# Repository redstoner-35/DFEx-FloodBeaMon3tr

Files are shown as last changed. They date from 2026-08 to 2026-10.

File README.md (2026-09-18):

powered by 35's Embedded Systems Inc. An Open-Source High Power Flood FlashLight Solution                                                                                                                        

### 概述

欢迎来到由Redstoner_35所开发的新一代高功率全恒流泛光手电**DFEX GT-X2,aka. DFEx-FloodBeaMon3tr**的完整设计开源仓库。DFEX GT-X2是基于全新的XTR HyperBoost HV GaN超高能效氮化镓升压恒流驱动所实现的大型手电参考设计。该手电作为低压增强型氮化镓功率器件在手电行业的首次应用，提供了以往硅基MOSFET方案无法企及的性能和功率密度。该手电方案具备行业首个基于氮化镓功率管的全恒流双相交错升压驱动，配合定制的超高光效灯珠，在21.5cm总长 10cm头径的娇小体型内提供高达 **162050LM光通 580K坎德拉光强** 的峰值出光性能，并且只需四节21700电池即可驱动。手电同时标配超低内阻的免工具可换电池电池架，内置140W双向充电方案。用户可以随心所欲地更换电池从而在户外实现极强的续航。并且该电池架具备行业主流的手电电池组方案所缺失的高级BMS功能和大电流主动均衡，使得电池子系统即使在用户可换电池和极高充放电倍率的条件下仍然能保障安全和稳定运行，电池子系统会通过其内置的BMS前端自动完成电池一致性管理，并允许用户随时查询电池的运行状况。这意味着用户可以装入电池后将手电当成电池棒手电全程不拆电池使用，并通过内置的140W快充模块在45分钟内完成快速充电（四节鹏辉能源60Q 84Wh的0-100%充电时间41分钟）。标配的高速风扇手柄DLC可以实现高达45000LM的持续常亮性能，提供无与伦比的常亮输出。

### 手电物理参数

+ 手电尺寸：21.5cm总长，10cm头径（未包括风扇手柄）
+ 手电重量：2070克（未包含风扇把手DLC） / 2355克（包含风扇把手DLC）
+ 电池组件：标配内置BMS和高性能主动均衡的电池架。用户可换电芯无需任何工具。
+ 电池架对电芯的需求：四节一致性良好的21700尺寸圆柱三元锂全极耳动力电芯。需具备至少100A的带温控截止放电能力（对于电芯的选择，请参考下方内容）。
+ 充放电方式：内置140W PD3.1/PD3.0多协议双向充放电子系统。该子系统支持标准和非标准PD3.0 Fix和PPS，以及PD3.1 EPR和AVS。用户也可拆下电池充电。

#### 出光性能（使用8032P Gen2）

+ Power模式极亮：25℃冷态OTF *162050LM光通 580K坎德拉光强* 持续1分钟,ANSI标准值 144965LM
+ ECO模式极亮：25℃冷态OTF *103100LM光通 410K坎德拉光强* 持续2分钟,ANSI标准值 98500LM

#### 出光性能（使用8032P Gen1）

+ Power模式极亮：25℃冷态OTF *153600LM光通 520K坎德拉光强* 持续1分钟,ANSI标准值 135360LM
+ ECO模式极亮：25℃冷态OTF *98500LM光通 390K坎德拉光强* 持续2分钟,ANSI标准值 95800LM

### 成品效果多视图

手电左侧视图
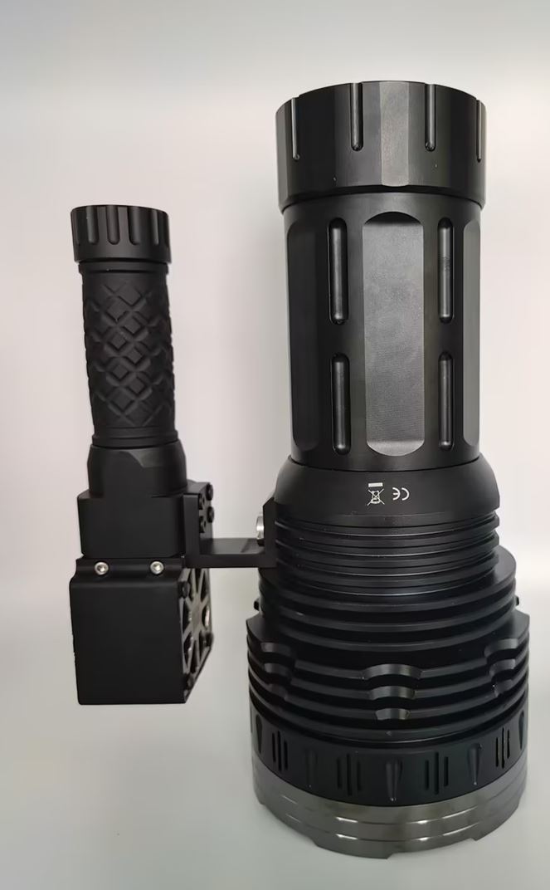
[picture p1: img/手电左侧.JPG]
成品侧面


手电按钮处正面视图
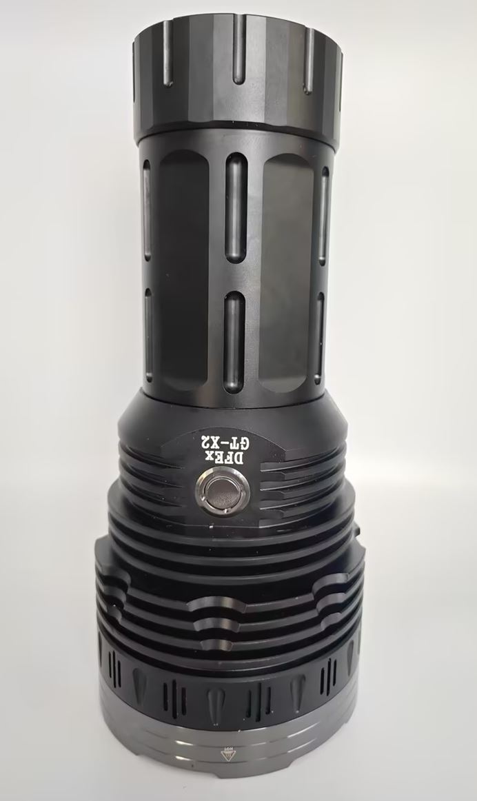
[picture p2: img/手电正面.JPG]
成品正面


手电头部正视图
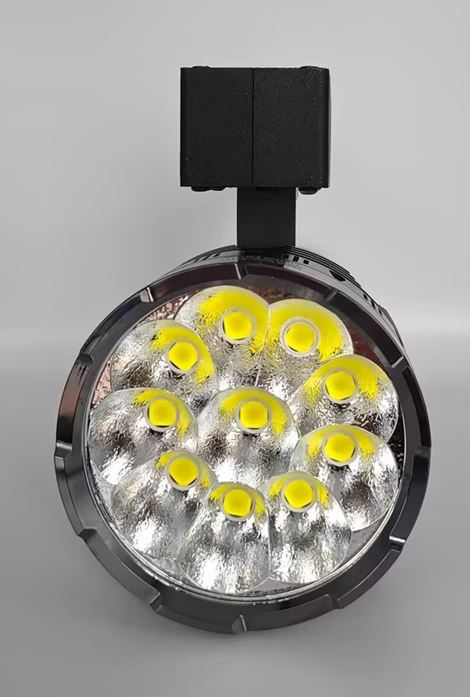
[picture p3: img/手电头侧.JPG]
手电灯珠侧正面


手电尾部视图
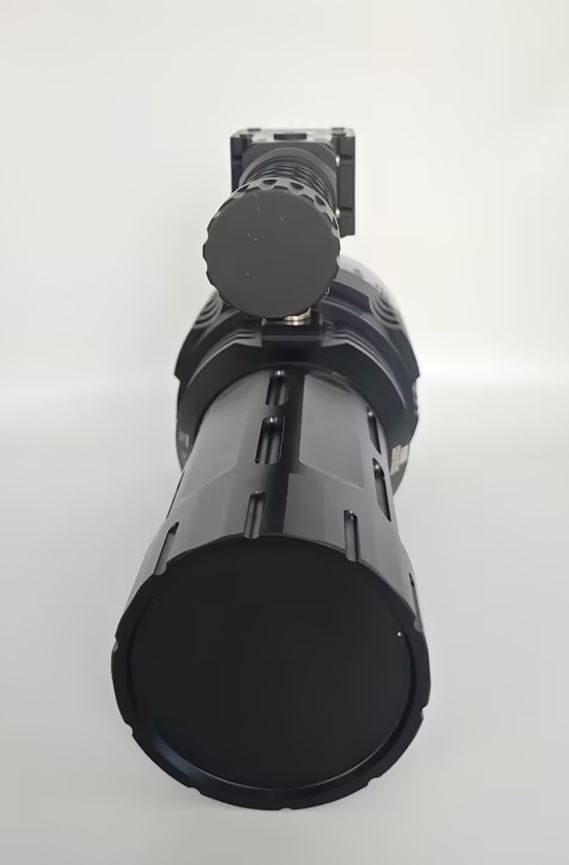
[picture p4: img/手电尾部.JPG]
手电尾部


### 复刻成本

该手电方案的从0开始复刻的成本极高。因此作者本人开源该项目的初衷是提供一个具有用户可换电池+大功率快充+全恒流超高能效驱动的手电设计参考作为抛砖引玉，期望行业上可以基于该设计作为范本诞生更多具有设计感和独创性的大型手电设计。如果您一定需要尝试复刻，那1PCS大致的复刻成本如下：

+ 机械部件部分：大约3000至4000元
+ 光学系统部分（包括反射器、玻璃等）：约500-1000元
+ 电子电路部分（包含驱动和电池架所有PCB和元器件）：约6000元
+ LED部分（包含定制灯珠打样和配套铜基板等）：5000元

### UI逻辑

为了降低UI学习成本，该手电总体的UI操作逻辑和上一代产品（也就是DFEx-GT96）基本保持一致。您可查看项目文件夹中的[UI逻辑手册](./GT-X2_UI%E9%80%BB%E8%BE%91.pdf)以查看主驱动的UI逻辑。并且该系统的电池组件加入了电池BMS功能，为了保证用户体验，强烈建议您阅读项目文件夹中的[BMS操作手册](./GT-X2_BMS%E9%80%BB%E8%BE%91.pdf)。

### 续航参数

在该手电方案发布前，作者已完成两台样机的试制并完成完整的续航测试，几乎覆盖所有挡位。对于该手电的完整续航数据和充电性能数据，您可查看项目中的[续航总表数据](GT-X2%E7%BB%AD%E8%88%AA%E6%B5%8B%E8%AF%95%E6%80%BB%E8%A1%A8.xlsx)。由于数据量巨大，因此readme中不再赘述。

### 复刻时电池的选择

这个手电的电池在工作过程中需要承受巨大的电流。在Power模式极亮的时候，电池最高电流可达105-110A。虽然固件具备有自适应输入MPPT算法，但是使用容量型或者半动力型电芯仍然可能会导致电芯出现不可逆的性能下降甚至损坏！因此为了保证您的安全，我仅推荐使用如下的电芯：

+ 鹏辉能源60Q：6000mAh超高倍率全极耳，也是作者在完成续航测试全过程时所使用的电池。
+ 新能安JP50P2：5000mAh版本的JP40，具有极强的放电能力，在牺牲了续航的前提下换来了更高的寿命。
+ 天鹏50XG：5000mAh超高倍率动力电池的标杆。
+ 天鹏40XG：支持90A持续放电，虽然续航惨不忍睹但是胜在便宜量大管饱。续航不够就多带电池。

### 风扇手柄DLC的说明

#### 风扇手柄操作逻辑

该风扇手柄DLC自身具备独立的操作按钮和系统,允许用户根据需要调整输出功率。风扇手柄本身包含自己的驱动和电池，不占用手电本身电池的电力和驱动面积。对于完整的操作逻辑，您可查看风扇手柄固件文件夹内的[风扇手柄操作说明](/%E5%9B%BA%E4%BB%B6/%E9%A3%8E%E6%89%87%E6%89%8B%E6%9F%84%E5%9B%BA%E4%BB%B6/Fan_Readme.md)。同时，为了实现极致的高常亮，作者在2026年9月3日的版本更新提供了43000RPM的超暴力风扇把手。该把手采用单锂升压设计，支持51W的超级风扇。为了实现如此高的输出功率，作者提供了全新的风扇驱动，操作逻辑和旧版略有修改。您克查看新版本风扇手柄固件文件夹内的[新版本风扇手柄操作说明](/%E5%9B%BA%E4%BB%B6/%E7%A6%81%E8%B5%9B%E7%BA%A7%E9%A3%8E%E6%89%87%E6%89%8B%E6%9F%84%E5%9B%BA%E4%BB%B6%E6%BA%90%E7%A0%81/Fan_Readme.md)。

#### 风扇手柄参数简介

相比于最初的版本，目前的工程文件已经包含了基于[东东海F1A的风扇手柄套件](https://item.taobao.com/item.htm?id=962803427853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)所实现的风扇手柄DLC。该风扇手柄通过专用的铝合金固定件连接至手电本体，具有极高的强度。风扇手柄外观如下图所示：

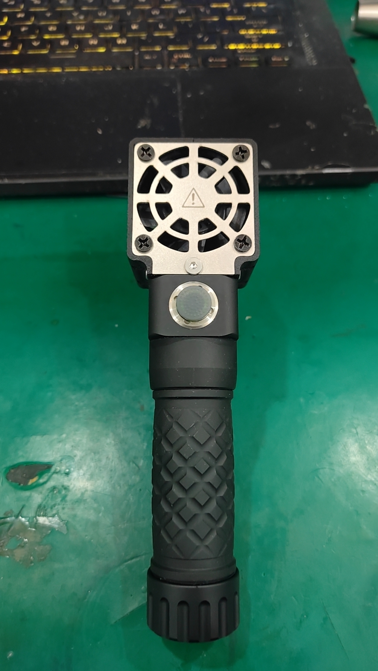
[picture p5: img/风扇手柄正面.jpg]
风扇手柄正面

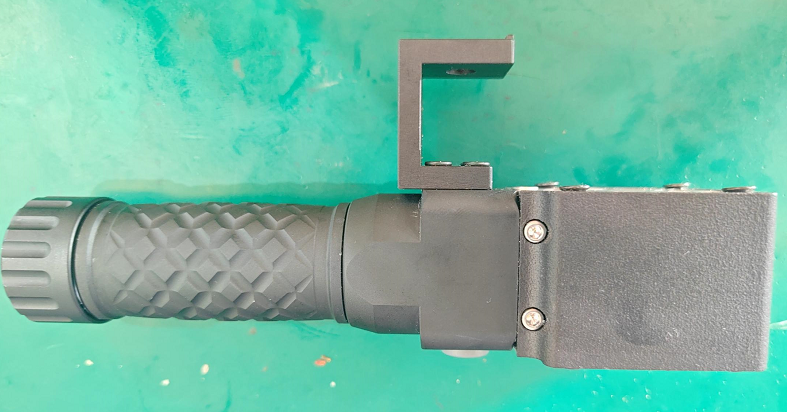
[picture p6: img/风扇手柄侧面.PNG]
风扇手柄侧面


该风扇手柄DLC基于自主开发的单锂升压12V风扇专用驱动以及单锂双向充电板，手柄样机所标配的风扇为建准的XF40281BX-Q035-S9H。转速高达34000RPM可以实现4.5万LM常亮不降档（2026年9月3日新增43000RPM的超暴力风扇手柄，吹称200克，支持5万常亮）。同时该风扇手柄的电池仓为免拆电池充电设计，旋下电池仓即可露出内置的双向USB-TypeC充电接口：

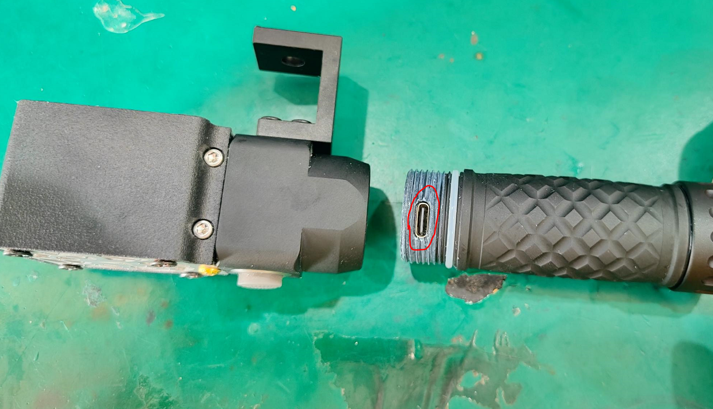
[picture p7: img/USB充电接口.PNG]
USB充电接口


该充电接口支持双向5V 2.4A充放电。最高12W的输入或输出功率。除了能给风扇手柄充电以外在应急情况下还可以反向为手机或其他设备应急充电。拆下手柄后即可看到手柄电池仓正面的充放指示灯：

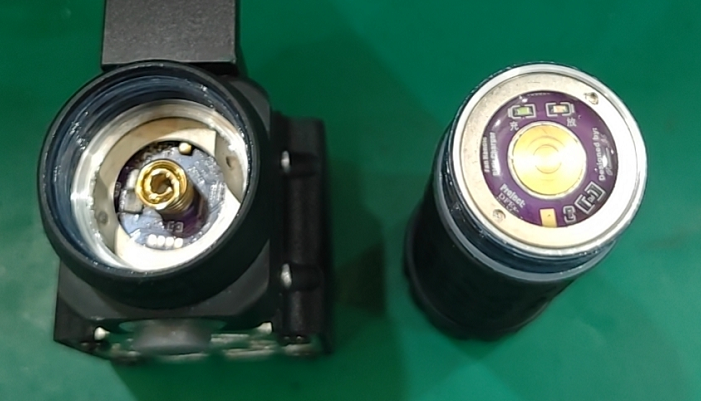
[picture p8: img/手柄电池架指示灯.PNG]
正面指示灯位置


手柄的电池仓一共包含两个指示灯，其中一个为放电和电池电量指示灯（图中紫色并且以放字标识的LED）以及一个充电状态指示灯（图中黄色以充字标识）负责指示电池的充放电状态。当电池仓首次装入电池时，电量指示灯会1Hz慢闪四秒表示电池安装后系统处于激活锁定模式。此时C口不能对外放电，需要连接充电器充电后才可放电。这两个指示灯不会同时点亮，显示的逻辑如下：

+ 充电指示灯：正在充电时0.5Hz慢闪，充满后持续点亮
+ 放电和电量指示灯：正在放电且电量正常时常亮，正在放电且电量不足后1Hz慢闪（充电或者放电结束拔下线缆后，电量指示灯仍然会保持点亮或闪烁一段时间，用户无需理会。30秒后电量指示灯会自然熄灭）

该风扇手柄采用专门的操作逻辑设计，和手电的原始UI基本一致，操作逻辑请参考如下内容：

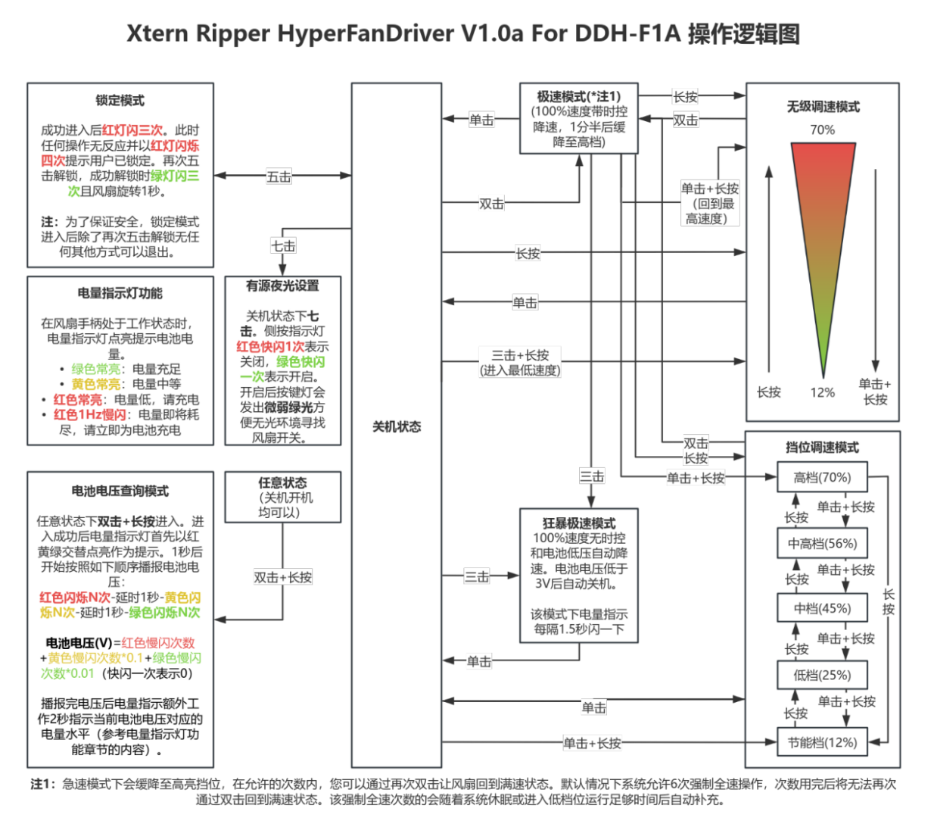
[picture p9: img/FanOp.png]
风扇手柄操作


#### 风扇手柄复刻说明

该风扇手柄复刻所需要的电路和机械部分已经在工程文件中体现，用户可以根据需要自行准备物料并复刻。对于部分未说明的物料请参考如下内容：

+ 风扇手柄半成品：该配件由东东海销售，可在[东东海淘宝店](https://item.taobao.com/item.htm?id=962803427853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)购买。
+ 风扇本体固定用粗牙螺丝：KB4*10规格，可在[固恒紧固件天猫店](https://detail.tmall.com/item.htm?id=610787499293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)购买.
+ 风扇固定装饰外壳和手柄壳料的固定螺丝：定制M3*6头径4.5非标内六角螺丝，可在[深奥普淘宝店](https://item.taobao.com/item.htm?id=770645615127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)购买
+ 4028暴力风扇：作者推荐使用建准的XF40281BX-Q035-S9H超高速暴力风扇获得足够的风量。该风扇可在[小红散热风扇](https://item.taobao.com/item.htm?id=959825954576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)淘宝店购买。

对于其余的机械部分物料，则参考如下说明：

+ 正背面风扇网罩不锈钢片：参考机械部分的[3D模型](/%E6%9C%BA%E6%A2%B0/%E9%A3%8E%E6%89%87%E6%89%8B%E6%9F%84%E5%A4%96%E6%A1%86/Step/40%E9%A3%8E%E6%89%87%E4%B8%8D%E9%94%88%E9%92%A2%E5%A4%B9%E7%89%87-%E6%94%B9%E7%89%88.STEP)找不锈钢加工厂进行处理。使用1mm 304不锈钢片激光切割后去毛刺抛光，并喷砂处理。
+ 风扇和手柄之间的固定壳：参考机械部分的[外部固定壳模型](/%E6%9C%BA%E6%A2%B0/%E9%A3%8E%E6%89%87%E6%89%8B%E6%9F%84%E5%A4%96%E6%A1%86/Step/40%E9%A3%8E%E6%89%87%E5%A4%96%E6%A1%8623%E6%97%A5.STEP)找3D打印商家进行处理。因该部件型面较为复杂因此建议选用PA6材质进行SLS激光烧结或MJF工艺等无需支撑的工艺制程进行3D打印。

电子部分的物料和具体打样文件（如PCB等）您可以参考PCB文件夹内相关的子目录并进行打样。

### 工程结构

该开源手电项目的工程分为三个文件夹，分别放置手电的电子、机械和固件部分的原始资料：

+ PCB：该文件夹放置手电所有功能模块的电路板文件
+ 固件：该文件夹放置手电种各个功能模块所使用到的固件文件
+ 机械：该文件夹放置手电外壳、电池架等东西的机械建模文件

### 复刻的详细指导

因为该项目仍处于刚刚完成的状态，相关文档的编写仍在进行中。对于需要注意的部分以及供应商链接您可以参考每个子文件夹内的注意事项文档。对于您在复刻中不明白的部分，您可使用Github issue。如果需要了解该手电方案的设计记录全过程，您可前往BLF论坛中作者本人攥写的[记录帖子](https://budgetlightforum.com/t/fully-regulated-flood-search-light-build-dfex-gt-x2-open-source-wip/234458)以获得部分组装过程的照片和流程并作为复刻的参考。

### 致谢

该项目于今年四月初启动，持续了近五个月。所有的电子部分的电路设计、电池机架的整体结构、部分外壳设计、完整的性能和续航测试，以及光学部分（如LED）的设计和与相关供应商的协调均由作者独立完成（redstoner_35）。在这个过程中，我得到了几位重要朋友和家人的经济和精神支持，在我濒临放弃时给予了帮助。我非常感谢**KIPA、思绪和我的家人**给予的精神和经济支持，也感谢[飘落396](https://space.bilibili.com/694332529?spm_id_from=333.337.0.0)在CNC供应商寻找对接沟通和外壳结构设计方面的支持。这种支持是确保该项目持续推进和最终成功的关键力量。与此同时，作为一名DIY爱好者，我一直致力于挑战自己的能力极限并努力实现高质量的顶级解决方案，并致力于令顶尖方案从研发端走入千家万户。因此，作者本人将该项目的所有生产资料开源于本仓库，并希望有厂商可以基于此方案提供实际的产品。

----------------------------------------------------------------------------------------------------------------------------------
© redstoner_35 @ 35's Embedded Systems Inc.  2026

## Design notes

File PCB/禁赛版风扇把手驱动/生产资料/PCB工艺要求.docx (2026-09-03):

板厚：1.6mm

层数：4层

外形层：请以Keepout Layer（PCB1_keep-out.gbr文件）内的轮廓作为外形层！

外层线路铜厚：2Oz

内层线路铜厚：1Oz （铜厚不能缩水否则发热大！达不到标称性能！有钱的话内层也2Oz性能最好）

阻焊颜色：蓝色

丝印颜色：白色 （颜色你想咋样都行，这里是参考值）

焊盘喷镀：2U沉金（外圈存在导电接触不能喷锡，否则接触不良！！）

阻焊覆盖：过孔塞树脂+电镀盖帽（不能过孔盖油，否则焊接不良！！）

板材TG值：155

层压顺序需要选择指定层压顺序，请勿更改！层压顺序需要严格按照如下要求进行！

L1（顶层线路）：PCB1_copper_signal_top.gbr

L2（中间层线路1）：PCB1_copper_plane_1.gbr

L3（中间层线路2）：PCB1_copper_signal_1.gbr

L4（底层线路）：PCB1_copper_signal_bot.gbr

该PCB对层压结构没有要求，按照嘉立创（JLCPCB）对应板厚和铜厚随机指定的默认的层压结构就可以了。

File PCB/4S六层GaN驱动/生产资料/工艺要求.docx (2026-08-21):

板厚：1.6mm

层数：6层

外形层：请以Keepout Layer（pcb2_keepout.gbr文件）内的轮廓作为外形层！

外层线路铜厚：2Oz

内层线路铜厚：2Oz （铜厚不能缩水否则发热大）

阻焊颜色：蓝色

丝印颜色：白色 （颜色你想咋样都行，这里是参考值）

焊盘喷镀：2U沉金 （必须这么厚否则容易接触不良！）

阻焊覆盖：过孔塞树脂+表面电镀填平（JLC六层默认工艺，不需要加钱）

板材TG值：170

板材供应商要求：生益 （高温和高弹力条件下运行，必须TG170高品质板材否则驱动PCB会变形导致功能异常）

层压顺序需要选择指定层压顺序，请勿更改！层压顺序需要严格按照如下要求进行！

L1（顶层线路）：pcb2_copper_signal_top.gbr

L2（中间层线路1）：pcb2_copper_plane_1.gbr

L3（中间层线路2）：pcb2_copper_signal_1.gbr

L4（中间层线路3）：pcb2_copper_signal_2.gbr

L5（中间层线路4）：pcb2_copper_plane_2.gbr

L6（底层线路）：pcb2_copper_signal_bot.gbr

层压顺序错误（特别是内层）会引起严重的信号干扰和噪声问题导致驱动炸机！务必确认生产稿检查内层顺序！！

该PCB对层压结构没有要求，按照嘉立创（JLCPCB）对应板厚和铜厚随机指定的默认的层压结构就可以了

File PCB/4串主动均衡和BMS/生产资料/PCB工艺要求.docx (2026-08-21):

板厚：1.0mm （别搞错了！）

层数：4层

外形层：请以Keepout Layer（pcb1_keep-out.gbr文件）内的轮廓作为外形层！

外层线路铜厚：1Oz

内层线路铜厚：1Oz （铜厚不能缩水否则发热大）

阻焊颜色：绿色

丝印颜色：白色 （颜色你想咋样都行，这里是参考值）

焊盘喷镀：没钱就喷锡，有钱就1U沉金，丰俭由人

阻焊覆盖：过孔盖油

板材TG值：155

层压顺序需要选择指定层压顺序，请勿更改！层压顺序需要严格按照如下要求进行！

L1（顶层线路）：pcb1_copper_signal_top.gbr

L2（中间层线路1）：pcb1_copper_plane_1.gbr

L3（中间层线路2）：pcb1_copper_signal_1.gbr

L4（底层线路）：pcb1_copper_signal_bot.gbr

该PCB对层压结构没有要求，按照嘉立创（JLCPCB）对应板厚和铜厚随机指定的默认的层压结构就可以了

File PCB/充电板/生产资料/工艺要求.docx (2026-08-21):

板厚：1.2mm

层数：4层

外形层：请以Keepout Layer（PCB1_Keep-out.gbr文件）内的轮廓作为外形层！

外层线路铜厚：1Oz

内层线路铜厚：1Oz （铜厚不能缩水否则发热大）

阻焊颜色：绿色

丝印颜色：白色 （颜色你想咋样都行，这里是参考值）

焊盘喷镀：没钱就喷锡，有钱就1U沉金，丰俭由人

阻焊覆盖：过孔盖油

板材TG值：135

层压顺序需要选择指定层压顺序，请勿更改！层压顺序需要严格按照如下要求进行！

L1（顶层线路）：PCB2_Copper_Signal_Top.gbr

L2（中间层线路1）：PCB2_Copper_Plane_1.gbr

L3（中间层线路2）：PCB2_Copper_Signal_1.gbr

L4（底层线路）：PCB2_Copper_Signal_Bot.gbr

该PCB对层压结构没有要求，按照嘉立创（JLCPCB）对应板厚和铜厚随机指定的默认的层压结构就可以了

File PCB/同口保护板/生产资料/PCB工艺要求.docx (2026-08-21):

板厚：1.6mm

层数：4层

外形层：请以Keepout Layer（PCB1_Keep-out.gbr文件）内的轮廓作为外形层！

外层线路铜厚：2Oz

内层线路铜厚：2Oz （超大电流，铜厚不能缩水否则发热巨大没法用）

阻焊颜色：蓝色

丝印颜色：白色 （颜色你想咋样都行，这里是参考值）

焊盘喷镀：没钱就喷锡，有钱就1U沉金，丰俭由人

阻焊覆盖：过孔塞树脂+电镀盖帽

板材TG值：155

层压顺序需要选择指定层压顺序，请勿更改！层压顺序需要严格按照如下要求进行！

L1（顶层线路）：PCB1_Copper_Signal_Top.gbr

L2（中间层线路1）：PCB1_Copper_Plane_1.gbr

L3（中间层线路2）：PCB1_Copper_Signal_1.gbr

L4（底层线路）：PCB1_Copper_Signal_Bot.gbr

该PCB对层压结构没有要求，按照嘉立创（JLCPCB）对应板厚和铜厚随机指定的默认的层压结构就可以了

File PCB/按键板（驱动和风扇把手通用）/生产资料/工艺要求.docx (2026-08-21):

板厚：1.0mm

层数：2层

外形层：请以Keepout Layer（PCB3_Keep-out.gbr文件）内的轮廓作为外形层！

线路铜厚：1Oz

阻焊颜色：白色

丝印颜色：黑色 （建议使用白油黑字，自带反光效果增强按键灯亮度）

焊盘喷镀：喷锡就可以

阻焊覆盖：过孔盖油

板材TG值：135

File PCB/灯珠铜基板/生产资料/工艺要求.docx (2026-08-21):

## 铜基板总体工艺要求

线路层铜厚：6Oz

成品板厚：3mm

阻焊层颜色：黑色

丝印层颜色：白色

焊盘喷镀：1U沉金

特殊工艺要求：下图中绿色圈起的固定螺丝孔做喇叭孔。

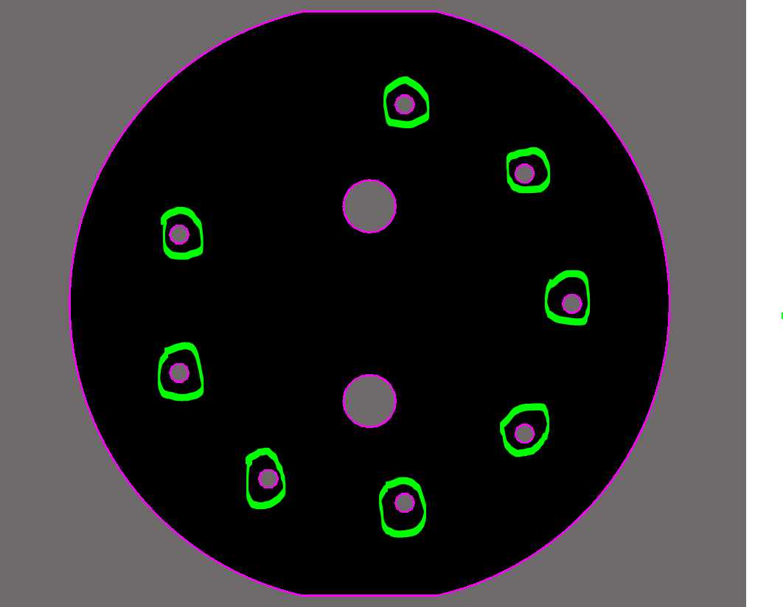
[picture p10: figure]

喇叭孔参数如下：

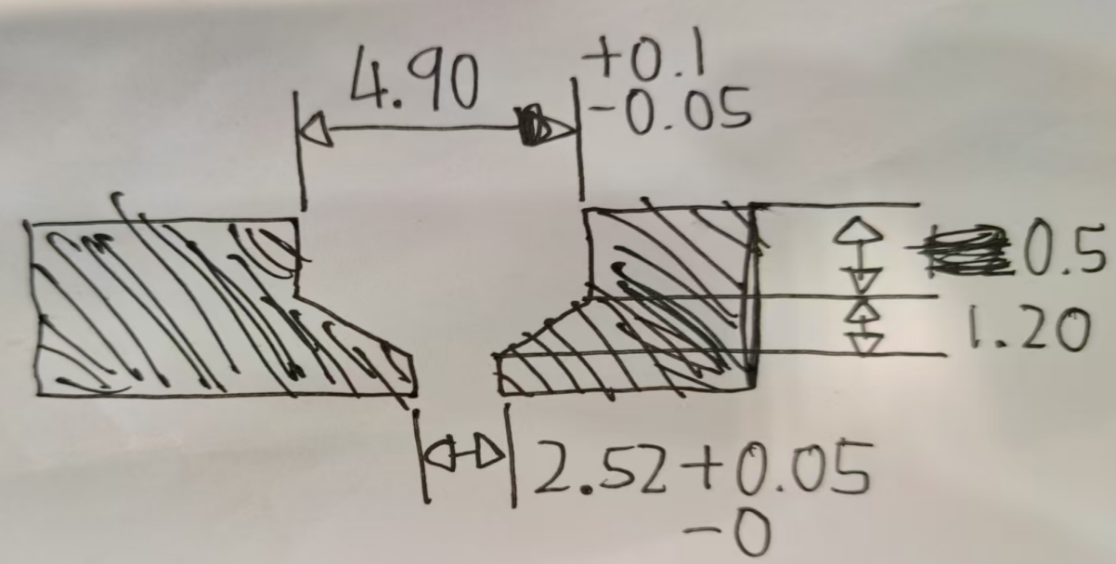
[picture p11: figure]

生产拼板位：请注意使用下图所示的拼板位置进行拼板，不得破坏其他区域的外形否则基板无法安装至外壳内。

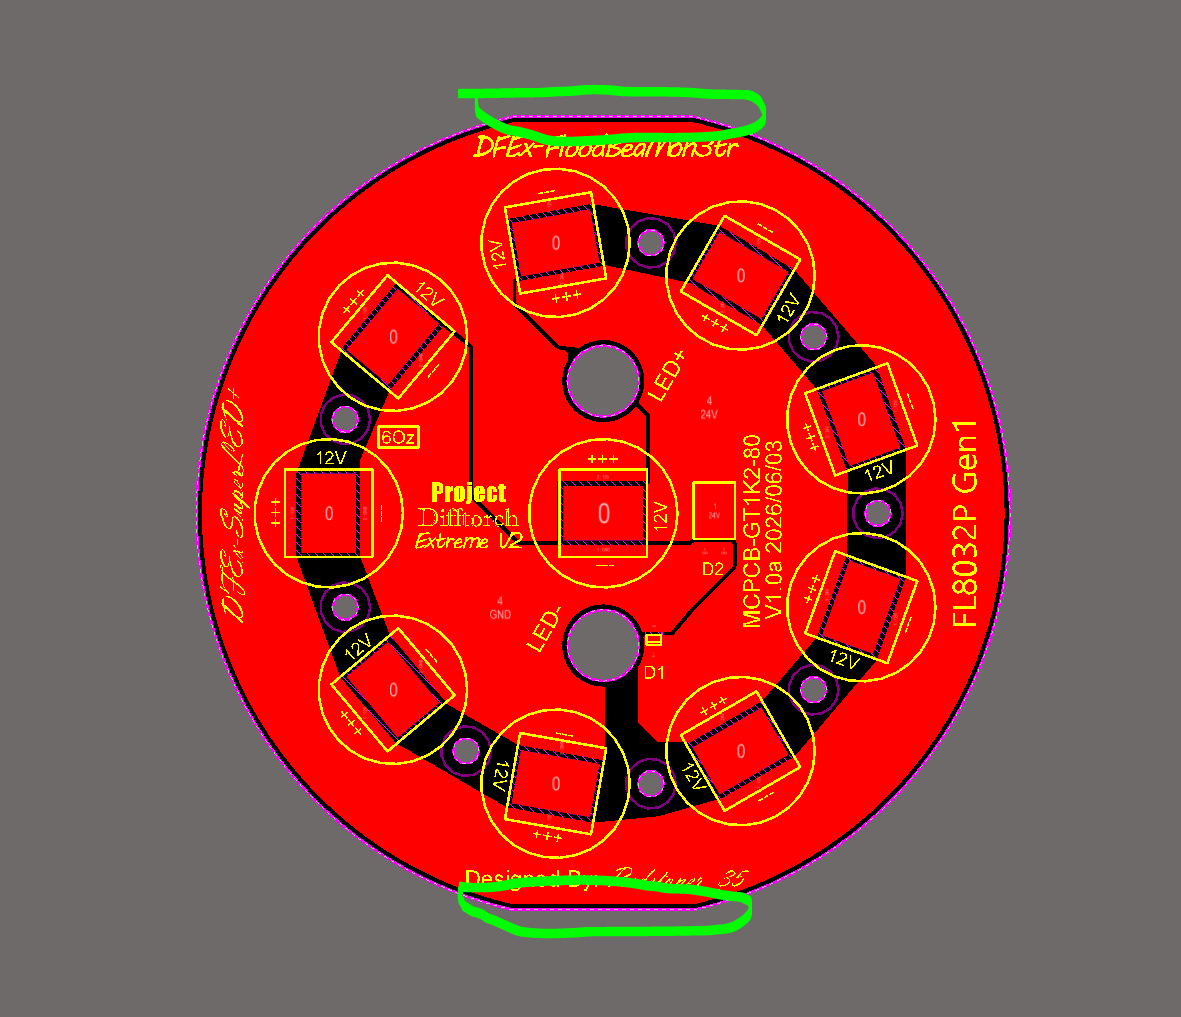
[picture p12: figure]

基板耐温和环保要求：基板材料应符合RoHs标准，可以承受1次标准无铅高温锡膏的红外回流焊过程，阻焊层不得脱落，线路层和铜基层不得分层。

参考拼板方式如下图：

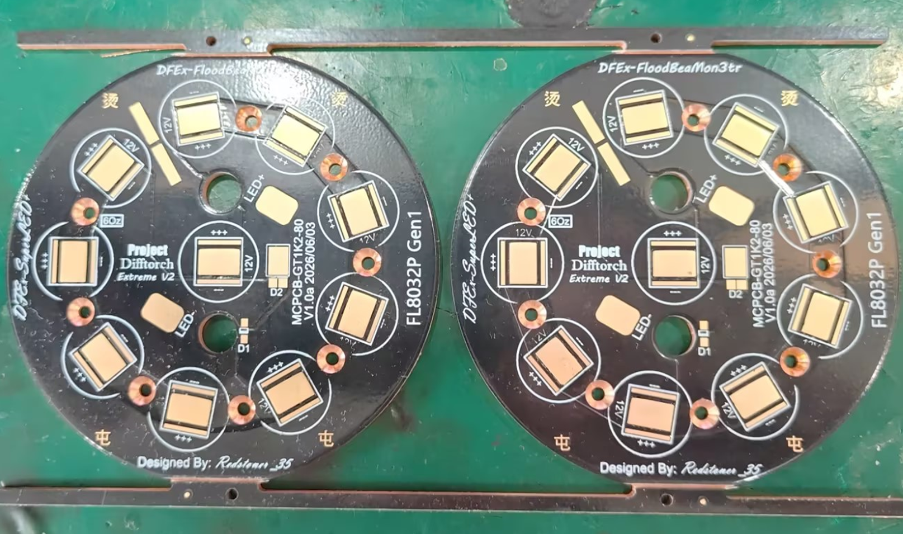
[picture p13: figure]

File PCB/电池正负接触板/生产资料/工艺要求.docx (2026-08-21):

板厚：1.6mm

层数：2层

总拼板款数：2款

每款板PCS数：2PCS

是否包含工艺边：是

拼板方式：V-CUT

拼板VCUT标识层：请以Mechanical 3层（电池接触板拼板_Mechanical_3.gbr）所标识的V-CUT线作为切割起始点！

外形层：请以Keepout Layer（电池接触板拼板_Keep-out.gbr文件）内的轮廓作为外形层！

线路铜厚：5Oz （有钱建议6Oz损耗更低，5Oz最低）

阻焊颜色：蓝色

丝印颜色：白色 （颜色你想咋样都行，这里是参考值）

焊盘喷镀：没钱就喷锡，有钱就1U沉金，丰俭由人

阻焊覆盖：过孔盖油

板材TG值：至少155

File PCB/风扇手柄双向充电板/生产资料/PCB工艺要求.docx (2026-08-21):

板厚：1.6mm

层数：4层

外形层：请以Keepout Layer（PCB1_Keep-out.gbr文件）内的轮廓作为外形层！

外层线路铜厚：1Oz

内层线路铜厚：0.5Oz （内层0.5Oz就够，当然你有钱的话1Oz最好）

阻焊颜色：黑色

丝印颜色：白色 （颜色你想咋样都行，这里是参考值）

焊盘喷镀：至少1U沉金，最好2U否则接触不良

阻焊覆盖：过孔塞树脂+电镀盖帽

板材TG值：135

层压顺序需要选择指定层压顺序，请勿更改！层压顺序需要严格按照如下要求进行！

L1（顶层线路）：PCB1_Copper_Signal_Top.gbr

L2（中间层线路1）：PCB1_Copper_Plane_1.gbr

L3（中间层线路2）：PCB1_Copper_Signal_1.gbr

L4（底层线路）：PCB1_Copper_Signal_Bot.gbr

该PCB对层压结构没有要求，按照嘉立创（JLCPCB）对应板厚和铜厚随机指定的默认的层压结构就可以了

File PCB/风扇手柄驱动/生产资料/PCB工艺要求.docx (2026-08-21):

板厚：1.6mm

层数：4层

外形层：请以Keepout Layer（PCB2_Keep-out.gbr文件）内的轮廓作为外形层！

外层线路铜厚：1Oz

内层线路铜厚：1Oz （内层不能缩水）

阻焊颜色：黑色

丝印颜色：白色 （颜色你想咋样都行，这里是参考值）

焊盘喷镀：至少1U沉金，最好2U否则接触不良

阻焊覆盖：过孔塞树脂+电镀盖帽

板材TG值：155

层压顺序需要选择指定层压顺序，请勿更改！层压顺序需要严格按照如下要求进行！

L1（顶层线路）：PCB2_Copper_Signal_Top.gbr

L2（中间层线路1）：PCB2_Copper_Plane_1.gbr

L3（中间层线路2）：PCB2_Copper_Signal_1.gbr

L4（底层线路）：PCB2_Copper_Signal_Bot.gbr

该PCB对层压结构没有要求，按照嘉立创（JLCPCB）对应板厚和铜厚随机指定的默认的层压结构就可以了

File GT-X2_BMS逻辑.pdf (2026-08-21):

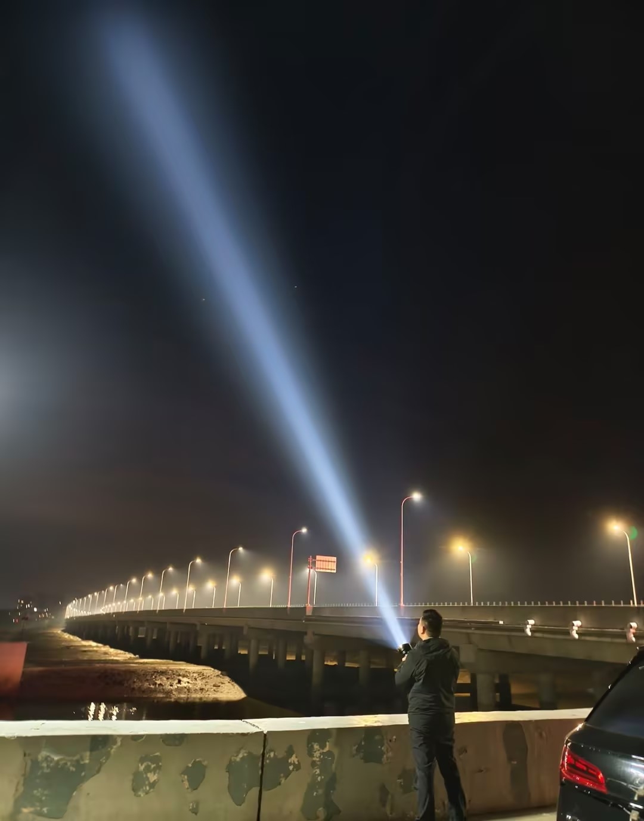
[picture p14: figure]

# DFEx-GTX2 高功率泛光搜索手电

# 电池架 S-BMS 操作手册

## 由 redstoner_35 编写 仅供参考

## BMS 基础操作

## 电池棒操作界面

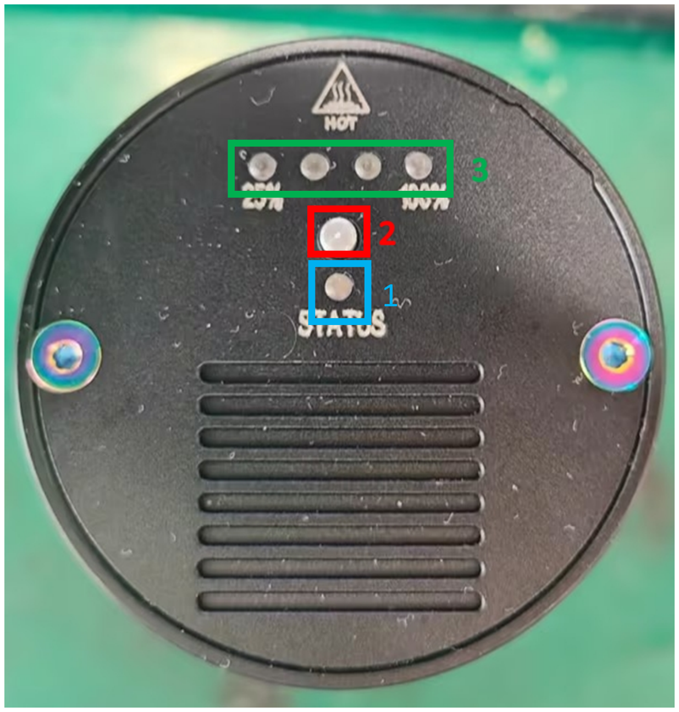
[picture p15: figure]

电池棒操作界面的各个部分的功能如下所示：

序号 | 部件名称 | 功能
1 | BMS 状态指示灯 | 在充放电时亮起指示电池当前的健康状况，并且在用户操 作时按照逻辑播报如电池总电压、指定电池的电压、电池 压差和一致性、电池和 BMS 温度等电池健康状况数据。
2 | BMS 操作按钮 | 允许用户唤醒 BMS 以及充放电系统，并且执行 BMS 相关的 查询和设置操作。同时，在安装了电池后，该按钮提供电 池激活功能以解锁保护板，允许保护板对外输出。
3 | 电池电量和充放 电状态指示灯 | 该组指示灯在充放电阶段提供充放电状态的指示，以及电 池电量的指示。当充放电系统存在异常时，四盏指示灯将 同时闪烁。

## 唤醒 BMS 和充放电系统

为了节省电力，BMS 默认处于非活动状态。此时充放电系统和 BMS 模块处 于深度休眠，仅消耗极少的电力。若用户需要查询电池状态或需要对外放电，可 以通过单击 BMS 操作按钮，唤醒 BMS 和充放电系统。在按下按钮后，BMS 将会 由休眠转为活动状态，在通过了自检后点亮 BMS 状态灯，等候用户操作。 同时，该系统具备自动唤醒功能。当用户连接 USB-C 线缆尝试为手电的电池 进行充电以及连接到手机/笔记本电脑等支持 OTG 的设备尝试用手电为其供电时， BMS 将立即自动唤醒进入工作状态，并且开启充放电功能。 需要注意的是，若您连接的被供电设备（如小风扇）不支持 OTG 功能，则连 接 USB 线缆后，设备将保持在睡眠状态且 BMS 和对外放电系统关闭。此时您需 要手动单击 BMS 按键以唤醒充放电功能。

## BMS 上电自检和自检故障排除

为了保证 BMS 自身的正确性，在 BMS 被唤醒（无论是用户手动唤醒还是由充放电事件 自动唤醒）后，BMS 首先会对自身进行上电自我测试和初始化。初始化结束后才会进入用 户模式。若初始化出现异常以及检测到电池存在问题，则会通过在 BMS 指示灯上显示指定 的序列以提示用户。指示灯序列提示如下：

指示灯序列 | 故障类型 | 可能出现的问题 | 用户应采取的操作
红色 8Hz 快 闪 | 严重 | BMS 主处理器无法正确初始化采 集模拟前端或出现通信故障 | 长按 BMS 按键 1 秒，观察问 题是否重现。若重现请送修。
黄色 8Hz 快 闪 | 严重 | BMS 主处理器无法采集到电池内 部温度信息，可能是热敏电阻损坏 或模拟前端故障引起。 | 检查电池是否过度压迫电池 架中部的 NTC 热敏电阻。长 按 BMS 按键 1 秒，观察问题 是否重现。若重现请送修。
黄色慢速闪 烁一定次数 后红色慢闪 几秒最后熄 灭，熄灭后 不再亮起 | 警告 | BMS 初始化成功，但检测到某节 电池电压异常过低，因此进入关机 保护状态。该问题可能是电池架中 某节电池接触不良、装反或损坏引 起。 | 闪烁次数表示电压异常的电 池所在的位置。请取下电池 并擦干净电池架的触点，检 查电池的极性和电压后以正 确的方式装回。若仍未解决， 请送修。
红黄绿或绿 黄红的交替 闪烁，然后 跟着一大堆 看不明白的 慢闪 | 警告 | BMS 初始化成功且通过自检，但 检测到电池架上的电池一致性极 差，存在巨大的电压差。因此 BMS 发出一致性警告，提醒您需要查看 并处理电池的一致性故障。 | 该组闪烁的内容和后续章节 中关于电池一致性查看的内 容完全一致。请参考后续章 节定位故障电池。

若 BMS 正常通过自检且没有警告发生，此时 BMS 的状态灯将短暂点亮，并指示电池一 致性状况，同时电池电量指示灯组也将点亮，表示充放电系统已就绪，您可以开始对电池进 行充电或放电。

## BMS 指示灯状态表（通过自检后）

在通过自检后，BMS 将进入正常工作模式，此时 BMS 的状态指示灯将通过颜色和状态 指示当前电池的一致性以及 BMS 所处的状态。在 BMS 待机、充放电中以及均衡中，系统会 通过指示灯颜色指示电池一致性，关于一致性的指示如下：

指示灯颜色 | 电池一致性状况
绿色 | 电池一致性不错（压差小于 40mV）
黄色 | 电池一致性一般（压差在 40-150mV 之间）
红色 | 电池一致性极差（压差大于 200mV）此时需要人为干预。

同时，BMS 会通过指示灯的闪烁、常亮等方式以及带颜色的特殊闪烁指示 BMS 的状态：

指示灯颜色 | 指示灯闪烁状态 | 系统当前状态
参考上表 | 每 5 秒闪一下 | BMS 处于待机状态，主动均衡和充放电系统处于关闭状态， 将持续监控电池状况并等待用户操作和充放电输入。
参考上表 | 1Hz 慢闪 | BMS 处于活动状态。此时 BMS 正在运行主动均衡以修正电 池一致性误差。
参考上表 | 常亮 | BMS 处于活动状态，系统正在进行充放电中，未启动主动 均衡。
红色 | 4Hz 快闪 | BMS 检测到持续的通信超时。经过多次重试仍无法和 AFE 进行通信，此时将进入故障保护模式。
黄色 | 4Hz 快闪 | BMS 检测到温度采集系统故障。经过多次重试仍无法正确 获取温度信息，已进入保护模式。
黄色 | 每 5 秒 快 闪 三 下，循环 | BMS 进入过充保护模式，由于电池一致性太差导致充电时 单体出现过度充电。此时 BMS 将禁止充电并强制启动均衡 以释放并转移过度充电的电池中的能量。
红色 | 每 5 秒 快 闪 三 下，循环 | BMS 进入过温或或低温充放电保护模式。由于电池本身温 度过高或过低，BMS 将禁止充放电。请等待电池回归到正 常温度后故障将自动解除。
绿色 | 每 5 秒 快 闪 三 下，循环 | 因为用户操作，BMS 进入受用户指令的禁充禁放模式。此 时单击 BMS 按键即可退出用户禁充模式并恢复正常充放 电。

## 充放电系统指示灯状态表

该电池架包含四个用于指示系统充放电状态的指示灯。该组指示灯除了指示电池的大概 电量外，还负责指示充放电系统的运行状况。对于当前系统的电池电量，在待机以及放电状 态，充放电系统会通过指示灯点亮的个数显示大致的电池电量，指示规则如下：

25%指示灯 | 50%指示灯 | 75%指示灯 | 100%指示灯 | 电池电量
快闪 | 灭 | 灭 | 灭 | 小于 10%，接近耗尽
亮 | 灭 | 灭 | 灭 | 10%至 25%之间
亮 | 亮 | 灭 | 灭 | 25%至 50%之间
亮 | 亮 | 亮 | 灭 | 50%至 75%之间
亮 | 亮 | 亮 | 亮 | 75%到 100%之间

若系统的充电功能处于活动状态，以及进入故障、处于休眠等特殊状态，系统会通过指 示灯闪烁和常亮的方式指示当前处于的状态。指示规则可以查看下表：

25%指示灯 | 50%指示灯 | 75%指示灯 | 100%指示灯 | 系统状态
灭 | 灭 | 灭 | 灭 | 充放电系统休眠中，您 可单击 BMS 按键唤醒
1Hz 慢闪 | 灭 | 灭 | 灭 | 系统充电中，当前电量 0-25%
亮 | 1Hz 慢闪 | 灭 | 灭 | 系统充电中，当前电量 25-50%
亮 | 亮 | 1Hz 慢闪 | 灭 | 系统充电中，当前电量 50-75%
亮 | 亮 | 亮 | 1Hz 慢闪 | 系统充电中，当前电量 75-100%
亮 | 亮 | 亮 | 亮 | 系统已充满，请尽快拔 下充电线。
2Hz 快闪 | 2Hz 快闪 | 2Hz 快闪 | 2Hz 快闪 | 由于 BMS 检测到异常 状态，充放电系统已被 禁用。请查看 BMS 状态 指示灯以了解问题的原

# 因。 关闭 BMS

该 BMS 具备自动关机功能，当 BMS 处于非活动状态（没有均衡和充放电操作）超过 1 分钟后，BMS 将会自动关机以节约电力。同时如果 BMS 检测到电池架中有某节电池电压过 低，为了避免电池过度放电，BMS 也会强制关机，并且用红色慢闪若干次作为提示。 若您需要手动关闭 BMS，请在充放电系统指示灯熄灭后长按 BMS 按键 2 秒，此时 BMS 指示灯将以黄色快闪三下，然后 BMS 将返回深度休眠状态，几乎不消耗电力。

## BMS 电池健康查询操作

## 查询操作下电池电量水平的指示

- 绿色常亮：电池电量充足
- 黄色常亮：电池电量较为充足
- 红色常亮：电池电量不足，请尽快充电
- 红色慢闪：电池电量严重不足，请立即充电（此时手电的可用挡位和功能将会被限制）

## 查询电池总电压

BMS 在待机状态下双击进入。当进入电量查询模式后 BMS 指示灯首先将会以红黄绿依 次点亮的方式（若电池电压低于 10.00V，则系统将会切换到高精度显示模式以 0.01V 精度 显示电量。此时先导提示将变为绿黄红的顺序）作为先导提示，提示用户即将开始显示电 池电压和电量。延迟 1 秒后将通过红色，黄色和绿色的指定次数的慢速闪烁（如果快速闪烁 一次，则表示该数据位为 0）提示用户当前的电池电压，播报完电池当前电压后，BMS 将会 在延迟 2 秒后通过后续的长亮(或者慢闪)提示用户当前电池电压对应的总体电量水平(参考 本条目第一小节的内容)，对于电池具体电压播报的计算方式请参考如下内容：

- 99.9V显示模式：红色闪烁次数x10+黄色闪烁次数+绿色闪烁次数x0.1=当前电池电压(V)， 例如 红色慢闪 1 次-黄色快闪 1 次-绿色慢闪 4 次 表示电池电压为 10x1+0+4x0.1=10.4V。
- 9.99V 高精度显示模式：红色闪烁次数+黄色闪烁次数 x0.1+绿色闪烁次数 x0.01=当前电 池电压(V)，例如 红色慢闪 8 次-黄色慢闪 1 次-绿色慢闪 3 次 表示当前电池电压为

## 8+1*0.1+3x0.01=8.13V。 查询电池内部温度

BMS 在待机状态下三击进入。当进入温度查询模式后 BMS 指示灯首先将会以红黄绿依 次点亮的方式（若手电当前处于极寒环境，手电本身温度低于 0 摄氏度时，先导提示将变 为绿黄红的顺序）作为先导提示，提示用户即将开始显示当前电池的温度。延迟 1 秒后 BMS 将通过红色和黄色的指定次数的慢速闪烁（如果快速闪烁一次，则表示该数据位为 0）提示 用户当前的电池内部温度。在播报完当前电池的内部温度数值后，BMS 将会在延迟 2 秒后 通过后续的长亮(或者慢闪)提示用户当前内部温度数值所对应的电池温度情况。对于温度显 示的计算方式请参考如下内容：

- 播报完毕后绿色常亮：当前电池温度良好
- 播报完毕后黄色常亮：当前电池温度较高，需要注意散热
- 播报完毕后红色常亮：当前电池温度极高，请立即为电池降温以避免危险
- 电池内部温度(℃)=红色闪烁次数 x10+黄色闪烁次数，例如`红色慢闪 4 次-黄色快闪 1 次 `表示当前电池的温度为 40℃

## 查询 BMS 板端的温度

BMS 在待机状态下六击进入。当进入温度查询模式后 BMS 指示灯首先将会以红黄绿依 次点亮的方式（若手电当前处于极寒环境，手电本身温度低于 0 摄氏度时，先导提示将变 为绿黄红的顺序）作为先导提示，提示用户即将开始显示当前电池的温度。延迟 1 秒后 BMS 将通过红色和黄色的指定次数的慢速闪烁（如果快速闪烁一次，则表示该数据位为 0）提示 用户当前的 BMS 板端的温度。在播报完当前 BMS 板端的温度数值后，BMS 将会在延迟 2 秒 后通过后续的长亮(或者慢闪)提示用户当前 BMS 板端温度数值所对应的 BMS 温度情况。对 于温度显示的计算方式请参考如下内容：

- 播报完毕后绿色常亮：当前 BMS 温度良好
- 播报完毕后黄色常亮：当前 BMS 温度较高，需要注意散热
- 播报完毕后红色常亮：当前 BMS 温度极高，需要风扇主动为电池架顶部散热改善 BMS 的温度
- BMS 板端的温度(℃)=红色闪烁次数 x10+黄色闪烁次数，例如`红色慢闪 5 次-黄色快闪 1 次`表示当前 BMS 板端的温度为 50℃

## 查询单节电芯的电压

BMS 在待机状态下通过指定次数的连续多击，并在多击后紧跟一次 2 秒以上的长按进 入，例如连续四次单击后立即长按 2 秒表示查询电池架上第四节电池的电量和电压。 当成功进入单体电量查询模式后 BMS 指示灯首先将会以绿黄红依次点亮的方式作为先 导提示，提示用户即将开始显示该电池的电压和电量。延迟 1 秒后将通过红色，黄色和绿色 的指定次数的慢速闪烁（如果快速闪烁一次，则表示该数据位为 0）提示用户当前的电池电 压，播报完电池当前电压后，BMS 将会在延迟 2 秒后通过后续的长亮(或者慢闪)提示用户当 前单体电池电压对应的电量水平(参考本条目第一小节的内容)，对于单体电池具体电压播报 的计算方式请参考如下内容：

- 红色闪烁次数+黄色闪烁次数 x0.1+绿色闪烁次数 x0.01=当前电池电压(V)，例如 红色慢 闪 4 次-黄色慢闪 1 次-绿色慢闪 3 次 表示当前电池电压为 4+1*0.1+3x0.01=4.13V。 查询电池组的精确压差

该 BMS 具备电池一致性状况播报功能。该播报功能除了可以手动唤起外，当 BMS 上电 自检期间，如果检测到压差极大则会自动在自检结束后唤起播报作为警告。该警告机制会提 醒您电池一致性存在严重问题，这通常是由于电池组内某一节电芯已严重衰减，濒临崩溃导 致。若警告出现，您需要尽快处理以避免其余正常的电芯更进一步被故障电芯牵连而损坏。

对于在 BMS 操作状态下手动进入，则需要在 BMS 在待机状态下四击 BMS 按钮进入。 当成功进入一致性查询环节后，BMS 指示灯首先将会以红黄绿依次点亮的方式（若当前电 池的一致性太差，压差超过 999mV，则先导提示将变为绿黄红的顺序）作为先导提示，提 示用户即将开始显示当前电池组的一致性状况。延迟 1 秒，BMS 后将通过红色，黄色和绿 色的指定次数的慢速闪烁（如果快速闪烁一次，则表示该数据位为 0）提示用户当前的电池 压差。对于压差的计算可以参考如下内容：

- 999mV 显示模式（先导提示为红黄绿）：红色闪烁次数 x100+黄色闪烁次数 x10+绿色闪 烁次数=当前电池最大的压差(mV)，例如 红色慢闪 1 次-黄色快闪 1 次-绿色慢闪 4 次 表 示电池当前最大压差（电压最高和最低的电池之间）为 100x1+0x10+4=104mV。
- 9.99V 显示模式（先导提示为绿黄红）：红色闪烁次数+黄色闪烁次数 x0.1+绿色闪烁次 数 x0.01=当前电池压差(V)，例如 红色慢闪 2 次-黄色慢闪 1 次-绿色慢闪 3 次 表示电池

## 当前最大压差（电压最高和最低的电池之间）为 2+1*0.1+3x0.01=2.13V=2130mV。

播报完电池当前的最大压差后，BMS 将会在延迟 2 秒后通过后续的长亮(或者慢闪)提示 用户当前电池的压差对应的电池健康度水平，参考如下内容：

- 播报完毕后绿色常亮：当前电池的一致性极好，可以安全使用
- 播报完毕后黄色常亮：当前电池的一致性一般，可以继续使用，但建议人工进行一致性 干预（如手动均衡等）
- 播报完毕后红色常亮：当前电池的一致性很差，不建议继续使用，需要尽快进行一致性 干预（如手动启动均衡等）
- 播报完毕后红色慢闪：当前电池的一致性极差，严禁继续使用。需要拆下电芯检查电芯 是否存在故障，并更换故障电芯。更换电芯后需要立即手动进行均衡。

如果 BMS 检测到当前电池一致性非常良好，也就是一致性播报为绿灯时，播报将会直 接结束，此时 BMS 返回正常运行状态。如果电池一致性一般，则 BMS 将会继续播报流程， 并额外播报当前压差最大，也就是一致性最差的电池所在的位置以方便您查询该电池的单体 电压并采取后续操作。播报的方式是延迟 2 秒后，通过指定次数的黄色慢闪，提示您异常 的电池所在的位置。
例如在播报结束的末尾，BMS 指示灯以黄色慢闪三次，表示 BMS 检测到电池架内第三 节电池（BATT3）的压差最高，您可以对该故障电池进行更换或手动均衡以修正电压差。 查询电池组的一致性状况

在 BMS 处于非活动状态下，为了减少电力消耗，BMS 状态指示灯会改为每隔 5 秒固定 点亮一下以指示电池状况。若您需要立即查看当前电池的一致性状况，您可单击 BMS 按键 一次。此时 BMS 将会短暂点亮 BMS 状态指示灯以同步显示电池健康状况，约 4 秒后 BMS 将返回非活动状态并熄灭 BMS 指示灯。需要注意的是，此操作将会同步唤醒充放电系统。

## BMS 充放电系统命令操作

## 手动唤醒充放电系统

即使在 BMS 处于正常工作的状态下，充放电系统也会自动进入休眠以节约电力。若您 需要手动唤醒充放电系统，您可单击 BMS 按键一次。此时 BMS 将会立即发送指令唤醒充放 电系统。此时充放电系统的指示灯将亮起。 强制执行保护板激活

由于 BMS 的供电线路为独立供电，单独绕过保护板故即使保护板处于保护状态，BMS 也能正常工作。若保护板处于保护模式，此时将会出现充放电系统指示灯无反应，不充不放 且手电筒点不亮按下按键无任何反应的故障。此时您可以七击 BMS 按键令 BMS 强制执行保 护板激活程序，此时 BMS 指示灯将会以绿色快闪三次作为提示。当成功激活后，充放电管 理系统的指示灯将会点亮。 强制重置充放电子系统

有时候充放电管理系统的 SoC 会因自身固件缺陷导致死机，或者出现异常行为（例如快 充不握手、不充不放、指示灯异常、充电时反复重启等）此时您可以八击 BMS 按键。BMS 将会以指示灯绿色快闪三次作为收到命令的提示，然后 BMS 将会发送充放电 SoC 重置指令 强制复位 SoC 以修复 SoC 死机引起的充放电异常。 手动禁止充放电

BMS 提供了在特定情况下手动禁止充放电的功能。在 BMS 处于待机状态下，连续快速 单击 BMS 按键六次，并在第六次单击结束后立即再长按两秒，即可令 BMS 进入禁止充放的 模式。此时充放电管理系统将被禁用，无法为电池充电和对外放电。 处于禁充模式后，BMS 指示灯将会通过每 5 秒钟以绿色快速闪烁三次并反复循环的方 式作为提示。若您需要退出该模式，则单击 BMS 按键一次即可。

## 主动均衡系统说明和特殊操作

该电池子系统的 BMS 具备主动均衡控制功能。依托 BMS 主板集成的变压器大电流主动 均衡，可以在出现较大一致性误差时快速进行能量转移以缩小电池的一致性误差。BMS 内 置的算法会根据电池一致性误差和单节电池的电压，自动执行三段式均衡（涓流-恒流-恒压） 过程以尽快修复一致性问题。 自动强制均衡

每次上电自检期间，BMS 都会自动检测电池的一致性状况。当 BMS 检测到一致性过差， 需要主动均衡介入时，系统将会立即启动强制均衡过程。该均衡过程无法取消，且 BMS 会 在均衡结束之前一直保持活动状态，直到一致性被均衡修复至极好的水平（小于 40mV）。 自动均衡过程和手动均衡过程都会令 BMS 指示灯处于慢闪状态作为提示。若自动均衡处于 运行状态，用户无法轻易取消且此时 BMS 会拒绝接收手动关机命令。 于此同时，如果电池一致性过差并且用户无视警告强制给电池充电，导致电池出现单体 过充时 BMS 也会进入过充保护模式，禁用充电功能并强制启用均衡。当均衡器将压差缩小 至一致性一般但可以继续充电的水平时，充电将会恢复。 在压差较小时取消自动均衡

为了方便用户特殊情况的需要，在系统的最大压差被修正到小于 160mV 的时候，用户 可以强制结束本次自动均衡。结束自动均衡的方法是连续快速单击 BMS 按键五次，并在第 五次单击结束后立即再长按两秒，即可令 BMS 结束本次自动均衡过程。 需要注意的是若压差大于 160mV，则自动均衡无法被取消。此时执行结束自动均衡命 令后 BMS 将会以红色快闪三次作为无法取消自动均衡的提示。 手动均衡

自动均衡会在压差小于 40mV 的情况下自动结束。如果用户想进一步运行均衡以修正压 差，可以在 BMS 处于待机状态下五击 BMS 按键。此时 BMS 将无视一致性状况强制开启手 动均衡，允许将压差修正到更小的值。
需要注意的是，如果压差已经达到非常小的值或者系统处于充放电状态，则手动均衡无 法开启，此时 BMS 指示灯将以红色快闪三次作为无法开启的提示。 开启手动均衡后，均衡系统将会保持运行，此时 BMS 指示灯将会持续慢闪作为提示。 在手动均衡期间，为了避免均衡器长时间运行而过热，当均衡器运行累计一个小时后将会自 动退出手动均衡模式。您也可以在一致性较好的情况下（也就是进一步修正压差至更优水平） 通过再次五击 BMS 按键退出手动均衡。
若您需要强制关闭手动均衡，则长按 BMS 按键 2 秒。此时 BMS 指示灯由慢闪状态变为 熄灭，表示手动均衡已被关闭。该关闭功能无视一致性状态，可以强制结束手动均衡。

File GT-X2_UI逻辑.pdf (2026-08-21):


# DFEx-GTX2 高功率泛光搜索手电

# UI 操作逻辑手册

## 由 redstoner_35 编写 仅供参考

## 总体操作逻辑

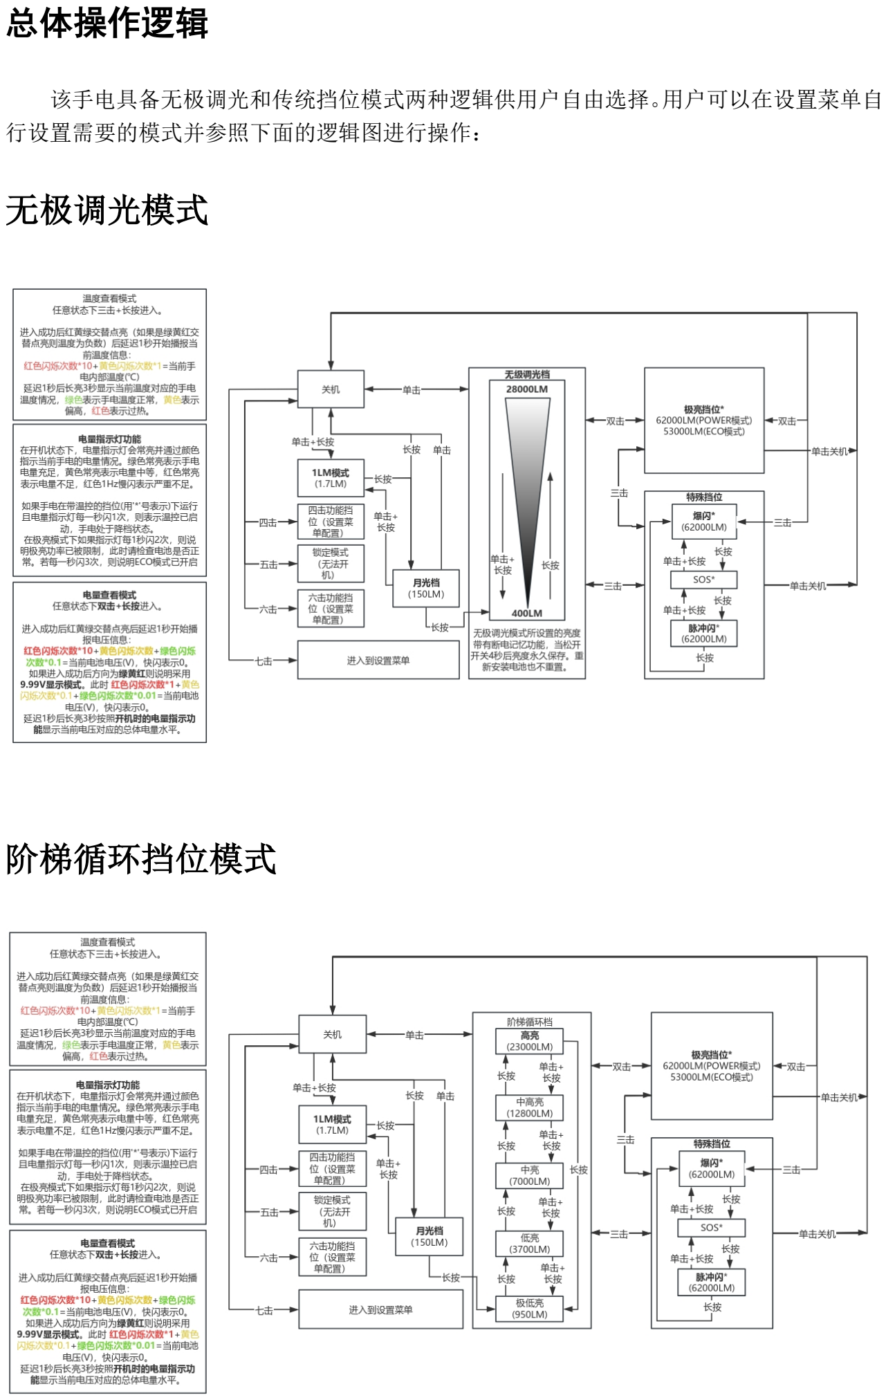
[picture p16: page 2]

该手电具备无极调光和传统挡位模式两种逻辑供用户自由选择。用户可以在设置菜单自 行设置需要的模式并参照下面的逻辑图进行操作： 无极调光模式

## 阶梯循环挡位模式

## 特殊功能操作逻辑

需要补充的是，图中的任意挡位均可以通过单击立即回到关闭状态。对于图中的部分未 详尽解释的特殊逻辑，则可参考如下内容： 电池定压放电模式

该手电使用的高倍率电芯若长期满电存放，电池性能将会不可逆的劣化导致手电工作异 常。因此本手电具备定压放电模式用于在长期存储前对电池进行放电，令电池处于安全的电 压水平（约 3.6V）。
该挡位的操作方式是关机状态下 8 击进入。若进入成功，手电将会立即开始点亮，并且 以指定的电流持续运行对电池缓慢放电。此时您只需要将手电朝上放置并等待手电自动熄灭 即可。当手电自动熄灭后，说明电池电压已被泄放至安全水平。但需要注意的是，此时手电 温度可能很高，应在手电完全冷却到室温后再放入包装箱内。
若 8 击时手电没有点亮而是侧按快速闪烁五次，则说明电池电压过低，无需放电。此时 您可以尝试对电池略微充电。若您需要强制结束放电过程，则单击侧按一次。

## 1LM 超级省电应急档

关机状态下单击+长按进入。进入该挡位后侧按的电量指示灯由原来的常亮改为每 10 秒按照正常运行过程中的电量情况短暂点亮一次以节约电力消耗（如果电池电量极低，则为 红灯慢速闪烁）。该挡位的流明值取决于灯珠性能和 V/I 特性，通常在 2-3LM 之间。该挡位 下长按可以进入正常的月光挡。需要注意的是，该挡位仅用于应急，故没有任何电池电量 保护机制。只要电池还有电力就会无限运行直到电池输入低于 7.2V 时驱动断电。若搭配第 三方出品，没有过放保护的电池组将会导致电池因为过放而永久性损坏！使用官方电池子 系统则不会有这个问题。 走夜路模式

关机状态下四击或六击进入（取决于设置菜单内设置项 8 的配置），手电此时开启约 1.1A 的低亮用于正常照明。此时若对向有行人或来车，则单击+长按后手电将会暂时熄灭以 避免强光晃到对面，松手后手电将重新点亮。如果长按，手电将开启和爆闪挡位功能等同的 全功率一键爆闪用以压制对面进行致盲操作，松手后手电恢复正常照明状态。 战术模式

关机状态下四击或者六击开关（取决于设置菜单内设置项 8 的配置），手电主灯迅速频 闪一次表示进入战术模式。默认情况下战术功能为按下开关手电以极亮运行，松开则熄灭。 当手电进入战术模式后，侧部按键将会每 2 秒快闪一次指示当前处于战术模式，此时手电将

会保持唤醒，直到无操作 10 分钟后自动进入休眠并退出战术模式。如果您需要主动退出战 术模式，则您可再度六击开关，手电主灯频闪一次指示退出战术模式。与此同时，您可以通 过双击侧按切换战术模式的功能，切换后的指示如下：

- 一键极亮模式（默认）：此时手电按下开关极亮，松开灭，侧按指示灯每 2 秒闪 1 次， 切换到该模式时手电的侧按会用红色快闪 3 次做提示。
- 一键爆闪模式：此时手电按下开关进入爆闪，松开灭，侧按指示灯每 2 秒闪 2 次，切换 到该模式时手电的侧按会用绿色快闪 3 次做提示。 按键锁

关机状态下五击开关，手电主灯点亮 0.5 秒表示进入锁定模式，此时手电的绝大多数功 能均被禁用以避免误触点亮引起事故，进入锁定模式后即使电池断开，锁定模式也不会自动 解除以免震动过程中电池瞬间松动导致误解锁，需要通过再次五击解锁。 在锁定模式中，为了方便用户查询长时间放置的手电电量，用户可双击+长按进行电量 查询操作（如下方电量查询模式功能所示）。
若用户有紧急照明需求，则可以单击+长按打开紧急月光照明。打开月光照明后用户可 单击关闭。同时该月光照明具有超时以及电量保护功能，若用户在开启后 30 秒内无操作或 手电电池电量过低，则手电将会自动关机。在电池电量充足的条件下，您可以通过单击+长 按并保持一直按住的方式持续照明。 温度查询模式

手电任意状态下三击+长按进入。当进入电量查询模式后手电的颈部开关指示灯首先将 会以红黄绿依次点亮的方式（若手电当前处于极寒环境，手电本身温度低于 0 摄氏度时， 先导提示将变为绿黄红的顺序）作为先导提示，提示用户手电即将开始显示手电当前的内部 温度。延迟 1 秒后手电将通过红色和黄色的指定次数的慢速闪烁（如果快速闪烁一次，则表 示该数据位为 0）提示用户当前的手电温度。在播报完当前手电的内部温度数值后，手电将 会在延迟 2 秒后通过后续的长亮(或者慢闪)提示用户当前内部温度数值所对应的手电散热情 况。对于温度显示的计算方式请参考如下内容：

- 播报完毕后绿色常亮：当前手电散热良好
- 播报完毕后黄色常亮：当前手电温度较高，请注意防止烫手
- 播报完毕后红色常亮：当前手电温度极高，请及时为手电散热并且避免被烫伤
- 手电温度(℃)=红色闪烁次数 x10+黄色闪烁次数，例如`红色慢闪 4 次-黄色快闪 1 次`表 示当前手电的内部温度为 40℃

## 查询精确电池电压和电量

手电任意状态下通过双击+长按进入。当进入电量查询模式后手电的颈部开关指示灯首 先将会以红黄绿依次点亮的方式（若电池电压低于 10.00V，则系统将会切换到高精度显示

模式以 0.01V 精度显示电量。此时先导提示将变为绿黄红的顺序）作为先导提示，提示用户 手电即将开始显示电池电压和电量。延迟 1 秒后手电将通过红色，黄色和绿色的指定次数的 慢速闪烁（如果快速闪烁一次，则表示该数据位为 0）提示用户当前的电池电压，播报完电 池当前电压后，手电将会在延迟 2 秒后通过后续的长亮(或者慢闪)提示用户当前电池电压对 应的总体电量水平（指示方式参考下文中驱动位于正常工作时的指示），对于电池具体电压 播报的计算方式请参考如下内容：

- 99.9V显示模式：红色闪烁次数x10+黄色闪烁次数+绿色闪烁次数x0.1=当前电池电压(V)， 例如 红色慢闪 1 次-黄色快闪 1 次-绿色慢闪 4 次 表示电池电压为 10x1+0+4x0.1=10.4V。
- 9.99V 高精度显示模式：红色闪烁次数+黄色闪烁次数 x0.1+绿色闪烁次数 x0.01=当前电 池电压(V)，例如 红色慢闪 8 次-黄色慢闪 1 次-绿色慢闪 3 次 表示当前电池电压为

## 8+1*0.1+3x0.01=8.13V。 恢复出厂设置

在手电处于完全断电状态下（用户可以通过卸下电池并反复多次按下手电侧按直到手电 没有任何反应）持续按住按钮并扭上电池包令手电通电。此时手电的侧部按键指示灯将会以 黄色的持续高频率快闪提示用户已恢复出厂设置。用户松开按键后，手电将会在 2 秒后自动 重启并进入正常工作状态。
同时，用户也可以通过关机状态下七击进入设置菜单，然后在设置菜单内选择恢复出厂 设置功能从而重置手电的设置。 正常工作时的电量指示

对于电压指示，驱动在工作状态会通过指示灯点亮的方式提示用户当前系统的电池电量。与 此同时，在手电首次装入电池时，驱动还会通过一次持续 2 秒的点亮提示电池电量（指示方 式和工作状态时相同）。对于手电当前的电量状态和对应的指示灯状态请参考如下内容：

- 绿色常亮：电池电量充足
- 黄色常亮：电池电量较为充足
- 红色常亮：电池电量不足，请尽快为手电充电
- 红色慢闪：电池电量严重不足，请立即为手电充电（此时手电的可用挡位和功能将会被 限制）

与此同时，在手电正常工作时，驱动还会再某些特定事件发生时通过一定时间内的短时间熄 灭次数的循环指示驱动发生的事件，详细的事件列表如下：

- 每 2 秒瞬时熄灭 1 次：手电温度过高，驱动已启用温控限制手电输出功率避免过热
- 每 2 秒瞬时熄灭 2 次：驱动检测到电池子系统无法为极亮提供足够的能量，为了避免电 池过载，极亮功率已被限制。（出现此提示请务必更换性能更强的电池）
- 每 2 秒瞬时熄灭 3 次：驱动当前开启了夏季模式，极亮输出功率和温度控制策略将会被 限制到更保守的级别。

# 设置菜单系统

该手电内置一个用于配置手电功能和特效的设置系统，用户可以通过关机状态七击进入 以设置手电本身的配置，详细的操作请参考下方图片。进入选择模式后单击可以循环切换设 置项。选中对应设置项后单击+长按进入，此时侧按绿灯快闪三次后进入该设置项。在设置 项内单击循环切换对应的参数值，长按保存并退出。

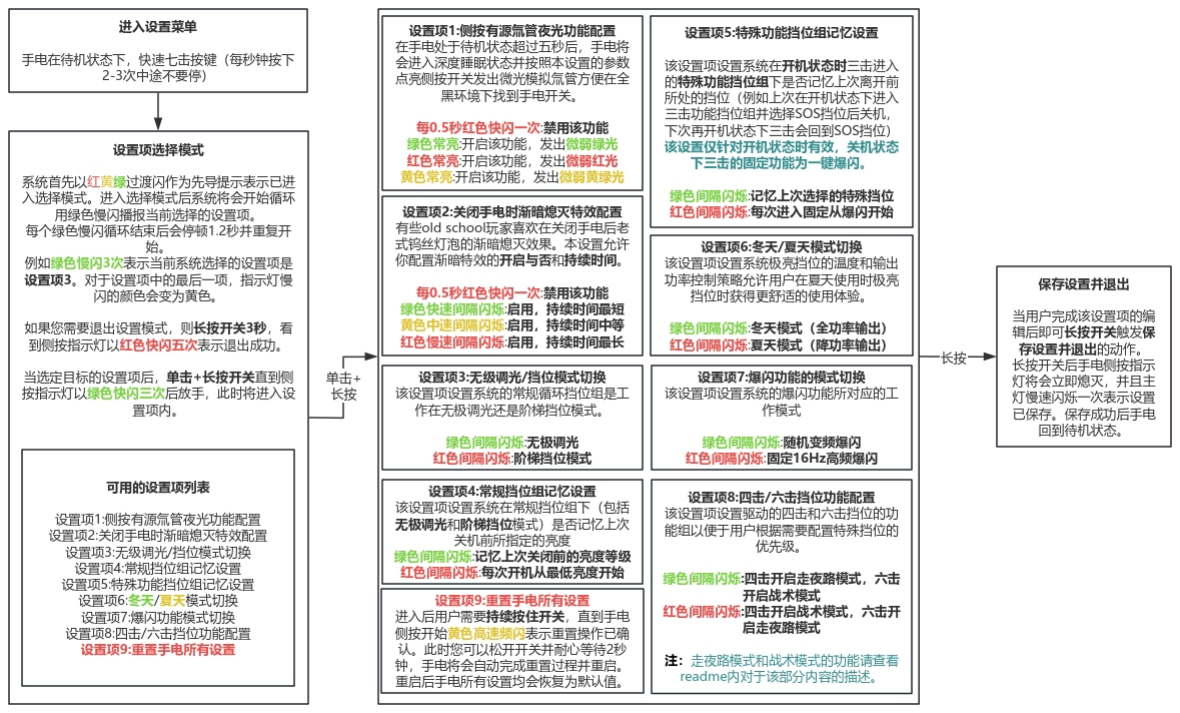
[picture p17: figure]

该设置菜单的设置项为非易失性存储。保存后即使断电也不会丢失。若您意外将设置调 乱可以通过重置设置项恢复到出厂设置。默认状态下 GT-X2 手电的出厂设置如下表：

设置项编号 | 设置项功能 | 默认出厂设置
1 | 侧按有源夜光功能配置 | 开启，侧按发出绿光
2 | 渐暗熄灭特效配置 | 开启，持续时间中等
3 | 无极调光/挡位模式 | 循环挡位模式
4 | 常规挡位组记忆设置 | 开启记忆，每次开机返回上次关机的挡位
5 | 特殊功能组挡位记忆设 置 | 关闭记忆，每次开机状态下三击调用特殊功能，固 定从爆闪挡位开始
6 | 冬天/夏天模式切换 | 开启夏天模式（ECO 挡位）降低输出功率提高使用 体验并允许使用低倍率电池
7 | 爆闪功能选择 | 随机变频爆闪
8 | 四击/六击挡位功能切 换 | 四击进入战术模式，六击进入走夜路模式

该出厂设置已足够满足大部分用户的使用需求，您可根据需要自行调节。若您需要改动出厂 默认值，您可以联系作者定制专属驱动固件并刷入以修改默认出厂设置的各项参数。

# 驱动故障排除

该手电的内置驱动具备自我测试和故障保护功能。驱动继承了 Xtern Ripper PRO 版本的 特性，具备先进的状态监测系统。在驱动每次通电自检和正常运行过程中，固件会通过 ADC 采集驱动的运行状态并判断负载和驱动是否运行正常。并且在检测到异常时立即切断驱动输 出以避免驱动和被驱动的灯珠损坏。当手电运行异常时，您可参考本章节的内容对手电进行

## 故障排除。 侧部电子开关故障报告

手电在运行期间如果驱动检测到无法解决的致命问题则会进入保护模式避免驱动和灯 珠损毁，并通过颈部侧按键的指示灯提示用户发生的错误类型。每个指示循环首先以红黄绿 的颜色切换闪烁开始，然后通过紧跟着的红色慢闪次数指示错误 ID 号（例如慢闪 5 次表示 错误 ID 为 5）。慢闪结束后会停顿一会并重新开始循环。 同时，为了避免驱动始终处于故障报告模式导致电池被放干。若用户在错误报告状态下 无操作超过 30 秒，手电会自动进入休眠。此时若您需要查看错误代码，可以单击按键唤醒 手电。

对于 ID 号所对应的错误描述请参考如下内容：

错误 ID | 错误代码 | 描述和解决方案
1 | Fault_DCDCFailedToStart | 驱动在上电自检尝试启动 DCDC 时失败（可能是辅电 DCDC/主控内部 LDO 输出电压异常）。您可以尝试重新 安装电池并确保电池电量正常，若无法解决，请送修。
2 | Fault_DCDCShort | 驱动在启动和运行期间检测到输出短路。此时请勿继续 使用手电，及时送修。
3 | Fault_InputOVP | 驱动检测到输入电压过高。若您使用外接电池套件，检 查手电筒所连接的电池组是否为 4S 三元锂电池。若使用 原配电池仍然出现，请送修。
4 | Fault_DCDCOpen | 驱动在运行时检测到输出空载。可能是 LED 开路损坏或 导线脱焊，为避免故障扩大，请送修。
5 | Fault_NTCFailed | 驱动在运行期间检测到测量驱动温度的热敏电阻出现异 常（也可能是手电暴露在远超设计范围的极高或极低温 度下导致）请让手电恢复到正常运行温度，仍无效则送 修。
6 | Fault_OverHeat | 驱动检测到外壳温度过高，请等待手电自然冷却。当冷 却后故障会自动解除。
7 | Fault_DCDCPreChargeFa iled | 驱动检测到实现 CV 环可控斜率预充的电路出现故障。该 问题为电路问题，需要送修解决。
8 | Fault_RampConfigError | 驱动在启动时检测到固件内存储的挡位数据被意外删除 或丢失，此时请送修重新刷写固件。

## 驱动心跳/状态指示灯

若用户遇到手电无法开机（按下按键无任何反应等）可以通过可调电源为驱动通电并结 合驱动主板上的两个指示 LED（如下图所示）判断驱动当前的运行状况。两个指示 LED 位置 如下：

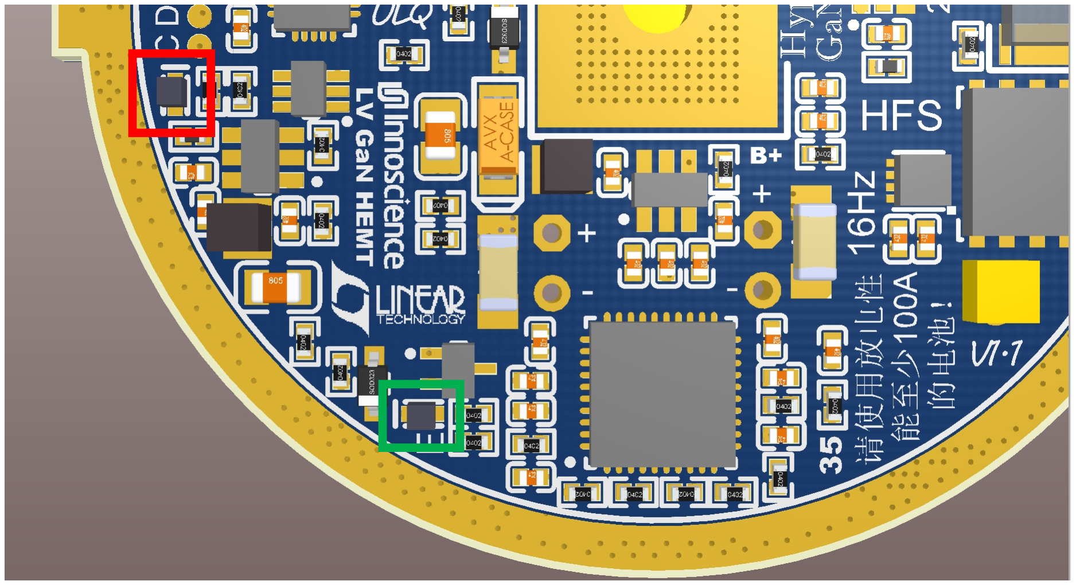
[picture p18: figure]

其中红色框标记的 LED 为系统心跳 LED(记为 SYSHB)该 LED 在通电的前几秒（上电期间） 以及正常运行期间会点亮和闪烁指示固件状态。绿色框标记的 LED 则为输出使能 LED（记为 OE）。在驱动对 LED 输出能量的期间，该 LED 会点亮。这两个 LED 的状态表如下所示：

系统状态 | 心跳 LED(SYSHB) | 输出使能 LED(OE) | 驱动状态
上电前几 秒（POR- SelfTest） | 2Hz 闪烁 | 熄灭 | 驱动正在等待输出电容预充电
| 常亮 | 熄灭 | 驱动正在进行 DCDC 试运行
| 5Hz 快闪 | 熄灭 | 驱动对输出电容的预充超时（硬件故障）
| 任意状态 | 点亮或闪烁 | 驱动固件损坏（需要重刷固件）
| 熄灭 | 熄灭 | 驱动 MCU 未运行（可能是固件损坏或没 有固件，也可能是 MCU 供电异常）
驱动正常 运行状态 | 1Hz 慢闪 | 熄灭 | 驱动已通过自检，正在待机中
| 4Hz 快闪 | 熄灭 | 驱动自我测试系统检测到故障，请参照 电子开关故障报告章节进行排查。
| 熄灭 | 熄灭 | 驱动长时间没监测到用户操作，已进入 深度休眠模式减小静态电流。
| 常亮 | 常亮或闪烁 | 驱动处于正常工作状态，正在按照当前 的挡位设置对 LED 输出能量。
| 熄灭 | 常亮 | 驱动处于超低功耗工作状态，正在对 LED 输出极低电流（系统处于 1LM 模式）

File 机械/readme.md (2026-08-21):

### 关于文件格式的说明

这里所提供的3D文件格式为UG NX的部件格式。为了方便复刻联系五金供应商进行报价故作者还提供了每个部件所对应的Step文件。**需要特别注意的是，Step文件仅供报价参考，不得作为最终加工的特征基准！**对于最终的加工尺寸基准，请按照UG NX的原文件进行处理。

### 关于材料的选择

该手电的外壳在设计时是按照**6061T6铝合金以及7075铝合金**进行设计的。考虑到导热性、材料硬度等因素，请严格按照图纸要求的材料进行加工。不建议使用其他材料进行制造。

### 使用到的标准件

+ 光杯和玻璃：复用[飘落396](https://space.bilibili.com/694332529?spm_id_from=333.337.0.0)自己的PL-3产品的光杯和玻璃。可以在b站私信联系他购买。如果财力雄厚，也可以在淘宝[古洛玻璃](https://item.taobao.com/item.htm?id=565284568813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)让玻璃厂按照要求定做前部玻璃。并且联系淘宝[宏广照明](https://shop62447845.taobao.com/category.htm?spm=pc_detail.30350276.shop_block.dshopinfo.351f7dd6hhNBdb)按照项目机械部分文件夹中的[光杯尺寸图](/%E5%85%89%E5%AD%A6%E7%9B%B8%E5%85%B3%E6%96%87%E4%BB%B6/%E5%85%89%E6%9D%AF%E5%B0%BA%E5%AF%B8%E5%9B%BE.jpg)定制新的光杯。光杯需要使用橘皮杯，否则出光会严重黑心！！！
+ 按钮组件：使用了东东海用在他们侧按大手电（如D8/D7等）的标准按钮组件。可以去[东东海淘宝店](https://item.taobao.com/item.htm?id=40440391322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)以购买**F8B手电的按钮组件，包括胶皮**的方式联系客服并拍下改价。一个按钮大约6块RMB。
+ 灯珠定位片：使用了夜巡老王的8080转10孔光杯的专用灯珠定位片。可以在夜巡老王店铺的[DIY配件链接](https://item.taobao.com/item.htm?id=667665406598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)联系老王拍下改价购买。单价约2RMB，一把手电需要10PCS。定位片图片可以参考光学文件夹中的[定位片样式图片](/%E5%85%89%E5%AD%A6%E7%9B%B8%E5%85%B3%E6%96%87%E4%BB%B6/%E5%AE%9A%E4%BD%8D%E7%89%87%E6%A0%B7%E5%BC%8F.jpg)。

#### 玻璃定制参数

如果您财力雄厚，您可以自行定制钢化窗口片获得更高的透光率。定制参数如下：

+ 玻璃形状：圆形
+ 玻璃材质：超白
+ 玻璃直径：92mm -0.05mm +0mm
+ 玻璃厚度：3mm ±0.05mm
+ 边沿处理：外形边沿保护性倒棱避免刮手，倒角参数C0.2 45度
+ 玻璃本身强化处理：化学强化（化学钢化）
+ 玻璃镀膜要求：双面绿色AR可见光增透镀膜处理，可见光范围(400-700nm)透过率99%以上。

### 按键和驱动压环的处理

考虑到不锈钢材质的按钮和驱动压环较软，在加工完毕后表面很脆弱容易划伤。因此作者建议这些工件送去进行DLC处理以极大提高表面硬度。

### 驱动压环螺纹参数

驱动压环的螺纹参数请不要按照Step内的示例螺纹加工！请按照如下内容加工：

+ 螺纹名称：M56*1.0
+ 螺纹大径：56.0mm -0.05（驱动压环） +0.1（筒身的内螺牙）
+ 螺纹小径：54.8mm -0.05（驱动压环） +0.1（筒身的内螺牙）
+ 螺纹旋向：右旋
+ 螺纹角度：60度

特别注意的是，驱动压环螺纹根部（靠近大凸台，朝向电池仓方向的位置）需要预留1mm的退刀槽！否则驱动压环无法扭到底直接报废！驱动压环应使用H62黄铜材质以确保压环具备足够的导电性。为了保证美观建议购买化学清洗、抛光和钝化液体对压环进行化学处理，使得压环不会氧化发黑甚至生锈。

### 关于文件内尺寸的说明

需要注意的是这里的3D文件内的尺寸并未按照配合关系进行完全的优化。因此加工时一定要和老板沟通清楚相关螺纹以及五金件的配合参数。否则加工出来的将会是废品！作者建议所有的五金件在加工时均由同一家供应商进行，并且配合件的公差参数由他们按照自身设备的匹配情况进行把控，这样可以避免多家供应商的配合尺寸基准不一致导致最后无法装配的问题。同时，如果您决定生产时为外壳做硬质氧化处理，则一定要和加工厂沟通时让他们零部件的给所有内孔的直径进行一个 **+0.15到+0.2mm的扩大**以确保有足够的配合间隙！否则硬质氧化后，零件的内孔尺寸会缩小变形0.15-0.2mm导致部分紧配合区域（例如电池筒和电池架之间）完全无法装入！作者已经在这个地方翻车了，四个电池筒身全部报废花了1000快钱返工重做重新氧化。

### 密封圈选配说明

为了使手电达到应有的防水性能，您需要在筒头、玻璃、筒身等位置预留的密封圈槽位置正确安装密封圈方可达到防水性能。该手电对于密封圈的品牌没有要求，只要材质和尺寸正确即可。密封圈数据请参考如下：

+ 筒头密封圈（位于玻璃和筒身，光杯之间实现筒头的气密）：外径92mm，线经2mm
+ 尾盖密封圈（实现电池筒身和尾盖之间的密封）：密封圈尺寸暂定
+ 筒头-筒身密封圈（装载电池筒前部实现筒头和筒身之间的密封）：密封圈尺寸暂定

**请使用橡胶材质如氟橡胶、EPDM的密封圈以获得最佳密封性能**

同时，在前部玻璃压环和玻璃之间，需要定制一个0.1mm厚度，内径85mm，外92.4mm的DMD绝缘纸垫片，隔开玻璃和304不锈钢压环避免玻璃直接硬接触金属！否则锁紧压环后，玻璃可能会因为承受巨大压应力而自行裂开甚至自爆！您可以在[盛发绝缘材料](https://market.m.taobao.com/app/im/chat/index.html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)的淘宝店联系店主定制。该绝缘垫片的耐温等级要求为F级。

### 二次加工的说明

为了实现正确的导电连接，因此筒头部分在阳极氧化结束后需要再次上级进行二次加工去除氧化层。筒头去除氧化的位置为驱动仓和基板仓。

----------------------------------------------------------------------------------------------------------------------------------
© redstoner_35 @ 35's Embedded Systems Inc.  2026

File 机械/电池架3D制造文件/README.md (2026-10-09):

## 电池架四周导电铜柱说明

### 连接底座和顶部结构之间的M3铜柱

连接底座的四个M3铜柱为标准件。您可以在淘宝购买[80mm长度单通内六角铜柱](https://detail.tmall.com/item.htm?id=631585716430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)并且找普车师傅给你在内螺纹的端面位置车一刀车成79mm。

### 连接底座和顶部结构的中心铜柱

在底座和顶部结构之间还有一个M5的实心铜柱需要CNC车削加工。由于结构太过简单因此作者恕不提供具体的3D图纸。以下是该铜柱的要求：

+ 工件外形：实心棒料直径8mm长度79mm，材质为铬锆铜（紫铜也行但是比较废刀）表面需要精车到Ra1.6粗糙度。所有外形尺寸走负公差（允许尺寸偏差为+0mm/-0.05mm）。
+ 两端加工要求：该棒料两端钻M5*0.8内螺纹孔，有效螺纹深度11mm，内螺纹孔轴心必须和棒料外圆同轴。同轴度偏差不得超过0.05mm。

该铜柱加工没有什么技术难度，找普车师傅即可完成加工。可以自行在淘宝购买铬锆铜棒材然后给普车师傅塞点钱（塞几包烟也行）然后等他加工。自己买料的话可以买直径12mm，长度零切150mm的棒材预留足够的调直和精车余量。

## 电池架顶部按键的说明

该电池架顶部有一个用户唤醒BMS的按键，这个按键为铝材质的标准件。这个铝件可以在[淘宝](https://item.taobao.com/item.htm?id=743639180452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)上买到，基本不需要自己制造。如果实在买不到的话可以自行在装配体内导出按钮的3D图纸安排CNC加工（很贵很贵）。

## 电池架使用的垫片说明

该电池架总成一共使用了两种垫片，该垫片必须按照要求打样并覆盖在保护板和电池架底座之间，以及充电板和顶部散热块之间，以免发生短路！！垫片的2D图纸可以在垫片相关的文件夹内找到。对于需要的厚度和材质类型，请参考文件名。每个电池架总成需要2种、各一个垫片。作者使用的垫片的定制供应商如下：

+ 1.0厚度EPDM垫片：[鑫胜源塑胶制品](https://item.taobao.com/item.htm?id=645674577873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)
+ 0.2厚度青稞纸垫片：[深圳市爵达士绝缘材料有限公司](https://shop525160103.taobao.com/category.htm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)

联系好愿意打样的供应商之后，将2D图档和需要的厚度要求提交给供应商即可。打样建议报多一点数量，比如说十几二十个因为太少了他们可能会因为嫌麻烦而懒得给你做。

## 保护板限位垫圈

在制造期间作者发现EPDM无法承受螺丝的扭力会导致保护板被拉变形而引起导电异常以及断线，因此在保护板和铝制电池架底座之间需要增加一个内径3mm，外径5mm厚度1mm的黄铜垫圈作为间隔避免PCB被拉变形。该垫圈可以在[淘宝](https://item.taobao.com/item.htm?id=1064116642584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)买到。垫圈需要在保护板制造的时候直接焊接到保护板对应位置，不能直接依靠机械锁紧力固定。对于具体的焊接位置，您可以查看工程文件中的[电池架装配总成](%E7%94%B5%E6%B1%A0%E6%9E%B6%E8%A3%85%E9%85%8D%E8%A7%86%E5%9B%BE.SLDASM)文件的装配体查看位置。

## 3D文件说明

需要外部CNC加工的五金料已经单独为您生成2D图纸和3D图纸，您只需要将图纸提交给CNC供应商即可。需要注意的是，[均衡板的导电铜柱](/3D%E5%9B%BE/%E5%9D%87%E8%A1%A1%E6%9D%BF%E6%94%AF%E6%92%91%E6%9F%B1.STEP)每个电池架需要4PCS因此订购时务必按照需要的数量订购。

----------------------------------------------------------------------------------------------------------------------------------
© redstoner_35 @ 35's Embedded Systems Inc.  2026

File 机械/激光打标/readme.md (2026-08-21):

## 激光打标格式说明

### ezd后缀文件

ezd格式为金橙子EZCAD 2.0激光打标系统控制软件的文件格式。里面已经包含了所有的图元和填充信息，打标时直接提交给商家即可。特别注意的是，如果商家不是使用金橙子系统的话就打不开，所以说下单之前需要**询问商家是否支持用ezd文件打标**。

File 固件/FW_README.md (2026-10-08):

powered by 35's Embedded Systems Inc. An Open-Source High Power Flood FlashLight Solution    

## 固件编译注意事项

### 固件编译环境要求

该驱动的固件源代码使用了**Keil C51 V9.61a版本**的高级编译优化特性来实现空间压缩。使用其他的keil C51版本会导致编译出来的固件因为优化不足，超出芯片容量大小而编译失败！此外该程序源码不支持开源编译环境如SDCC等。如果您需要使用开源工具链，则请自行移植。如果您编译无法通过则可以使用[预编译固件文件夹](/%E9%A2%84%E7%BC%96%E8%AF%91%E5%9B%BA%E4%BB%B6/)内作者所编译好的二进制固件文件并提供给芯片卖家让其烧录好芯片。

### MCU的CONFIG配置

由于中微单片机内部有一组硬编码于Flash指定区域，用于设置单片机的硬件首选项（例如看门狗，调试模式，低电压保护点等）的配置Word。为了确保编译出来的固件可以在硬件内正常运行，您需要在工程配置(Options for Target '*****'->Debug选项卡->右上角的Settings按钮)的Config设置菜单，按照下表正确填写MCU的配置。错误的CONFIG设置会引起固件工作异常！

+ Power                      :  Inter 5V（适用于驱动固件） / Inter 3.3V（适用于其余的固件）        
+ WDT                        :  SOFTWARECONTROL     
+ PROTECT                    :  ENABLE              
+ FLASH_DATA_PROTECT         :  ENABLE              
+ LVR                        :  3.5V（适用于驱动固件） / 2.0V（适用于其余固件）                
+ DEBUG                      :  Disable             
+ OSC                        :  HSI                 
+ OSC_PRESCALE               :  Fosc/1              
+ HSI_FS                     :  Fhsi/1              
+ EXT_RESET                  :  DISABLE             
+ EXT_RESETSEL               :  P00                 
+ WAKEUP_WAITTIME            :  500us               
+ CPU_WAITCLOCK              :  2T                  
+ WRITE_PROTECT[0-2K]        :  DISABLE             
+ WRITE_PROTECT[2-4K]        :  DISABLE             
+ WRITE_PROTECT[4-6K]        :  DISABLE             
+ WRITE_PROTECT[6-8K]        :  DISABLE             
+ WRITE_PROTECT[8-10K]       :  DISABLE             
+ WRITE_PROTECT[10-12K]      :  DISABLE             
+ WRITE_PROTECT[12-14K]      :  DISABLE             
+ WRITE_PROTECT[14-16K]      :  DISABLE             
+ BOOT                       :  BOOT_DIS      

### 烧录器在哪买？

本项目使用到了中微半导体的CMS8S系列MCU。配套的在线烧录/调试器是中微的**CMS ICE8 PRO** 。您可在中微半导体的[淘宝店](https://item.taobao.com/item.htm?id=679620957040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)购买。并且安装好CMS 51的Keil支持补丁。相关补丁可以在[中微半导体官网](https://www.mcu.com.cn/)下载。安装好环境并编译通过后，您可以直接在keil中使用CMS ICE8 PRO烧录器直接将固件烧录到单片机内。由于时间有限，作者恕不提供关于keil C51环境、烧录器驱动等基础环境的搭建教程。烦请自行google或百度查找相关教程。如您实在无法成功搭建环境，请看本文件的下一个章节。

## 如果我没办法自己编译和在线烧录怎么办？

如果您所使用的IDE环境不被CMS8S单片机所支持导致无法编译或下载，作者也提供了解决方案。在工程文件夹中提供了预先编译好的固件。您可以在购买芯片时，向芯片卖家提供hex文件让其代替您完成固件烧录并将烧录完毕的芯片邮寄给您。但是有一点需要强调，偷懒让芯片卖家为您代客烧录的烧录费用极为惊人，要做好心理准备。通常四款程序，四种样品各5-10PCS的烧录费用可达300至500人民币。如果您需要让商家代客烧录，请提供如下的Option Byte和烧录流程烧录信息给卖家：

+ Power                      :  Inter 5V（适用于驱动固件） / Inter 3.3V（适用于其余的固件）        
+ WDT                        :  SOFTWARECONTROL     
+ PROTECT                    :  ENABLE              
+ FLASH_DATA_PROTECT         :  ENABLE              
+ LVR                        :  3.5V（适用于驱动固件） / 2.0V（适用于其余固件）                
+ DEBUG                      :  Disable             
+ OSC                        :  HSI                 
+ OSC_PRESCALE               :  Fosc/1              
+ HSI_FS                     :  Fhsi/1              
+ EXT_RESET                  :  DISABLE             
+ EXT_RESETSEL               :  P00                 
+ WAKEUP_WAITTIME            :  500us               
+ CPU_WAITCLOCK              :  2T                  
+ WRITE_PROTECT[0-2K]        :  DISABLE             
+ WRITE_PROTECT[2-4K]        :  DISABLE             
+ WRITE_PROTECT[4-6K]        :  DISABLE             
+ WRITE_PROTECT[6-8K]        :  DISABLE             
+ WRITE_PROTECT[8-10K]       :  DISABLE             
+ WRITE_PROTECT[10-12K]      :  DISABLE             
+ WRITE_PROTECT[12-14K]      :  DISABLE             
+ WRITE_PROTECT[14-16K]      :  DISABLE             
+ BOOT                       :  BOOT_DIS 

烧录流程（针对其余的三个固件）如下图：

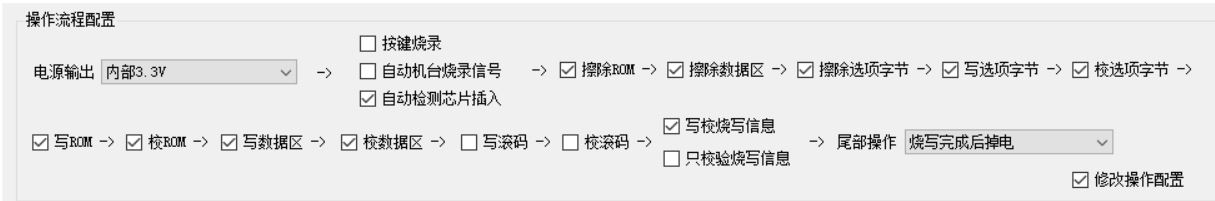
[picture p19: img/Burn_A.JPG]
烧录流程A


烧录流程（针对驱动的固件）如下图：

烧录流程B

烧录驱动的流程绝不应用于烧录其余两个固件，否则会导致风扇手柄运行异常！

## 驱动有那么多个固件是干啥用的？

考虑到元器件参数一致性和批次带来的偏差，因此同一个固件在不同的硬件上会产生微小的输出电流偏差(通常1-2%左右)因此作者提供了+2% +1%以及0%挡位的固件允许您按需烧录来解决输出电流偏差过大的问题。作为保险起见，作者建议您先烧录+0%的无补偿固件并连接钳表实际测试输出电流。如果电流偏小，则刷写带电流补偿的固件直至极亮电流达到标称值。此外，考虑到复刻时用料和电池性能的差异，部分电池可能无法支撑16万LM的满血输出并触发驱动保护导致亮度值被锁至10万。如果这种情况发生，您可刷写小电流降额固件以14万LM极亮作为代价换取稳定输出。

## 为什么禁赛版本风扇把手有2个固件？

禁赛版本的风扇把手存在2款硬件PCB。这两者互不兼容。对于使用2.2uH电感进行焊接，支持单锂51W输出的单锂暴力版本，请刷写单锂暴力模式专用固件。如果你贴装了4.7uH电感在牺牲单锂输出能力的条件下解锁单双锂支持，则刷写单双锂通用版本固件。这两个固件的操作逻辑基本一致，除了单锂暴力版本固件始终开启电池配置锁并屏蔽了双锂模式的一切功能，禁止安装两节电池开机外没有其余区别。 **需要注意的是，固件一定不能刷错！** 如果单锂暴力版本硬件刷写双锂版本固件会导致单锂模式下风扇输出功率异常，且上双锂强制开机会因为峰值电流过大瞬间烧毁IC！双锂版本硬件刷写单锂暴力版本固件会导致单锂下因为输出功率未限制而引起电感过热，装两节电池后驱动直接报错无法开机。

----------------------------------------------------------------------------------------------------------------------------------
© redstoner_35 @ 35's Embedded Systems Inc.  2026

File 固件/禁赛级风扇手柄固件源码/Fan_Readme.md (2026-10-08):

powered by 35's Embedded Systems Inc. A Next generation FlashLight Driver Solution     

## 概述

Xtern Ripper HyperFanDriver Ultra Edition(HFD Ultra)是一款全新设计的侧按单锂升压驱动12V超级暴力风扇驱动，针对本手电所选配的基于东东海F1A风扇辅助散热手柄半成品五金套料所实现的风扇主动散热手柄DLC而设计。相比于市面上所谓的垃圾订制驱动(如某笨雨的)具备更强的电流输出能力、更稳健的电路设计和保护机制。该驱动同时支持2线电压调速风扇和四线PWM风扇。单锂模式下使用单节21700锂电池即可实现广泰永立的最强4028暴力风扇（MG4012FB-W28 M，标称12V6.2A，实际功率约12V 4.25A 51W，转速高达43000RPM）持续运行并让手电达到5万LM的持续常亮。

## 吐槽

某些商家的所谓定制风扇驱动，卖个50块，连防反接都不加。合着客户买了恁的玩意每次装个电池还得看极性对不对是吧？然后风扇PWM信号连电平隔离都不做，直接一个电阻接GPIO，还通过控制风扇负极断开电源。知不知道风扇在只断负极的状态下PWM引脚会从正极漏电出来倒灌进MCU，导致待机功耗大甚至烧MCU？知不知道有些风扇的PWM信号引脚内部直接上拉12V电源，10mA的高压强上拉倒灌直接炸你MCU？升压芯片还用61288带个实际电流2.25A的台达PFB0412EN都过热保护停机，TI标15A峰值能力就那米粒大的封装蚊子腿焊盘你还真信啊？再加上那唐氏layout，芯片一点散热都没有，那能不过热么！我的评价是，能不能少造点电子垃圾啊？JLC打板子这么方便不是给傻逼造垃圾用的！菜就多练，技术不到家就别出来卖东西丢人现眼，多练几年再出来接商单。

## 性能数据

+ 支持的电池输入类型：1S三元锂电池，持续放电能力应大于25安培（作者测试时使用了比克N21700CX-65E）且ACIR应小于6mΩ。 *虽然固件层面支持1-2S，但是通用的话会降低1S下的输出能力。如果一定要单双锂通用则参考原理图内的说明！*
+ 支持的风扇类型：12V额定工作电压的直流无刷风扇，2线电压调速或四线PWM调速均可。暴力风扇建议使用四线PWM获得最大调速范围。
+ 支持的风扇电流和功率：默认配置下单锂条件下51W(12V 4.25A)。如果开启单双锂通用模式，则双锂最高84W(12V 7A)，单锂模式最高30W(12V 2.5A)。**注意：本处所标称的电流为支持的风扇实际电流而非风扇标签上所写的电流，只要保证风扇的实际运行电流不超过限制即可。例如广泰永立的MGT4012FB-W28 M风扇的标签电流为6.2A，但实际运行电流为4-4.2A附近，此时风扇是可以正常使用的**
+ 电池保护：具有欠压自动降档和关机保护以及过电压保护

## 总体操作逻辑

该风扇驱动同时具备无级调速和阶梯挡位调速可以随时选择。同时还具备双击一键全速功能。对于风扇的操作逻辑可以参考如下：
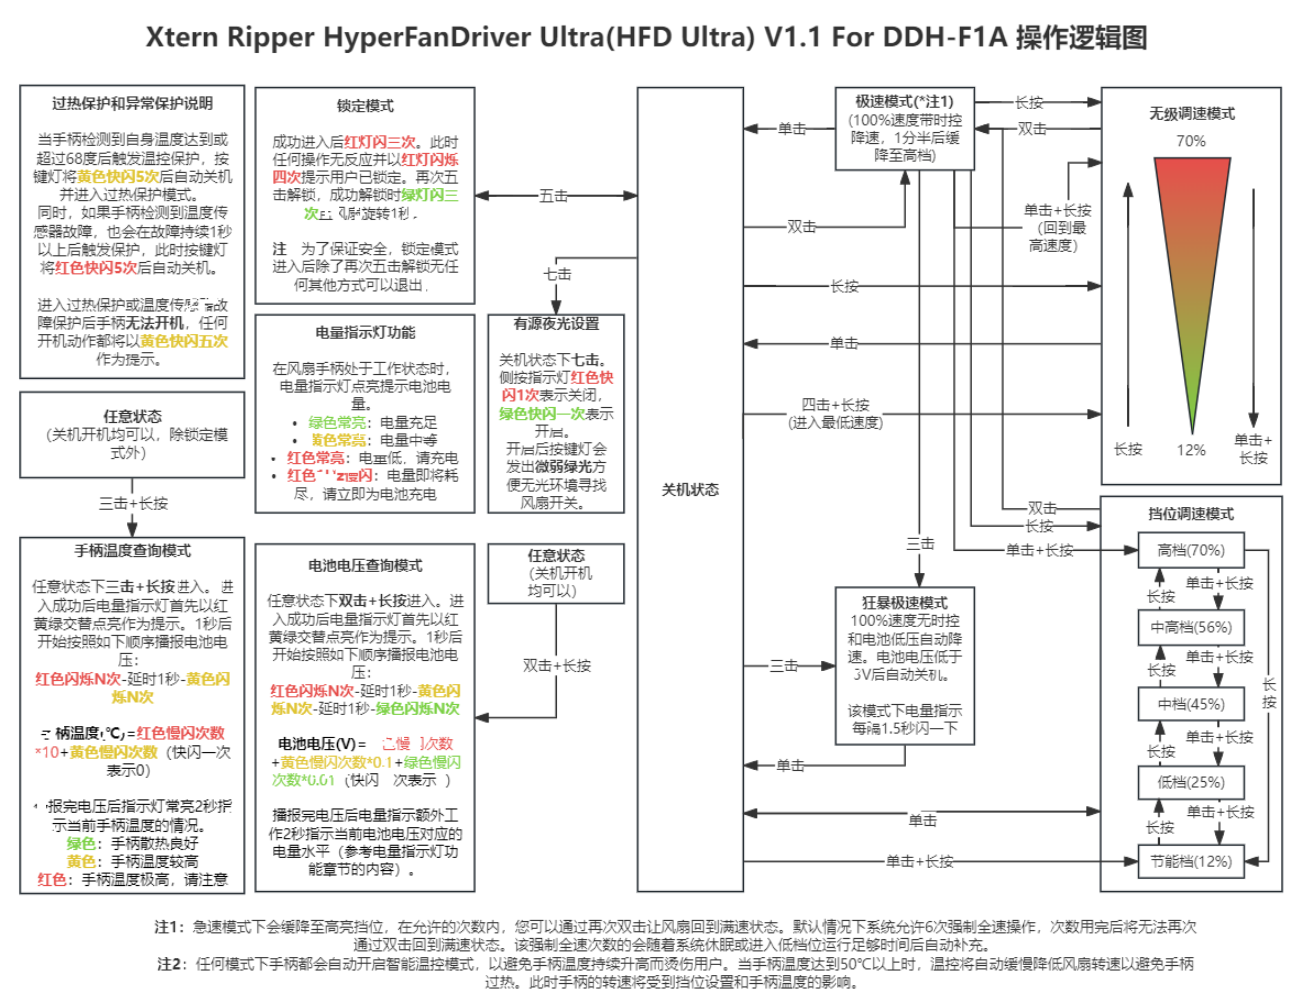
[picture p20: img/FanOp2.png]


对于图中的部分未详尽解释的特殊逻辑，则可参考如下内容：

+ 按键锁：关机状态下五击开关，侧按指示灯红色闪三次进入锁定模式，此时除了双击+长按查询当前电池电量以外的其余任何操作无效。如果用户尝试开机或执行其余操作，则侧按指示灯以红色闪五次作为提示。**为了保证安全，进入锁定模式后即使重新安装电池，风扇也会始终保持在锁定状态。** 在锁定状态下再次五击，侧按指示灯绿色闪烁三次，并且风扇低速运转1.5秒，表示成功解锁，此时风扇可以正常操作。

+ 查询电量：任意状态下通过双击+长按进入。当进入电量查询模式后风扇的颈部开关指示灯首先将会以红黄绿依次点亮的方式作为先导提示，提示用户风扇即将开始显示电池电压和电量（如果输入电压大于等于10V，则会切换到绿黄红先导提示的高电压显示模式。虽然不太可能出现）。延迟1秒后风扇将通过红色，黄色和绿色的指定次数的慢速闪烁（如果快速闪烁一次，则表示该数据位为0）提示用户当前的电池电压，播报完电池当前电压后，风扇将会在延迟2秒后通过后续的长亮(或者慢闪)提示用户当前电池电压对应的总体电量水平（指示方式参考下文中驱动位于正常工作时的指示），对于电池具体电压播报的计算方式请参考如下内容：
  - 红色闪烁次数+黄色闪烁次数x0.1+绿色闪烁次数x0.01=当前电池电压(V)，例如`红色慢闪4次-黄色慢闪1次-绿色慢闪3次`表示电池电压为4+1*0.1+3x0.01=4.13V。

+ 查询温度：任意状态下通过三击+长按进入。当进入电量查询模式后风扇的颈部开关指示灯首先将会以红黄绿依次点亮的方式作为先导提示，提示用户风扇即将开始显示温度。此外，如果当前风扇处于极寒环境（温度低于0摄氏度）则先导提示将变为绿黄红的顺序。延迟1秒后风扇将通过红色和黄色指定次数的慢速闪烁（如果快速闪烁一次，则表示该数据位为0）提示用户当前风扇的温度。温度播报的规则如下：
   - 红色闪烁次数x10+黄色闪烁次数=当前风扇把手温度(℃)，例如`红色慢闪3次-黄色慢闪1次`表示电池电压为3x10+1=31℃。

播报完手柄当前温度后，风扇将会在延迟2秒后通过后续的长亮提示用户当前电池温度对应的手柄散热水平。播报方式请参考如下内容：
  - 绿色常亮：风扇手柄散热良好
  - 黄色常亮：风扇手柄散热一般，温度较高请注意散热
  - 红色常亮：风扇手柄温度极高，请注意避免被烫到

+ 设置按键有源夜光功能：关机状态下七击按键，风扇的侧按指示灯以绿色快闪一次表示功能开启。若以红色快闪一次则表示功能关闭。该功能开启后，风扇手柄将会在闲置未用且电池电压充足的情况下令按键发出微弱绿光指示风扇手柄的开关位置。
+ 恢复出厂设置：在手柄处于断电状态下，持续按住按钮并装入电池。此时手柄的侧部按键指示灯将会以黄色的持续高频率快闪提示用户已恢复出厂设置。用户松开按键后2秒，手柄将会自动重启并进入正常工作状态。需要注意的是，恢复出厂设置并不能清除电池配置锁定。

## 过热保护和温控说明

考虑到本款暴力风扇驱动的输出功率较为巨大，在持续全功率工作时驱动本身会产生较大的热量并可能超出外壳的解热能力。此时若没有温度控制，则风扇手柄的温度将会持续提升并烫伤用户，甚至导致驱动因过热而烧毁。为了避免这种情况发生，本款风扇驱动加入了温度检测和温控以及过热保护系统。手柄驱动通过NTC测量把手本身的温度，当把手本身的温度达到49度以上时，驱动将会逐步缓慢降低暴力风扇的功率以限制驱动自身的发热。当触发温度控制后，把手指示灯会每隔2秒闪烁2次作为提示。同时把手还有温度传感器异常保护以及过热保护，参考如下内容：

### 过热关机保护

在温度传感器运行正常的情况下，如果手柄温度达到68℃，则视为过热保护触发。此时手柄将会立即关机并以黄色闪烁五次作为过热保护触发的提示。进入过热保护后，风扇手柄将拒绝开机和任何其他操作（查询温度和电压除外）此时用户的任何其余按键操作和开机尝试都将被忽略，并以按键灯黄色闪五次作为提示。在过热保护触发后，当手柄温度回落到49度以下后，将解除过热保护并允许正常开机。

### 温度传感器故障保护

驱动的固件在每次开机运行期间，以及上电初始化期间，都会对温度传感器进行检测。如果在开机期间检测到温度传感器故障，手柄将禁止运行并且以红黄绿快速交错闪，停顿1秒后反复循环的灯光序列提示用户。在手柄运行期间，如果温度传感器故障超过1秒，则手柄视为温度传感器故障保护触发，此时手柄将会立即关机并以红色闪烁五次作为温度传感器故障保护触发的提示。触发保护后，当温度传感器正常运行并返回合法温度数据后，故障保护将解除并允许正常开机。

## 风扇调速模式配置

该风扇驱动在硬件PCBA的背部有一个标识为P的电阻焊盘位置（如下图所示）用于设置固件的工作模式：
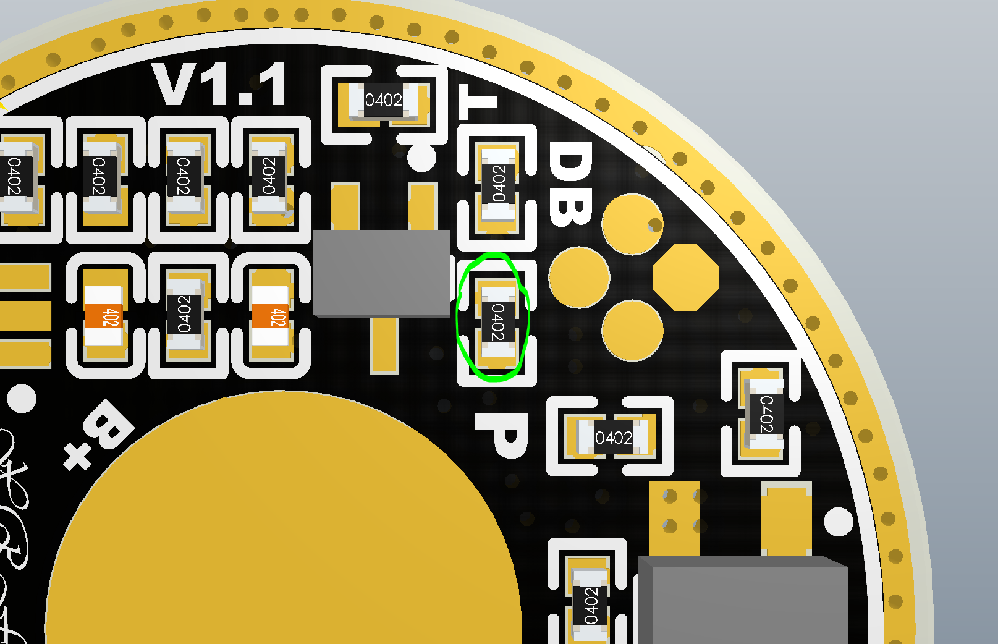
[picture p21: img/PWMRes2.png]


在每次上电时，固件将会自动识别该电阻的状态并切换模式。该电阻安装时固件将会工作于PWM调速模式（该模式适配四线暴力风扇）。此时风扇驱动始终固定输出12V电压，风扇速度由驱动输出的PWM信号控制。**此时固件不支持使用只有电源线的2线或只有电源+转速反馈的3线风扇。如果强行使用会导致风扇始终全速无法调速！** 如果您需要使用`2线或3线的不支持PWM调速的风扇`则需要去除该电阻并配置为电压调速模式。此时系统将会禁用PWM信号输出并通过调控风扇电压对风扇速度进行控制。**需要注意的是，如果你的风扇是高转速暴力风扇，则因为风扇的启动电压通常较高导致电压模式下调速范围会极窄。此时将会出现部分挡位电压过低导致风扇无法启动的问题。因此作者建议在搭配暴力风扇使用时开启PWM调速模式。**

同时需要注意的是，由于该驱动仅支持升压，因此风扇电压应始终高于电池电压。为了保证电压模式下调速范围正常，如果您配置驱动使用电压调速模式，则驱动将会禁用双锂电支持。此时若装入两节锂电池，驱动将会拒绝运行并报错。仅四线PWM调速模式并搭配四线PWM风扇时，支持双锂电池运行。

## 电池参数配置

**重要提醒：默认的硬件配置为了最强的单锂输出性能使用了小电感量的电感。因此单锂暴力模式的驱动不支持双锂，所有的电池节数识别和切换将被永久禁用且不允许更改电池配置，您可以忽略本章节的内容。对于单锂暴力输出模式的驱动，如果强行使用双锂会导致芯片承受过大峰值电流而过载损坏！如果您通过贴装更大电感量的电感解锁了双锂模式并且需要再单双锂之间切换，则请查看下面的内容。**

该风扇驱动同时支持单锂和双锂电的操作，在电池配置未锁定的情况下，风扇手柄可以自动检测双锂电的插入并切换为双锂电池模式。对于电池配置模式用户也可以随时进行调整。**需要注意的是，如果系统处于电压调速模式，则电池参数配置将不支持，且系统永远只能工作于单锂模式。** 对于如何确认系统当前的电池配置以及调整配置、识别系统异常等，请参考如下内容：

+ 识别系统当前的电池配置：在每次装入电池时，电量指示灯会进行自检并显示当前电池电量。如果当前系统开启了双锂电模式，则系统在装入电池后首先会以黄色快闪2次，延迟0.5秒后再显示电池电量（假设电量充足，则指示灯将绿色常亮3秒）。若当前为单锂模式，则驱动将会直接提示电池电量。
+ 双锂电自动识别功能：当系统处于单锂电模式且电池配置未锁定时，如果用户装入两节电池，则系统会检测到并自动切换至双锂模式。此时系统会通过绿色快速频闪2秒作为检测到双锂的提示，并在2秒后以双锂模式重新启动。
+ 电池状态异常识别：为了避免用户装入不匹配的电池导致驱动工作异常或者引起电池过度放电，系统会根据当前的电池配置对电池进行状态验证。如果您在装入电池后看到颈部开关以红色持续高频闪烁，则说明系统检测到电池异常，请检查电池是否和系统设置匹配。**例如，在单锂电模式下装入了2节电池，或在双锂电模式下装入了三节电池，都会触发保护。**
+ 切换单锂/双锂模式：在电池配置没有锁定的情况下，用户可以通过在关机状态下五击+长按切换单锂和双锂模式。当切换为单锂模式时，风扇手柄的侧按将会通过红色频闪一次提示已经成功切换。如果是切换为双锂模式，则扇手柄的侧按将会通过绿色频闪2次提示成功切换。**需要注意的是，如果系统当前安装了2节电池，为了保护电池避免过度放电，此时系统将会禁止用户切换为单节锂电池模式。如果您需要从双锂模式切换至单锂模式，请将电池取出并仅安装一节电池，再进行切换操作。**
+ 电池配置锁定：对于面向成品手电客户的场合，为了避免用户擅自更改电池配置引起问题，您可以在设置好系统的电池配置后对电池配置进行半永久性锁定。触发锁定的方法是在关机状态下连续八击按键，成功锁定后风扇手柄将会以绿色闪烁三次作为提示。在锁定后，用户将无法通过五击+长按的方式切换电池配置，同时系统也不会自动识别双锂电的装入并自动配置为双锂模式。**该锁定操作为半永久性操作，一旦执行将无法撤销。如果确实因为意外情况需要撤销，则需要重新刷写固件。**

## 编译固件时MCU的CONFIG配置

由于中微单片机内部有一组硬编码于Flash指定区域，用于设置单片机的硬件首选项（例如看门狗，调试模式，低电压保护点等）的配置Word。为了确保编译出来的固件可以在硬件内正常运行，您需要在工程配置(Options for Target 'XRFan'->Debug选项卡->右上角的Settings按钮)的Config设置菜单，按照下表正确填写MCU的配置。错误的CONFIG设置会引起固件工作异常！

+ Power                      :  Inter 3.3V            
+ WDT                        :  SOFTWARECONTROL     
+ PROTECT                    :  ENABLE              
+ FLASH_DATA_PROTECT         :  ENABLE              
+ LVR                        :  2.0V                
+ DEBUG                      :  Disable             
+ OSC                        :  HSI                 
+ OSC_PRESCALE               :  Fosc/1              
+ HSI_FS                     :  Fhsi/1              
+ EXT_RESET                  :  DISABLE             
+ EXT_RESETSEL               :  P00                 
+ WAKEUP_WAITTIME            :  500us               
+ CPU_WAITCLOCK              :  2T                  
+ WRITE_PROTECT[0-2K]        :  DISABLE             
+ WRITE_PROTECT[2-4K]        :  DISABLE             
+ WRITE_PROTECT[4-6K]        :  DISABLE             
+ WRITE_PROTECT[6-8K]        :  DISABLE             
+ WRITE_PROTECT[8-10K]       :  DISABLE             
+ WRITE_PROTECT[10-12K]      :  DISABLE             
+ WRITE_PROTECT[12-14K]      :  DISABLE             
+ WRITE_PROTECT[14-16K]      :  DISABLE             
+ BOOT                       :  BOOT_DIS 

----------------------------------------------------------------------------------------------------------------------------------
© redstoner_35 @ 35's Embedded Systems Inc.  2026

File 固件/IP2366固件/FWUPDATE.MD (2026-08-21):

powered by 35's Embedded Systems Inc. An Open-Source High Power Flood FlashLight Solution    

### 固件升级的目的

英集芯IP2366原厂的固件处于安全性考虑（避免充电倍率过高以及硬件受不住炸管）具有电池连续电流和峰值电流限制。默认设置是9.4A峰值电流，7A的最大连续电池电流。因此使用原厂固件时四串最高的充电输入功率只能达到100W。为了实现GT-X2的四串电池子系统也可以达到满血不降流的140W充放电，因此我特意找原厂的技术部门定制了无任何充电电流限制的特殊固件。实测在任何电池电压条件下输入均能达到接近甚至超过140W的功率。并且特殊固件修复了原版PPS协议的bug，支持增强的PD3.0 PD Fix(20V7A)以及可以被手机使用进行100W快充的的6A PPS1和PPS2。

### 如何升级固件

英集芯的IP2366实际上是一个软件定义的电源SoC，因此通过官方的专用烧录硬件可以通过芯片引出的充放电 USB-Type-C接口进行升级。升级流程是首先将电池架上的电池全部拆下，等待2分钟确保电池架的电容内没有任何残余电能（**这一步极其重要！如果在芯片连接了电池的状态下尝试升级，会导致芯片固件不完整引起芯片死机甚至永久性损坏芯片内部底层数据，使芯片永远变砖无法使用和再次烧录！**）。然后通过C to C线连接电池架和烧录器。接着把烧录器连接至电脑，将解密后的固件原始bin复制到烧录器的盘符里面。然后按照烧录器操作文档进行操作升级（这份固件升级指引可以问原厂代理要）

### 如果我没有烧录器怎么办呢？

有些具有原厂代理资格的英集芯分销代理具有这个烧录工具，可以在购买IP2366芯片时提供定制固件的原始bin文件给他们并让他们在出货之前烧录好。需要注意的是，该定制固件仅支持D版本芯片，因此务必让卖家确认芯片版本。

### 特殊固件为什么加密了？

考虑到无限制充电固件在充电限流方面没有任何限制，如果用户使用的电池不足以承受140W满功率充电的倍率将会造成严重的事故，为了安全起见，该固件仅限定在特定情况提供。同时该固件属于定制固件，涉及到原厂合作关系方面的复杂事情，因此不能直接提供原始的固件文件以防止溯源攻击。如您确实需要复刻该项目，且希望得到满功率140W的充放能力，您可在BLF论坛，找到作者的[个人主页](https://budgetlightforum.com/u/redstoner_35/activity)通过PM联系作者进行资格审查，当通过资格审查后，即可获取该定制固件的解压密码。

对于未通过资格审查的用户，您可直接使用官方的IP2366_BZ版本芯片。使用该版本芯片则最大充电功率将会限制在100W，并且不支持增强的PD功能。作者也提供了将IP2366芯片刷写至非定制BZ模式所需的[固件文件](/IP2366_BZ_D_ENP_YATJE_m.bin)。您只需要将固件发送给芯片卖家即可完成烧录。

----------------------------------------------------------------------------------------------------------------------------------
© redstoner_35 @ 35's Embedded Systems Inc.  2026

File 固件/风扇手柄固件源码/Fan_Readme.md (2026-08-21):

powered by 35's Embedded Systems Inc. A Next generation FlashLight Driver Solution     

### 概述

Xtern Ripper HyperFanDriver(HFD)是一款全新设计的侧按单锂升压驱动12V暴力风扇驱动，针对本手电所选配的基于东东海F1A风扇辅助散热手柄半成品五金套料所实现的风扇主动散热手柄DLC而设计。相比于市面上使用成品手电驱动（例如飞翔尾按单锂升压6V LED驱动）魔改的版本具有更低的输出纹波和更高的稳定性。该驱动同时支持2线电压调速风扇和四线PWM风扇。单锂模式下使用单节21700锂电池即可实现30W实际功率的34000RPM风扇持续运行并让手电达到2万LM的持续常亮。

### 性能数据

+ 支持的电池输入类型：1-2S三元锂电池，持续放电能力应大于20安培。
+ 支持的风扇类型：12V额定工作电压的直流无刷风扇，2线电压调速或四线PWM调速均可
+ 支持的风扇电流和功率：单锂条件下30W(12V 2.5A) 双锂串联条件下72W(12V6A) **注意：本处所标称的电流为支持的风扇实际电流而非风扇标签上所写的电流，只要保证风扇的实际运行电流不超过限制即可。例如建准XF40281BX风扇的标签电流为3A，但实际运行电流为2.25A，此时风扇是可以正常使用的**
+ 电池保护：具有欠压自动降档和关机保护以及过电压保护

### 总体操作逻辑

该风扇驱动同时具备无级调速和阶梯挡位调速可以随时选择。同时还具备双击一键全速功能。对于风扇的操作逻辑可以参考如下：
逻辑图

对于图中的部分未详尽解释的特殊逻辑，则可参考如下内容：

+ 按键锁：关机状态下五击开关，侧按指示灯红色闪三次进入锁定模式，此时除了双击+长按查询当前电池电量意外的其余任何操作无效。**为了保证安全，进入锁定模式后即使重新安装电池，风扇也会始终保持在锁定状态。** 在锁定状态下再次五击，侧按指示灯绿色闪烁三次，并且风扇低速运转1.5秒，表示成功解锁，此时风扇可以正常操作。

+ 查询电量：任意状态下通过双击+长按进入。当进入电量查询模式后风扇的颈部开关指示灯首先将会以红黄绿依次点亮的方式作为先导提示，提示用户风扇即将开始显示电池电压和电量。延迟1秒后风扇将通过红色，黄色和绿色的指定次数的慢速闪烁（如果快速闪烁一次，则表示该数据位为0）提示用户当前的电池电压，播报完电池当前电压后，风扇将会在延迟2秒后通过后续的长亮(或者慢闪)提示用户当前电池电压对应的总体电量水平（指示方式参考下文中驱动位于正常工作时的指示），对于电池具体电压播报的计算方式请参考如下内容：
  - 红色闪烁次数+黄色闪烁次数x0.1+绿色闪烁次数x0.01=当前电池电压(V)，例如`红色慢闪4次-黄色慢闪1次-绿色慢闪3次`表示电池电压为4+1*0.1+3x0.01=4.13V。

+ 设置按键有源夜光功能：关机状态下七击按键，风扇的侧按指示灯以绿色快闪一次表示功能开启。若以红色快闪一次则表示功能关闭。该功能开启后，风扇手柄将会在闲置未用且电池电压充足的情况下令按键发出微弱绿光指示风扇手柄的开关位置。
+ 恢复出厂设置：在手柄处于断电状态下，持续按住按钮并装入电池。此时手柄的侧部按键指示灯将会以黄色的持续高频率快闪提示用户已恢复出厂设置。用户松开按键后2秒，手柄将会自动重启并进入正常工作状态。需要注意的是，恢复出厂设置并不能清除电池配置锁定。

### 电池参数配置

该风扇驱动同时支持单锂和双锂电的操作，在电池配置未锁定的情况下，风扇手柄可以自动检测双锂电的插入并切换为双锂电池模式。对于电池配置模式用户也可以随时进行调整。**需要注意的是，如果系统处于电压调速模式，则电池参数配置将不支持，且系统永远只能工作于单锂模式。** 对于如何确认系统当前的电池配置以及调整配置、识别系统异常等，请参考如下内容：

+ 识别系统当前的电池配置：在每次装入电池时，电量指示灯会进行自检并显示当前电池电量。如果当前系统开启了双锂电模式，则系统在装入电池后首先会以黄色快闪2次，延迟0.5秒后再显示电池电量（假设电量充足，则指示灯将绿色常亮3秒）。若当前为单锂模式，则驱动将会直接提示电池电量。
+ 双锂电自动识别功能：当系统处于单锂电模式且电池配置未锁定时，如果用户装入两节电池，则系统会检测到并自动切换至双锂模式。此时系统会通过绿色快速频闪2秒作为检测到双锂的提示，并在2秒后以双锂模式重新启动。
+ 电池状态异常识别：为了避免用户装入不匹配的电池导致驱动工作异常或者引起电池过度放电，系统会根据当前的电池配置对电池进行状态验证。如果您在装入电池后看到颈部开关以红色持续高频闪烁，则说明系统检测到电池异常，请检查电池是否和系统设置匹配。**例如，在单锂电模式下装入了2节电池，或在双锂电模式下装入了三节电池，都会触发保护。**
+ 切换单锂/双锂模式：在电池配置没有锁定的情况下，用户可以通过在关机状态下五击+长按切换单锂和双锂模式。当切换为单锂模式时，风扇手柄的侧按将会通过红色频闪一次提示已经成功切换。如果是切换为双锂模式，则扇手柄的侧按将会通过绿色频闪2次提示成功切换。**需要注意的是，如果系统当前安装了2节电池，为了保护电池避免过度放电，此时系统将会禁止用户切换为单节锂电池模式。如果您需要从双锂模式切换至单锂模式，请将电池取出并仅安装一节电池，再进行切换操作。**
+ 电池配置锁定：对于面向成品手电客户的场合，为了避免用户擅自更改电池配置引起问题，您可以在设置好系统的电池配置后对电池配置进行半永久性锁定。触发锁定的方法是在关机状态下连续八击按键，成功锁定后风扇手柄将会以绿色闪烁三次作为提示。在锁定后，用户将无法通过五击+长按的方式切换电池配置，同时系统也不会自动识别双锂电的装入并自动配置为双锂模式。**该锁定操作为半永久性操作，一旦执行将无法撤销。如果确实因为意外情况需要撤销，则需要重新刷写固件。**

### 风扇调速模式配置

该风扇驱动在硬件PCBA的背部有一个标识为P的电阻焊盘位置（如下图所示）用于设置固件的工作模式：
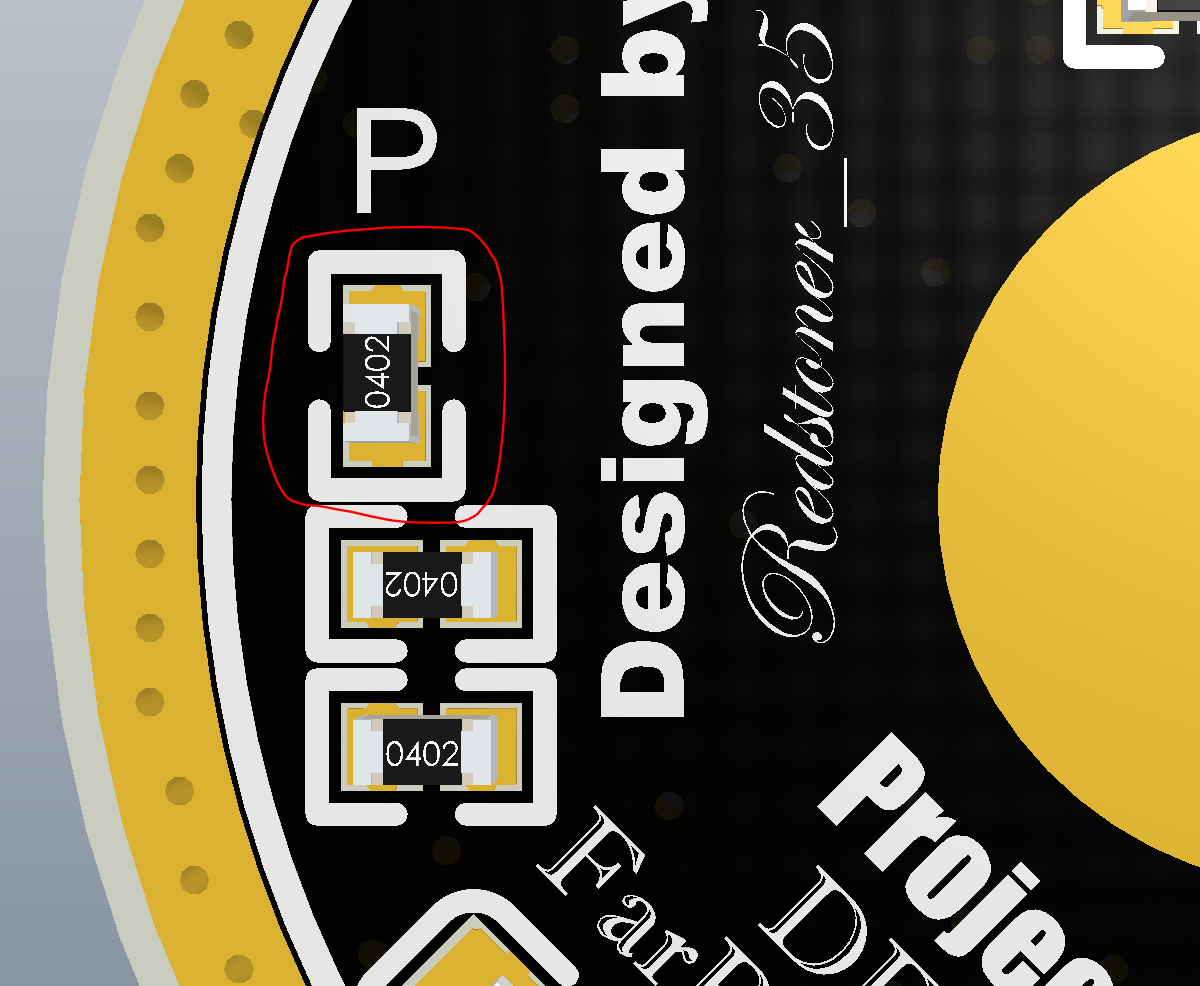
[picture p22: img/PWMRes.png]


在每次上电时，固件将会自动识别该电阻的状态并切换模式。该电阻安装时固件将会工作于PWM调速模式（该模式适配四线暴力风扇）。此时风扇驱动始终固定输出12V电压，风扇速度由驱动输出的PWM信号控制。**此时固件不支持使用只有电源线的2线或只有电源+转速反馈的3线风扇。如果强行使用会导致风扇始终全速无法调速！** 如果您需要使用`2线或3线的不支持PWM调速的风扇`则需要去除该电阻并配置为电压调速模式。此时系统将会禁用PWM信号输出并通过调控风扇电压对风扇速度进行控制。**需要注意的是，如果你的风扇是高转速暴力风扇，则因为风扇的启动电压通常较高导致电压模式下调速范围会极窄。此时将会出现部分挡位电压过低导致风扇无法启动的问题。因此作者建议在搭配暴力风扇使用时开启PWM调速模式。**

同时需要注意的是，由于该驱动仅支持升压，因此风扇电压应始终高于电池电压。为了保证电压模式下调速范围正常，如果您配置驱动使用电压调速模式，则驱动将会禁用双锂电支持。此时若装入两节锂电池，驱动将会拒绝运行并报错。仅四线PWM调速模式并搭配四线PWM风扇时，支持双锂电池运行。

### 编译固件时MCU的CONFIG配置

由于中微单片机内部有一组硬编码于Flash指定区域，用于设置单片机的硬件首选项（例如看门狗，调试模式，低电压保护点等）的配置Word。为了确保编译出来的固件可以在硬件内正常运行，您需要在工程配置(Options for Target 'XRFan'->Debug选项卡->右上角的Settings按钮)的Config设置菜单，按照下表正确填写MCU的配置。错误的CONFIG设置会引起固件工作异常！

+ Power                      :  Inter 3.3V            
+ WDT                        :  SOFTWARECONTROL     
+ PROTECT                    :  ENABLE              
+ FLASH_DATA_PROTECT         :  ENABLE              
+ LVR                        :  2.0V                
+ DEBUG                      :  Disable             
+ OSC                        :  HSI                 
+ OSC_PRESCALE               :  Fosc/1              
+ HSI_FS                     :  Fhsi/1              
+ EXT_RESET                  :  DISABLE             
+ EXT_RESETSEL               :  P00                 
+ WAKEUP_WAITTIME            :  500us               
+ CPU_WAITCLOCK              :  2T                  
+ WRITE_PROTECT[0-2K]        :  DISABLE             
+ WRITE_PROTECT[2-4K]        :  DISABLE             
+ WRITE_PROTECT[4-6K]        :  DISABLE             
+ WRITE_PROTECT[6-8K]        :  DISABLE             
+ WRITE_PROTECT[8-10K]       :  DISABLE             
+ WRITE_PROTECT[10-12K]      :  DISABLE             
+ WRITE_PROTECT[12-14K]      :  DISABLE             
+ WRITE_PROTECT[14-16K]      :  DISABLE             
+ BOOT                       :  BOOT_DIS 

----------------------------------------------------------------------------------------------------------------------------------
© redstoner_35 @ 35's Embedded Systems Inc.  2026

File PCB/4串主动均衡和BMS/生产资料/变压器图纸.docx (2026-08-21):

变压器图纸数据

变压器骨架：ER14.5立式 6+6Pin SMD骨架（如下图所示）

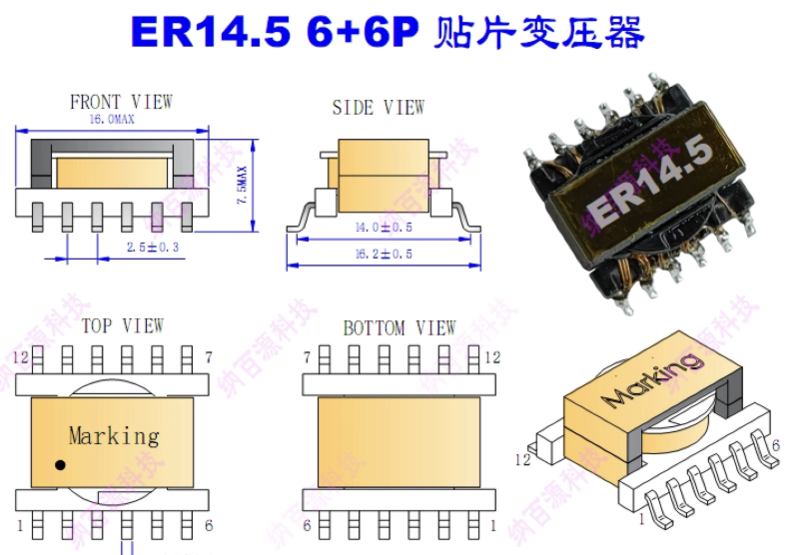
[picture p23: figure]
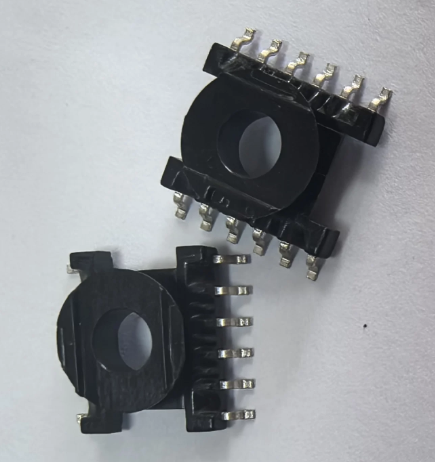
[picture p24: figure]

磁芯材质：TDK PC40（不能用其他材质否则不工作）

漆包线材质：QA-155 0.2mm高温漆包线

绝缘胶带材质：黄色Myler胶带（也可用聚酰亚胺茶色胶带）

绕制参数：每组绕组7+7T，中心抽头引出。绕组需要按照如下实物映射图进行接线：

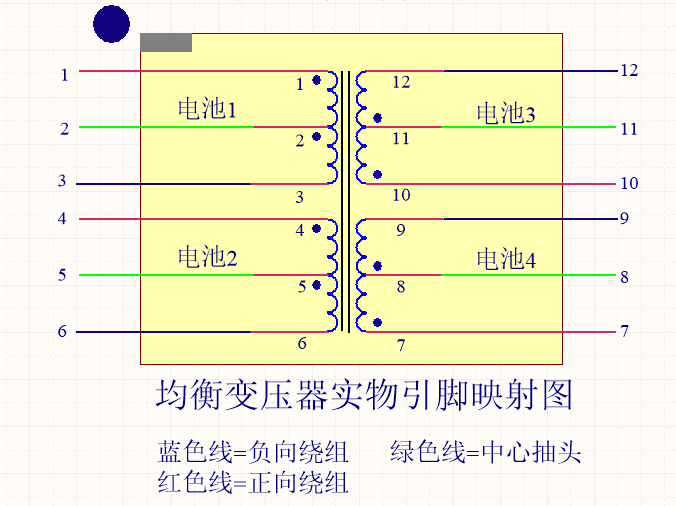
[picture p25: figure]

绝缘要求：每组绕组之间应额外使用胶带增强绝缘。绕组和绕组之间的绝缘强度应至少达到250VAC 50Hz 一分钟工频交流耐压试验不出现跳火/爬电现象。

气隙要求：磁芯无需预留气隙。

绕组和磁芯固定要求：变压器在绕制期间以及绕制结束后，所有绕组应当浸漆固定。不得出现绕组松脱，散线的现象。磁芯应当使用专门的固定胶和骨架永久固定，成品不得出现磁芯松脱和晃动现象。

成品电参数检验要求：使用LCR表和直流低阻测试仪，测量四个绕组的电感量和直流电阻。四个绕组之间的电参数误差不得超过±2%，否则视为不合格。使用30KHz方波信号发生器作为激励源，挑选其中一个绕组作为输入端，使用示波器测量其余任意绕组的两端作为输出波形，所有被测绕组的相位应当和接线图符合。

变压器成品参考图如下：

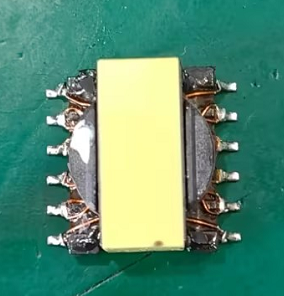
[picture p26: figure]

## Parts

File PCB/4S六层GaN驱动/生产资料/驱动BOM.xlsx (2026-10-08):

料号 | 描述 | 位号 | 封装 | 数量 | 单价 | 总价
PA25V470M6x12 | 直插固态电容，耐压25V容量470uF，尺寸D6.3x12 | C1, C2 | CAP-D6.3/L12.0 | 2 | 1.32 | 2.64
SH430V35R680D6x18 | 升阳电子 直插特殊尺寸固态电容 680uF ±20% 35V 直径63mm长度18mm 2000Hr@105℃ | C3 | CAP-D6.3/L12.0 | 1 | 0.59 | 0.59
PH35V330M8X12 | 125°C 5000Hrs 高温耐受直插固态电容。 耐压35V容量330uF，尺寸D8mmxL12mm | C4, C16 | CAP-D8.0/L12.5 | 2 | 1.8 | 3.6
100nF (104) 10% 50V | 贴片电容 | C5, C8, C32, C35, C36, C38, C40, C41, C43, C46, C49, C69, C74 | 0402_C | 13 | 0.07 | 0.91
GRM155R61E475ME15D | 0402贴片MLCC电容 4.7uF±20% 25V X5R | C6, C68 | 0402_C | 2 | 0.92 | 1.84
GRM1555C1H682JE01D | 0402贴片MLCC电容 6.8nF±5% 50V C0G/NP0 | C7, C48 | 0402_C | 2 | 0.11 | 0.22
10uF (106) 20% 10V | 0402贴片电容 | C9, C61, C63, C64, C71, C75 | 0402_C | 6 | 0.48 | 2.88
CGA2B1X7R1V224KT000F | 车规级 0402贴片MLCC电容 35V 220nF±10% X7R | C10, C62 | 0402_C | 2 | 0.28 | 0.56
GRM188R61E106KA73D | 贴片MLCC电容 25V 10uF±20% X5R | C11, C13, C14, C34, C39, C73 | 0603_C | 6 | 0.4 | 2.4
TAJA226M016RNJ | 1206钽电容，22uF (226) ±10% 16V | C12 | CASE-A_3216 | 1 | 3.1 | 3.1
C2012X5R1A476MTJ00E | 贴片MLCC电容，X5R 47uF ±20% 10V | C15 | 0805_C | 1 | 1.41 | 1.41
CC0402JRNPO9BN681 | 0402贴片MLCC电容 NP0材质 680pF ±5% 50V | C17 | 0402_C | 1 | 0.06 | 0.06
47nF (473) 10% 50V | 贴片电容 | C18 | 0402_C | 1 | 0.03 | 0.03
C3216X5R1V226MTJ00E | TDK MLCC电容 X5R 35V 22uF±20% | C19, C20, C21, C22, C23, C51, C52, C53, C54, C58, C66, C67 | 1206_C | 12 | 3.49 | 41.88
GMK325BJ226MM-P | 1210 MLCC电容 35V 22uF ±20% X5R | C24 | 1210_C | 1 | 3.10 | 3.1
GRM31CR61E476ME44L | 1206尺寸村田MLCC 25V 47uF X5R ±20% | C25, C26, C27, C28, C29, C30, C57, C65 | 1206_C | 8 | 4.3 | 34.4
GRM1555C1E103JE01D | 0402贴片MLCC电容 10nF±5% 25V C0G/NP0 | C31 | 0402_C | 1 | 0.77 | 0.77
470pF (471) 10% 50V | 贴片电容 | C33 | 0402_C | 1 | 0.03 | 0.03
150nF (154) 10% 16V | 贴片电容 | C37 | 0402_C | 1 | 0.03 | 0.03
22uF (226) 20% 25V | 贴片电容 | C42 | 0805_C | 1 | 0.7 | 0.7
2.2uF (225) 10% 10V | 贴片电容 | C44, C45 | 0402_C | 2 | 0.3 | 0.6
1nF (102) 10% 50V | 贴片电容 | C47 | 0402_C | 1 | 0.03 | 0.03
4.7uF (475) 20% 16V | 贴片电容 | C55, C72 | 0402_C | 2 | 0.26 | 0.52
1.0uF (105) 10% 25V | 贴片电容 | C56 | 0402_C | 1 | 0.16 | 0.16
GRM1555C1H102FA01D | 村田0402贴片MLCC电容 1nF ±1% 50V C0G | C59, C60 | 0402_C | 2 | 0.17 | 0.34
22nF (223) 10% 50V | 贴片电容 | C70 | 0402_C | 1 | 0.03 | 0.03
BAS100CS-AU_R1_000A1 | 超低结电容/漏电流肖特基二极管 0.5A 100V | D1, D2 | SOD-323 | 2 | 0.12 | 0.24
1N4148WS T4 | 高速开关二极管 | D3, D8 | SOD-323 | 2 | 0.05 | 0.1
BAV70W A4 | 共阴极高速开关二极管阵列 | D4 | SC70-3 | 1 | 0.18 | 0.18
XL-1608BGWC-06 | 0603(1608)贴片冰蓝色发光二极管 2.7-3.4V 20mA | D5, D9 | LED-0402 | 2 | 0.02 | 0.04
PT30L80SP | 30A 80V 肖特基二极管 | D6 | TO277 | 1 | 1 | 1
B5819WS S4 | 1A电流常规肖特基二极管 | D7 | SOD-323 | 1 | 0.13 | 0.13
RLSD32A051V | 单向TVS二极管 5V工作电压 峰值脉冲电流：21A@8/20us | D10 | SOD-323 | 1 | 0.32 | 0.32
MAF1005GAD352AT000 | 贴片铁氧体磁珠 270mA 500R@100MHz | FB1 | 0402_L | 1 | 0.43 | 0.43
EBMS100505A050 | 贴片磁珠 200mA 5R±25% 100MHz | FB2, FB3 | 0402_L | 2 | 0.02 | 0.04
XAL1580-102ME | 线艺XAL1580系列电感 1uH 0.93mΩ 73A饱和 | L1, L2 | IND_SMD_XAL1580 | 2 | 27 | 54
ZEMS252012-220M | 一体成型TCORE热压功率电感 2.5x2.0mm尺寸 1.0mm高度 22uH 0.78Ω 1.2A | L3, L4 | SWPA252010S | 2 | 0.32 | 0.64
INN100EBD018DAD | 基于先进GaN技术的100V硅基氮化镓增强型HEMT 晶体管，采用En-FCLGA 5mm x 6mm 封装。 | Q1, Q3 | EN-FCLGA-8_L6.0-W5.0-P1.27-BL-EP | 2 | 35 | 70
INN100EA035EAD | 100V Enhancement-mode GaN Power Transistor, 2.7mΩ Gen3.5 | Q2, Q4, Q6, Q7 | FCLGA-8_L3.3-W3.3-BL-EP | 4 | 14.9 | 59.6
IAUCN04S7L004ATMA1 | 0.44mΩ 40V 逻辑电平 OptiMOS 7 车规级MOSFET | Q5 | SuperSO8_L6.0_W5.0_FusedLead | 1 | 16.33 | 16.33
ASR-M-3-0.75F | 业展ASR系列精密检流电阻，2512 0.75mΩ±1% 锰铜材质 <50ppm/K P70℃=5W | R1, R2 | RES_2512 | 2 | 1.41 | 2.82
1Ω (1R00) ±1% | 贴片电阻 | R3 | 0402_R | 1 | 0.03 | 0.03
16.2KΩ (1622) ±1% | 贴片电阻 | R4 | 0402_R | 1 | 0.03 | 0.03
2KΩ (2001) ±1% | 贴片电阻 | R5, R31 | 0402_R | 2 | 0.03 | 0.06
1.2KΩ (1201) ±1% | 贴片电阻 | R15 | 0402_R | 1 | 0.03 | 0.03
1.5Ω (1R50) ±1% | 贴片电阻 | R6, R9, R44, R46 | 0402_R | 4 | 0.03 | 0.12
PTFR0402B51R0N9 | 0402贴片薄膜高精密电阻 51Ω ±0.1% 62.5mW 25PPM | R7, R43 | 0402_R | 2 | 1.04 | 2.08
0.5Ω (0R50) ±1% | 贴片电阻 | R10, R47,R8, R45 | 0402_R | 4 | 0.03 | 0.12
RT0402BRD0720KL | 0402贴片薄膜高精密电阻 20KΩ ±0.1% 62.5mW 25PPM | R11 | 0402_R | 1 | 0.58 | 0.58
4.7KΩ (4701) ±1% | 贴片电阻 | R12, R32 | 0402_R | 2 | 0.03 | 0.06
MCSM2512DR001K9 | 精密低温漂束焊模压合金检流电阻 车规级别 1.0mΩ ±0.5% 3W | R13 | RES_2512 | 1 | 0.8 | 0.8
RT0402BRD07130KL | 0402贴片薄膜高精密电阻 130KΩ ±0.1% 62.5mW 25PPM | R14 | 0402_R | 1 | 0.17 | 0.17
1.2MΩ (1204) ±1% | 贴片电阻 | R16 | 0402_R | 1 | 0.03 | 0.03
AT0402BRD0791KL | 0402贴片薄膜高精密电阻 91KΩ ±0.1% 62.5mW 25PPM | R17 | 0402_R | 1 | 0.28 | 0.28
10KΩ (1002) ±1% | 贴片电阻 | R18, R19, R26, R27, R54, R55 | 0402_R | 6 | 0.03 | 0.18
RE0402BRF07820KL | 0402精密低温飘贴片电阻 820K±0.1% 62.5mW | R20 | 0402_R | 1 | 0.19 | 0.19
AR02BTD4703 | 0402 贴片薄膜高精密低温飘电阻 470KΩ±0.1% 25PPM | R21, R34 | 0402_R | 2 | 0.20 | 0.4
ERA2AEB104X | 松下 0402精密低温飘贴片电阻 100±0.1% 62.5mW | R22 | 0402_R | 1 | 0.43 | 0.43
RT0402BRD0756KL | 0402薄膜贴片高精密电阻 56K±0.1% 62.5mW | R23 | 0402_R | 1 | 0.17 | 0.17
20KΩ (2002) ±1% | 贴片电阻 | R24, R25, R53 | 0402_R | 3 | 0.03 | 0.09
1KΩ (1001) ±1% | 贴片电阻 | R28 | 0402_R | 1 | 0.03 | 0.03
RC0402DR-07330KL | 0402厚膜较高精度贴片电阻 330KΩ±0.5% 62.5mW | R29 | 0402_R | 1 | 0.03 | 0.03
FNTC0402X104D4250DB | 0402尺寸贴片式NTC热敏电阻 B25-85℃=4310±0.5% R25=100KΩ±0.5% | R30 | 0402_R | 1 | 0.38 | 0.38
ERA2AEB912X | 松下高精密0402贴片薄膜电阻 9.1KΩ ±0.1% 62.5mW 5PPM | R33 | 0402_R | 1 | 0.74 | 0.74
RT0402BRD0782K5L | 薄膜低温飘高精密电阻 82.5KΩ (8242) ± 0.1% 25PPM | R35 | 0402_R | 1 | 0.16 | 0.16
5.1Ω (5R10) ±1% | 贴片电阻 | R36, R37 | 0603_R | 2 | 0.03 | 0.06
91KΩ (9102) ±1% | 贴片电阻 | R38 | 0402_R | 1 | 0.03 | 0.03
0Ω (0R0) ±1% | 贴片电阻 | R39, R40 | 0402_R | 2 | 0.03 | 0.06
RN73R1ETTP2703B25 | KOA RN73系列0402贴片薄膜高精密电阻 270KΩ±0.1% 62.5mW ±25PPM | R41 | 0402_R | 1 | 0.87 | 0.87
TC0250B1203TCC | 镍铬薄膜高精密0402贴片电阻 120KΩ ±0.1% 25PPM | R42 | 0402_R | 1 | 0.15 | 0.15
4.7Ω (4R70) ±1% | 贴片电阻 | R48, R49 | 0402_R | 2 | 0.03 | 0.06
RT0402BRD07127KL | 精密高稳定性0402贴片电阻 127KΩ ±0.1% 25PPM | R50 | 0402_R | 1 | 0.16 | 0.16
PTFR0402B24K3N9 | 高精密高稳定性0402贴片电阻 24.3KΩ ±0.1% 5PPM | R51 | 0402_R | 1 | 0.58 | 0.58
7.5KΩ (7501) ±1% | 贴片电阻 | R52 | 0402_R | 1 | 0.03 | 0.03
LTC7892AUJM#WTRPBF | Low IQ , Dual, 2-Phase Synchronous Boost Controller for GaN FETs, AEC-Q100 Certified | U1 | UJM0040A | 1 | 86 | 86
LGS5148 | 48V输入，600mA同步降压转换器，SOT-23-6封装 | U2, U12 | SOT23_6 | 2 | 1.55 | 3.1
UCC27614DSGR | 10A峰值电流驱动能力的单路低侧栅极驱动器， 17.5nS典型传播延迟，WSON8封装 | U3 | DSG0008A | 1 | 13.55 | 13.55
TPS7B6950QDBVRQ1 | 150mA 40V max input Ultra low Iq LDO,fixed 5V output AECQ100 Qualified | U4, U7 | SOT23_5 | 2 | 2.16 | 4.32
INA214AIDCKR | 100V/V增益 26V最高共模电压，高低侧通用双向 高精度检流放大器 SC70-6封装 | U5 | SC70-6 | 1 | 4.25 | 4.25
OPA388IDBVR | 单路、10MHz、CMOS、零温漂、零交叉、 真 RRIO 精密运算放大器 | U6 | SOT23_5 | 1 | 5.35 | 5.35
CMS8S6990NAQN20 | 中微增强型闪存1T 8051单片机，16KB Flash 256+1K XRAM | U8 | QFN3*3_20L | 1 | 1.13 | 1.13
OPA333AIDCKT | 微功耗、1.8V、17uA 零漂移 CMOS 精密运算放大器，SC70-5封装 | U9 | SC70-5 | 1 | 3.63 | 3.63
CH412K | very low capacity quad IO ESD protection Array | U10 | SC70-6 | 1 | 1.59 | 1.59
LMV321IDCKR | CMOS超小型通用运算放大器，SC70-5 | U11 | SC70-5 | 1 | 0.42 | 0.42
Cu_3AU_D1.0_L1.5 | 中通达SMT圆柱镀金铜柱，直径1.0， 高度1.5，镀金3U | N/A | Cu_D1.0_L1.5 | 5 | 0.35 | 1.75
Cu_TIN_L10.0_W4.0_H2.0 | 中通达SMT镀锡铜片，长10mm，宽度4mm， 厚度2mm | N/A | Cu_L10.0_W4.0_H2.0 | 2 | 0.7 | 1.4
Cu_1AU_L5.0_W5.0_H1.5 | 中通达SMT镀金铜片，长5mm，宽5mm 高度1.5，镀金1U | N/A | Cu_L5.0_W5.0_H1.5 | 4 | 0.42 | 1.68
Cu_1AU_L6.0_W2.0_H0.5 | 中通达SMT镀金铜片，长6mm，宽2mm 高度0.5，镀金1U | N/A | Cu_L6.0_W2.0_H0.5 | 2 | 0.35 | 0.7
Cu_1AU_L2.0_W2.0_H1.2 | 中通达SMT镀金铜片，长2mm，宽2mm 高度1.2，镀金1U | N/A | Cu_L2.0_W2.0_H1.2 | 2 | 0.4 | 0.8
Cu_1AU_L2.5_W2.5_H1.9 | 中通达SMT镀金铜片，长2.5mm，宽2.5mm 高度1.9，镀金1U | N/A | Cu_L2.5_W2.5_H1.9 | 1 | 0.4 | 0.4
Cu_MID_POSConduct | CNC正极中心倒流条，雾锡处理 | N/A | =DISPIMG("ID_9EEC4675E0384743873FEC17D11D36C3",1) | 1 | 70 | 70
CU_MainPOSContact | 夜巡老王超低内阻紫铜厚弹片，紫铜镀镍 处理，内阻0.3mR | N/A | =DISPIMG("ID_E8B6F25255D04B3EA6F79DD21AE0765E",1) | 1 | 1.1 | 1.1
PCB_XTRBoost_GaN_6L_ 2Oz | 驱动PCB裸板，蓝油白字，六层2Oz铜厚，TG 170生益板材，2U沉金，过孔塞树脂。 | PCB1 |  | 1 | 60 | 60
驱动物料总价 |  |  |  |  |  | 579.06
驱动元器件总数 |  |  |  | 184

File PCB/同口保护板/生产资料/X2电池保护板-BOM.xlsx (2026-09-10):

料号/规格 | 描述 | 位号 | 封装 | 数量 | 参考图片/备注 | 单价 | 总价
100nF (104) 10% 50V | 贴片电容 | C1, C2, C3, C4, C7 | 0402_C | 5 |  |  | 0
GRM188R61E106KA73D | 0603贴片MLCC电容 10uF ±20% 25V X5R | C5 | 0603_C | 1 |  | 1.06 | 1.06
33nF (333) 10% 50V | 贴片电容 | C6 | 0402_C | 1 |  | 0.07 | 0.07
白灯 0603 | 0603尺寸发光二极管 | D1, D2, D3, D5 | 0603_LED_S1 | 4 | 这个地方对于LED颜色没 有要求，你可以根据自己的喜好自行选择 | 0.02 | 0.08
B5819WS S4 | 二极管 | D4, D6, D7 | SOD-323 | 3 |  | 0.183 | 0.549
IQDH29NE2LM5CG | 英飞凌MOSFET 25V 789A 0.2mΩ @ 10V WHTFN-9(PDFN5x6源极底置)封装 | Q1, Q2, Q3, Q4, Q5, Q6, Q7, Q8 | IFX-PG-WHTFN-9-2-V | 8 |  | 26.45 | 211.6
WSD4280DN22 | 内置肖特基二极管的双P沟道MOS -15V -4.6A 45mΩ @ 4.5V DFN2x2封装 | Q9, Q13, Q17, Q21 | UDFN-6_L2.0-W2.0- P0.65-BL | 4 |  | 1.36 | 5.44
2N7002KW | 单N沟道MOSFET(场效应管) | Q10, Q14, Q18, Q22 | SC70-3 | 4 |  | 0.19 | 0.76
SS8550 Y2 | PNP三极管，SOT-323 封装 | Q11, Q15, Q19, Q23 | SC70-3 | 4 |  | 0.17 | 0.68
AON2408 | MOS(场效应管) | Q12, Q16, Q20, Q24 | PDFN-6_L2.0-W2.0- P0.65-BL-EP | 4 |  | 1.88 | 7.52
BSS84AKW | 单P沟道小信号MOSFET(场效应管) | Q25, Q26 | SC70-3 | 2 |  | 0.75 | 1.5
JER1206F1R004 | 贴片合金电流检测电阻 1206封装 4mΩ ±1% 1W | R1, R2 | 1206R | 2 |  | 0.31 | 0.62
JER1206F1R003 | 贴片合金电流检测电阻 1206封装 3mΩ ±1% 1W | R3, R4, R5, R6 | 1206R | 4 |  | 0.31 | 1.24
1206 2.5mΩ ±1% 1W | 贴片合金检流电阻 1206 2.5mΩ ±1% 1W | R7, R8 | 1206R | 2 |  | 0.31 | 0.62
510KΩ (5103) ±1% | 贴片电阻 | R9, R10, R15, R16, R23, R24, R30, R31 | 0402_R | 8 |  | 0.03 | 0.24
43Ω | 1210尺寸厚膜贴片电阻 | R11, R18, R28, R35 | 1210R | 4 |  | 0.055 | 0.22
220Ω (2200) ±1% | 贴片电阻 | R12, R19, R26, R33 | 0402_R | 4 |  | 0.03 | 0.12
2KΩ (2001) ±1% | 贴片电阻 | R21, R22, R29, R37, R40 | 0402_R | 5 |  | 0.03 | 0.15
680Ω 6800) ±1% | 贴片电阻 | R13, R20, R27,R34 | 0402_R | 4 |  | 0.03 | 0.12
1KΩ (1001) ±1% | 贴片电阻 | R14, R17, R25, R32, R36 | 0402_R | 5 |  | 0.03 | 0.15
20KΩ (2002) ±1% | 贴片电阻 | R38 | 0402_R | 1 |  | 0.03 | 0.03
91KΩ (9103) ±1% | 贴片电阻 | R39 | 0402_R | 1 |  | 0.03 | 0.03
5.6MΩ (5604) ±1% | 贴片电阻 | R41, R42, R43, R44 | 0402_R | 4 |  | 0.03 | 0.12
SDNT1005X104F3950FTF | 100KΩ (1003) ±1% B3950 NTC片式贴片热敏电阻 | R45 | 0402_R | 1 |  | 0.1 | 0.1
CM1341-FKT | 4串三元锂电池带均衡功能保护IC， SSOP16封装。 | U1 | TSSOP16-CM1341 | 1 |  | 3.5 | 3.5
Cu_TIN_L10.0_W4.0_H2.0 | 中通达SMT镀锡铜片，长10mm，宽度4mm，厚度2mm | N/A | Cu_L10.0_W4.0_H2.0 | 2 |  | 0.7 | 1.4
Cu_1AU_L7.0_W4.0_H1.0 | 中通达SMT镀金铜片，长7mm，宽度4mm，厚度1mm，镀金厚度1U | N/A | Cu_L7.0_W4.0_H2.0 | 5 |  | 0.482 | 2.41
Cu_1AU_L5.0_W2.0_H0.8 | 中通达SMT镀金铜片，长5mm，宽度2mm，厚度0.8mm，镀金厚度1U | N/A | Cu_L5.0_W2.0_H0.8 | 4 |  | 0.297 | 1.188
Cu_1AU_L2.5_W2.5_H1.9 | 中通达SMT镀金铜粒，长2.5mm，宽度2.5mm，厚度1.9mm，镀金厚度1U | N/A | Cu_L2.5_W2.5_H1.9 | 1 |  | 0.403 | 0.403
Cu_1AU_L4.0_W2.0_H2.0 | 中通达SMT镀金铜条，长4mm，宽度2mm，厚度2mm，镀金厚度1U | N/A | Cu_L4.0_W2.0_H2.0 | 3 |  | 0.288 | 0.864
Cu_1AU_L8.0_W2.0_H1.0 | 中通达SMT镀金铜条，长8mm，宽度2mm，厚度1mm，镀金厚度1U | N/A | Cu_L8.0_W2.0_H1.0 | 1 |  | 0.546 | 0.546
Cu_1AU_L2.0_W2.0_H1.5 | 中通达SMT镀金铜条，长2mm，宽度2mm，厚度1.5mm，镀金厚度1U | N/A | Cu_L2.0_W2.0_H1.5 | 5 |  | 0.236 | 1.18
保护板物料总价 |  |  |  |  |  | 244.51
保护板元器件总数 |  |  |  | 107

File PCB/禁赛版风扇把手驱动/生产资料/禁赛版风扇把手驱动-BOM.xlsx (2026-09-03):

料号 | 描述 | 位号 | 封装 | 数量 | 参考图片/备注 | 单价 | 总价
100nF (104) 10% 50V | 贴片电容 | C1, C3, C18 | 0402_C | 3 |  | 0.06 | 0.18
4.7uF (475) 20% 10V | 贴片电容 | C2 | 0402_C | 1 |  | 0.1 | 0.1
GRM31CR61E476ME44L | 1206尺寸村田MLCC 25V 47uF X5R ±20% | C4, C5 | 1206C | 2 |  | 4.3 | 8.6
22uF (226) 20% 25V | 贴片电容 | C6 | 0805_C | 1 |  | 1.58 | 1.58
47nF (473) 10% 50V | 贴片电容 | C7 | 0402_C | 1 |  | 0.06 | 0.06
56pF (560) 5% 50V | 贴片电容 | C8 | 0402_C | 1 |  | 0.1 | 0.1
10uF (106) 20% 10V | 贴片电容 | C9, C10, C13 | 0402_C | 3 |  | 0.48 | 1.44
C2012X5R1A476MTJ00E | 贴片MLCC电容，X5R 47uF ±20% 10V | C11, C12 | 0805_C | 2 |  | 1.41 | 2.82
1.0uF (105) 10% 25V | 贴片电容 | C14, C15 | 0402_C | 2 |  |  | 0
GRM188R61E106KA73D | 村田贴片MLCC电容 25V 10uF±20% X5R 0603封装 | C16, C17, C19, C20, C21 | 0603_C | 5 |  | 0.4 | 2
2.2nF (222) 10% 50V | 贴片电容 | C23 | 0402_C | 1 |  |  | 0
CMS8S-JTAG-TP-1.27mm | 面向CMS8S6990NA单片机的调试贴片触点，并不是元器件实物 | J1 | CMS8S-JTAG-TP-2x2-P1.27 | 0 |  | 0 | 0
XAL1060-222MEC | 线艺一体成型模压电感，9.8mΩ DCR 25A饱和 电流 4.7uH±20%电感量 10*11*6mm尺寸 | L1 | XAL1060-472ME-Lifted | 1 | 这个地方如果能买到XGL1060-222MEC的话建议用，可以提升1%满载效率。此外，如果需要考虑双锂模式，则电感需要更换为4.7uH的XGL1060-472否则芯片会过载烧毁！ | 42 | 42
BSZ024N04LS6ATMA1 | 英飞凌OptiMOS 6 40V N沟道功率MOS 2.8mΩ@4.5V S3O8封装 | Q1 | DFN-8_L3.0-W3.0-P0.65-BL | 1 |  | 16.13 | 16.13
XPX80P02RX | PDFN3x3 30V 80A P沟道MOSFET | Q2, Q3 | DFN-8_L3.0-W3.0-P0.65-BL | 2 | 贴牌版本AP80P02DF，可以在淘宝买到。如果买不到就用WSD20L70DN33替代，损耗略高。 | 0.75 | 1.5
XPX70P03RX | -30V -70A 6.5mR P沟道增强型MOSFET | Q4 | DFN-8_L3.0-W3.0-P0.65-BL | 1 | 贴牌版本AP70P03DF，可以在淘宝买到。如果买不到可以用30V 至少8mΩ Rdson以内的P管替代。 | 0.42 | 0.42
2N7002KW | 单N沟道MOSFET(场效应管) | Q5, Q6 | SC70-3 | 2 |  | 0.19 | 0.38
510KΩ (5103) ±1% | 贴片电阻 | R1 | 0402_R | 1 |  | 0.03 | 0.03
RT0402BRD0720KL | 0402贴片薄膜高精密电阻 20KΩ ±0.1% 62.5mW 25PPM | R2 | 0402_R | 1 |  | 0.58 | 0.58
59KΩ (5902) ±1% | 贴片电阻 | R3 | 0402_R | 1 |  | 0.03 | 0.03
PTFR0402B10K0N9 | 0402贴片薄膜高精密电阻 10KΩ ±0.1% 62.5mW 25PPM | R4 | 0402_R | 1 |  | 0.81 | 0.81
10KΩ (1002) ±1% | 贴片电阻 | R5, R6, R7, R13, R14, R19 | 0402_R | 6 |  | 0.03 | 0.18
51KΩ (5102) ±1% | 贴片电阻 | R8 | 0402_R | 1 |  | 0.03 | 0.03
220KΩ (2203) ±1% | 贴片电阻 | R9 | 0402_R | 1 |  | 0.03 | 0.03
22KΩ (2202) ±1% | 贴片电阻 | R10 | 0402_R | 1 |  | 0.03 | 0.03
2.2Ω (2R20) ±1% | 贴片电阻 | R11 | 0603_R | 1 |  | 0.03 | 0.03
47KΩ (4702) ±1% | 贴片电阻 | R12 | 0402_R | 1 |  | 0.03 | 0.03
0Ω (0R0) ±1% | 贴片电阻 | R15 | 0402_R | 1 |  | 0.03 | 0.03
10Ω (10R0) ±1% | 贴片电阻 | R16 | 0402_R | 1 |  | 0.03 | 0.03
AR02BTD4703 | 0402 贴片薄膜高精密低温飘电阻 470KΩ±0.1% 25PPM | R17 | 0402_R | 1 |  | 0.2 | 0.2
ERA2AEB104X | 松下 0402精密低温飘贴片电阻 100KΩ±0.1% 62.5mW | R18 | 0402_R | 1 |  | 0.43 | 0.43
RC0402DR-07330KL | 0402厚膜较高精度贴片电阻 330KΩ±0.5% 62.5mW | R20 | 0402_R | 1 |  | 0.03 | 0.03
FNTC0402X104D4250DB | 0402尺寸贴片式NTC热敏电阻 B25-85℃=4310±0.5% R25=100KΩ±0.5% | R21 | 0402_R | 1 |  | 0.38 | 0.38
TBD | 0402贴片电阻，阻值根据配置来 | R22 | 0402_R | 1 | 这个电阻根据需要的固件模式配置选 择阻值，详情请查看固件readme和原理图PDF！ | 0.03 | 0.03
TPS61287RZPR | Synchronous Boost Converter with Stackable Multi-Phase Function | U1 | RZP0014A- TPS61287 | 1 |  | 21 | 21
CMS8S6990NAQN20 | 增强型闪存1T 8051单片机，16KB Flash 256+1K XRAM | U2 | QFN3*3_20L | 1 |  | 1.13 | 1.13
LMV321IDCKR | CMOS超小型运算放大器，SC70-5 | U3 | SC70-5 | 1 | 不建议用国产替代，国产料 存在Vol漂移问题，会变得不幸 | 1.25 | 1.25
ME6209A30M3G | 低压差线性稳压(LDO) | VR1 | SOT-23-3L | 1 |  | 0.42 | 0.42
Cu_1AU_L8.0_W2.0_H1.0 | 中通达SMT镀金铜条，长8mm，宽度2mm，厚度1mm，镀金厚度1U | N/A | Cu_L8.0_W2.0_H1.0 | 2 | 可以在淘宝买到，需要垫在电感焊盘底下，用高温锡贴片，贴完再焊电感。 | 0.546 | 1.092
CU_MainPOSContact | 东东海老款迷你薄弹片，可以找老板购买。需要用大剪刀裁剪后焊接到驱动背部大触点（参考备注图片的焊接方式）。 | N/A |  | 1 |  | 1.1 | 1.1
驱动物料总价 |  |  |  |  |  | 106.212
驱动元器件总数 |  |  |  | 58

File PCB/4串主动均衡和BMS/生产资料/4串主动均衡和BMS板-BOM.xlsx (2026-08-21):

料号/规格 | 描述 | 位号 | 封装 | 数量 | 参考图片/备注 | 单价 | 总价
100nF (104) 10% 50V | 贴片电容 | C1, C2, C5, C8, C13, C14, C15, C16, C22, C23, C24, C25, C27,C28 | 0402_C | 14 |  | 0.07 | 0.98
GRM21BR61A476ME15L | 贴片MLCC电容，47uF (476) 20% 10V | C3, C4, C6, C7, C9, C10, C11, C12 | 0805_C | 8 |  | 2.7 | 21.6
1.0uF (105) 10% 25V | 贴片电容 | C18, C19 | 0402_C | 2 |  | 0.07 | 0.14
GRM188R61E106KA73D | 0603贴片MLCC电容 10uF ±20% 25V X5R | C17, C20 | 0603_C | 2 |  | 1.06 | 2.12
10uF (106) 20% 10V | 贴片电容 | C21 | 0402_C | 1 |  | 0.1 | 0.1
10nF (103) 10% 50V | 贴片电容 | C26 | 0402_C | 1 |  | 0.07 | 0.07
B5819WS S4 | 二极管 | D1 | SOD-323 | 1 |  | 0.183 | 0.183
1N4148WS T4 | 二极管 | D2, D3, D4, D5 | SOD-323 | 4 |  | 0.0655 | 0.262
ZSRG-1608C-06-Z4 | 发光二极管 红绿无级双色 | D6 | 0603_LED_S1 | 1 |  | 0.5 | 0.5
CMS8S-JTAG-TP-1.27mm | 面向CMS8S6990NA单片机的调试贴片触点， 并不是元器件实物 | J1 | CMS8S-JTAG-TP-1.27 | 1 | 这个元器件不需要贴片 | 0 | 0
AFC01-S08FCA-00 | 翻盖式下接FPC/FFC连接器 P数:8P 间距:0.5mm | P1 | FPC0.5 2H-WS-8P | 1 |  | 0.73 | 0.73
XPX30K03RX | 双P沟道MOSFET, DFN3x3 -20V -30A 12mΩ | Q1, Q4, Q7, Q10 | EDFN3x3 | 4 |  | 0.45 | 1.8
2N7002KW | 单N沟道MOSFET(场效应管) | Q2, Q5, Q8, Q11, Q13 | SC70-3 | 5 |  | 0.19 | 0.95
XPX4896RX | 双N沟道MOSFET, DFN3x3 40V 45A 7.2mΩ | Q3, Q6, Q9, Q12 | EDFN3x3 | 4 |  | 0.49 | 1.96
510KΩ (5103) ±1% | 贴片电阻 | R1, R2, R5, R6, R9, R10, R11, R12 | 0402_R | 8 |  | 0.03 | 0.24
10KΩ (1002) ±1% | 贴片电阻 | R3, R4, R7, R8, R13, R14, R15, R16, R27, R34, R35, R36, R37, R40 | 0402_R | 14 |  | 0.03 | 0.42
10Ω (10R0) ±1% | 贴片电阻 | R17 | 0402_R | 1 |  | 0.03 | 0.03
110KΩ (1103) ±1% | 贴片电阻 | R18 | 0402_R | 1 |  | 0.03 | 0.03
12KΩ (1202) ±1% | 贴片电阻 | R19 | 0402_R | 1 |  | 0.03 | 0.03
0Ω (0R0) ±1% | 贴片电阻 | R20, R21 | 0402_R | 2 |  | 0.03 | 0.06
51Ω (51R0) ±1% | 贴片电阻 | R22 | 0603_R | 1 |  | 0.03 | 0.03
1KΩ (1001) ±1% | 贴片电阻 | R23, R24, R25, R26, R39, R41, R42 | 0402_R | 7 |  | 0.03 | 0.21
100Ω (1000) ±1% | 贴片电阻 | R28 | 0402_R | 1 |  | 0.03 | 0.03
100KΩ (1003) ±1% | 贴片电阻 | R29, R30 | 0402_R | 2 |  | 0.03 | 0.06
1MΩ (1004) ±1% | 贴片电阻 | R31 | 0402_R | 1 |  | 0.03 | 0.03
5.1KΩ (5101) ±1% | 贴片电阻 | R32, R33, R43 | 0402_R | 3 |  | 0.03 | 0.09
2.43KΩ (2431) ±1% | 贴片电阻 | R38 | 0402_R | 1 |  | 0.03 | 0.03
ER14.5 | ER14.5骨架的定制均衡专用的多绕组变压器，PC40磁芯材质（详细制造信息请参考项目生产资料文件内的变压器图纸） | TF1 | ER14.5 SMT6+6 | 1 |  | 24 | 24
MPQ2013AGQ-AEC1 | MPS 40V LDO with Enable pin QFN3x3 package | U1 | MPQ2013A-QFN8 | 1 |  | 5.33 | 5.33
UCC27526DSDR | 双路18V 5A峰值电流低侧栅极驱动器， WSON-8封装尺寸 | U2 | DSD0008D | 1 | 这玩意淘宝容易买到假的 丝印一洗就掉虽然能用但是不稳定。建议去立创买。 | 15.62 | 15.62
SH367303 | 3至5串锂离子电池BMS模拟前端， 具备充放电控制/电压采集和I2C接口 | U3 | QFN28-5x5 | 1 |  | 4.59 | 4.59
CMS8S6990NAQN20 | 增强型闪存1T 8051单片机，16KB Flash 256+1K XRAM | U4 | QFN40P300X300X800_HS-21N | 1 |  | 1.13 | 1.13
TLP291(GB-TP,SE | DC输入光电耦合隔离器，线性输入输出， 隔离电压(rms):3750V SOP-4小型封装 | U6, U7 | TSOP-4_P1.27 | 2 |  | 0.72 | 1.44
均衡和BMS板物料总价 |  |  |  |  |  | 84.795
均衡和BMS板元器件总数 |  |  |  | 99

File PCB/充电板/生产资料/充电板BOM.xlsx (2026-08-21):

料号/规格 | 描述 | 位号 | 封装 | 数量 | 参考图片/备注 | 单价 | 总价
100nF (104) 10% 50V | 贴片电容 | C1, C16 | 0402_C | 2 |  | 0.07 | 0.14
680nF (684) 20% 16V | 贴片电容 | C2 | 0402_C | 1 |  | 0.08 | 0.08
C3216X5R1V226M160AC | 1206尺寸TDK MLCC 35V 22uF | C3, C5, C6, C10, C11, C13, C14, C22, C23, C30 | 1206C | 10 |  | 3.49 | 34.9
F25Z35V470M6x18 | 直插艾华固态电容，耐压35V容量470uF，尺寸D6.3x18 | C4, C24 | CAP_D6.3_L18.0_DIP_P2.54 | 2 |  | 1 | 2
220nF (224) 10% 16V | 贴片电容 | C7, C9 | 0402_C | 2 |  | 0.08 | 0.16
470NF (474) 10% 50V | 贴片电容 | C8 | 0402_C | 1 |  | 0.08 | 0.08
PA25V470M6x12 | 直插固态电容，耐压25V容量470uF，尺寸D6.3x12 | C12 | CAP_D6.3_L12.0_DIP_P2.54 | 1 |  | 1.4 | 1.4
2.2uF (225) 10% 10V | 贴片电容 | C15 | 0402_C | 1 |  | 0.08 | 0.08
10uF (106) 20% 10V | 贴片电容 | C17, C18 | 0402_C | 2 |  | 0.08 | 0.16
100nF (104) 10% 16V | 贴片电容 | C19, C20 | 0402_C | 2 |  | 0.08 | 0.16
22nF (223) 10% 50V | 贴片电容 | C21 | 0402_C | 1 |  | 0.08 | 0.08
10pF (100) 5% 50V | 贴片电容 | C25 | 0402_C | 1 |  | 0.08 | 0.08
10pF ±5% 50V | 贴片电容 | C26, C27 | 0402_C | 2 |  | 0.08 | 0.16
B5819WS S4 | 二极管 | D1, D2, D3, D4, D12, D13 | SOD-323 | 6 |  | 0.183 | 1.098
NCD1615RG1 | 国星光电 0606(1615) 尺寸 双色LED 红色/翠绿 | D5 | LED-SMD_4P-L1.6-W1.5-TL-1 | 1 |  | 0.4 | 0.4
0603 LED | 0603尺寸发光二极管 | D6, D7, D8, D9 | 0603_LED_S1 | 4 | 这里的LED颜色没有要求，看自己喜好想怎么贴都可以 | 0.02 | 0.08
SMF28A | SOD123封装单向TVS二极管 28V反向截止电压 峰值脉冲电流4.4A@10/1000us | D10, D11 | SOD-123 | 2 |  | 0.94 | 1.88
BSMD2410C-2200T | 2410尺寸 20A 250V 一次性 慢速熔断陶瓷保险丝 | F1 | FUSE_L2.4_W1.0 | 1 |  | 0.67 | 0.67
EBMS100505A050 | 贴片磁珠 200mA 5R±25% 100MHz | FB1 | 0402_L | 1 |  | 0.03 | 0.03
TYPE-C-31-M-12 | 16Pin TypeC卧式贴片座子，韩国韩荣 | J1 | USB-C-SMD_KH-TYPE-C-16P | 1 |  | 1.05 | 1.05
FEXL0430A-1R0M | 长江微电一体成型电感，1.0uH±20% 14.6mΩ DCR 9.8A饱和电流 | L1 | IND_L4.10_W4.10_H3.0_2P | 1 |  | 4.32 | 4.32
CSBX1275-100M | 科达嘉电子扁线一体成型电感，13.8*12.8*7.3mm， 10uH 21.0A 8.77mΩ | L2 | CSBX1275 | 1 | 科达嘉不对C端零售。如果买不到，用EPC1265-100M-TK代替 | 5 | 5
0.5-8P CTSJ-H2.0 119 | FFC/FPC连接器 间距：0.5mm，P数：8P，卧贴， 抽屉式上接，厚度H2.0mm | P1 | FPC0.5 2H-WS-8P | 1 |  | 0.63 | 0.63
IAUCN04S7L028ATMA1 | 40V, N-Ch, 2.80mΩ max, Automotive MOSFET, SSO8(5x6), OptiMOS 7 | Q1, Q2, Q3, Q4 | IFX_SuperSO8_L6.0_W5.0 | 4 |  | 8.48 | 33.92
XPX4896RX | 双N沟道MOSFET, DFN3x3 40V 45A 7.2mΩ | Q5 | EDFN3x3 | 1 |  | 0.49 | 0.49
IAUZN04S7L012ATMA1 | OptiMOS 7 40V Logic Level Power MOSFET, 1.55mΩ @ 4.5V LL,S3O8(PDFN3333) Package | Q6 | DFN-8_L3.0-W3.0-P0.65-BL | 1 |  | 20 | 20
BSS84AKW | 单P沟道小信号MOSFET(场效应管) | Q8 | SC70-3 | 1 |  | 0.75 | 0.75
2N7002KW | 单N沟道MOSFET(场效应管) | Q13 | SC70-3 | 1 |  | 0.19 | 0.19
0.5Ω (R050) ±1% | 贴片电阻 | R1, R2, R6, R7 | 0603_R | 4 |  | 0.04 | 0.16
2.5mΩ (R0025) ±1% | 1206贴片合金检流电阻 2.5mΩ | R3 | 1206_R | 1 |  | 0.3 | 0.3
DNP | 0402贴片电阻预留位置(暂时空置不贴， 根据充电板状况选取阻值) | R4 | 0402_R | 1 |  | 0 | 0
51Ω (51R0) ±1% | 贴片电阻 | R5 | 0402_R | 1 |  | 0.03 | 0.03
10Ω (10R0) ±1% | 贴片电阻 | R8 | 0402_R | 1 |  | 0.03 | 0.03
27KΩ (2702) ±1% | 贴片电阻 | R9 | 0402_R | 1 |  | 0.03 | 0.03
9.1KΩ (9101) ±1% | 贴片电阻 | R10, R11 | 0402_R | 2 |  | 0.03 | 0.06
10KΩ (1002) ±1% | 贴片电阻 | R12, R16, R17, R25, R33 | 0402_R | 5 |  | 0.03 | 0.15
20KΩ (2002) ±1% | 贴片电阻 | R13, R14, R19, R32 | 0402_R | 4 |  | 0.03 | 0.12
47KΩ (4702) ±1% | 贴片电阻 | R15, R27 | 0402_R | 2 |  | 0.03 | 0.06
FRP2512F68R0TS | 高功率2512封装厚膜电阻 68Ω ±1% 2W (需要叠放焊接2PCS) | R18 | 2512 | 2 |  | 0.362 | 0.724
1KΩ (1001) ±1% | 贴片电阻 | R20 | 0402_R | 1 |  | 0.03 | 0.03
750Ω (7500) ±1% | 贴片电阻 | R21, R22, R23 | 0402_R | 3 |  | 0.03 | 0.09
160KΩ (1603) ±1% | 贴片电阻 | R24 | 0402_R | 1 |  | 0.03 | 0.03
22KΩ (2202) ±1% | 贴片电阻 | R26 | 0402_R | 1 |  | 0.03 | 0.03
8.45KΩ (8451) ±1% | 贴片电阻 | R28 | 0402_R | 1 |  | 0.03 | 0.03
5.1KΩ (5101) ±1% | 贴片电阻 | R29 | 0603_R | 1 |  | 0.03 | 0.03
5mΩ (R005) ±1% | 贴片合金检流电阻 | R30 | 1206_R | 1 |  | 0.30 | 0.3
4mΩ (R004) ±1% | 贴片合金检流电阻 | R31 | 1206_R | 1 |  | 0.30 | 0.3
1Ω (1R50) ±1% | 贴片电阻 | R34 | 0402_R | 1 |  | 0.03 | 0.03
1.5Ω (1R50) ±1% | 贴片电阻 | R36 | 0402_R | 1 |  | 0.03 | 0.03
4x4轻触 3.0mm高度 | 4x4mm锅仔片结构金属轻触开关 H3.0mm | S1 | SW-SMD_4P-L5.2-W5.2- P3.70-LS6.4 | 1 |  | 0.31 | 0.31
IP2366_BZ | 支持多种快充协议，最高140W功率的充放电管理SoC | U1 | QFN40-IP2366 | 1 |  | 7 | 7
LMV331IDCKR | 单路通用低电压比较器，2.7-5.5V，SC70-5封装 | U2 | SC70-5 | 1 | 这个地方建议用TI 原装进口，国产会变得不幸 | 2.5 | 2.5
TLP291(GB-TP,SE | DC输入 光电耦合隔离器 隔离电压(rms):3750V SOP-4封装 | U3 | TSOP-4_P1.27 | 1 |  | 0.72 | 0.72
充电板物料总价 |  |  |  |  |  | 123.082
充电板元器件总数 |  |  |  | 95

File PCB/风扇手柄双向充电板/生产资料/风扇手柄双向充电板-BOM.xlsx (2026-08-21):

料号/规格 | 描述 | 位号 | 封装 | 数量 | 参考图片/备注 | 单价 | 总价
GRM21BR61A476ME15L | 贴片MLCC电容，47uF (476) 20% 10V | C1, C6, C7, C8 | 0805_C | 4 |  | 2.7 | 10.8
10uF (106) 20% 10V | 贴片电容 | C2, C4, C9 | 0402_C | 3 |  | 0.1 | 0.3
2.2nF (222) 10% 50V | 贴片电容 | C3 | 0402_C | 1 |  | 0.08 | 0.08
2.2uF (225) 20% 25V | 贴片电容 | C5 | 0402_C | 1 |  | 0.08 | 0.08
CESDB5V0D3 | 5V额定工作电压，6.2V击穿电压 双向TVS管，SOD-323 | D1 | SOD-323 | 1 | 这个管子必须是双向 TVS，不能用单向的代替！否则电池一装反立刻起火冒烟！ | 0.16 | 0.16
绿灯 0603 | 发光二极管 | D2 | 0603_LED_S1 | 1 | 充放电指示灯， 可以用自己喜欢的颜色。 | 0.02 | 0.02
黄灯 0603 | 发光二极管 | D3 | 0603_LED_S1 | 1 |  | 0.02 | 0.02
CESD5V0D3 | 5V额定工作电压，6.2V击穿电压 单向TVS管，SOD-323 | D4 | SOD-323 | 1 |  | 0.16 | 0.16
TYPEC 6P L5.1 | TYPEC连接器 6P 2脚插板SMT 5.1长度 | J1 | TYPEC 6P两脚插板SMT L5.1 | 1 |  | 0.1 | 0.1
XAL5030-222MEC | 线艺XAL5030一体成型电感 9.2A饱和电流， 13.2mΩ DCR 2.2uH±20% | L1 | FEXL0520A-***M | 1 |  | 5 | 5
XPX80P02RX | -20V -80A 4mR内阻 P沟道MOSFET | Q1 | DFN-8_L3.0-W3.0- P0.65-BL | 1 | 贴牌版AP80P02DF，可以在淘宝买到。如果买不到就WSD20L70DN33替代，损耗略高。 | 0.75 | 0.75
2N7002KW | 单N沟道MOSFET(场效应管) | Q2 | SC70-3 | 1 |  | 0.19 | 0.19
510KΩ (5103) ±1% | 贴片电阻 | R1, R2 | 0402_R | 2 |  | 0.03 | 0.06
4.7Ω (4R70) ±1% | 贴片电阻 | R3 | 0402_R | 1 |  | 0.03 | 0.03
2.2Ω (2R20) ±1% | 贴片电阻 | R4 | 0402_R | 1 |  | 0.03 | 0.03
1Ω (1R00) ±1% | 贴片电阻 | R5 | 0805_R | 1 |  | 0.1 | 0.1
1KΩ (1001) ±1% | 贴片电阻 | R6 | 0402_R | 1 |  | 0.03 | 0.03
510Ω (5100) ±1% | 贴片电阻 | R7, R8 | 0402_R | 2 |  | 0.03 | 0.06
75KΩ (7502) ±1% | 贴片电阻 | R9 | 0402_R | 1 |  | 0.03 | 0.03
CMFD104J3900HANT | 风华0402贴片NTC热敏电阻 B3900 100K ±5% | R10 | 0402_R | 1 |  | 0.03 | 0.03
10KΩ (1002) ±1% | 贴片电阻 | R11 | 0402_R | 1 |  | 0.03 | 0.03
IP5326_BZ | 集成TYPC-C协议的2.4A 5V充放电移动电源 SoC QFN3*3封装 | U1 | QFN33-16L-IP5326 | 1 |  | 1 | 1
Cu_1AU_D9.0_H1.0 | 中通达SMT镀金圆形铜片，直径9.0mm，厚度1.0mm，镀金厚度1U | N/A | Cu_1AU_D9.0_H1.0 | 2 |  | 0.78 | 1.56
风扇双向充电板物料总价 |  |  |  |  |  | 20.62
风扇双向充电板元器件总数 |  |  |  | 31

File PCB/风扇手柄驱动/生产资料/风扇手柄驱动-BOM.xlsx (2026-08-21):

料号/规格 | 描述 | 位号 | 封装 | 数量 | 参考图片/备注 | 单价 | 总价
220nF (224) 10% 16V | 贴片电容 | C1 | 0402_C | 1 |  | 0.08 | 0.08
10uF (106) 20% 10V | 贴片电容 | C2, C6, C12, C18 | 0402_C | 4 |  | 0.08 | 0.32
GRM21BR61A476ME15L | 贴片MLCC电容，47uF (476) 20% 10V | C3, C4 | 0805_C | 2 |  | 2.7 | 5.4
22nF (223) 10% 50V | 贴片电容 | C5 | 0402_C | 1 |  | 0.08 | 0.08
6.8nF (682) 10% 50V | 贴片电容 | C7 | 0402_C | 1 | MP3429的补偿电容，为了 保证最佳稳定性，至少要使用X7R电容。最好用NP0/C0G。 | 0.08 | 0.08
22uF (226) 20% 25V | 贴片电容 | C8, C9 | 0805_C | 2 |  | 1.53 | 3.06
GRM188R61E106KA73D | 0603贴片MLCC电容 10uF ±20% 25V X5R | C10, C11, C16, C19 | 0603_C | 4 |  | 1.06 | 4.24
100nF (104) 10% 16V | 贴片电容 | C13 | 0402_C | 1 |  | 0.08 | 0.08
1.0uF (105) 10% 25V | 贴片电容 | C14, C15 | 0402_C | 2 |  | 0.08 | 0.16
1nF (102) 10% 50V | 贴片电容 | C17 | 0402_C | 1 |  | 0.08 | 0.08
CESD12VD3 | 12V TVS二极管 | D1 | SOD-323 | 1 |  | 0.2 | 0.2
XGL6060-102MEC | 线艺超低损耗系列一体成型电感 1.0uH±20% 2.5mΩ DCR 23A饱和电流 6.5*6.7*6.2mm | L1 | XAL6030-xxxME | 1 | 该料号适用于30W持续输出 适配30W暴力风扇。如果是小功率风扇（如18W以内）可以用XAL6030-102MEB替代。 | 24 | 24
XPX80P02RX | -20V -80A 4mR内阻 P沟道MOSFET | Q1, Q2 | DFN-8_L3.0-W3.0- P0.65-BL | 2 | 贴牌版本AP80P02DF，可以在淘宝买到。如果买不到就用WSD20L70DN33替代，损耗略高。 | 0.75 | 1.5
XPX70P03RX | -30V -70A 6.5mR P沟道增强型MOSFET | Q3 | DFN-8_L3.0-W3.0- P0.65-BL | 1 |  | 0.42 | 0.42
2N7002KW | 单N沟道MOSFET(场效应管) | Q4, Q5 | SC70-3 | 2 |  | 0.19 | 0.38
10KΩ (1002) ±1% | 贴片电阻 | R1, R4, R7, R10, R13, R16 | 0402_R | 6 |  | 0.03 | 0.18
21.5KΩ (2152) ±1% | 贴片电阻 | R2 | 0402_R | 1 |  | 0.03 | 0.03
10Ω (10R0) ±1% | 贴片电阻 | R3 | 0402_R | 1 |  | 0.03 | 0.03
510KΩ (5103) ±1% | 贴片电阻 | R5 | 0402_R | 1 |  | 0.03 | 0.03
59KΩ (5902) ±1% | 贴片电阻 | R6 | 0402_R | 1 |  | 0.03 | 0.03
22KΩ (2202) ±1% | 贴片电阻 | R8 | 0402_R | 1 |  | 0.03 | 0.03
220KΩ (2203) ±1% | 贴片电阻 | R9 | 0402_R | 1 |  | 0.03 | 0.03
51KΩ (5102) ±1% | 贴片电阻 | R11 | 0402_R | 1 |  | 0.03 | 0.03
47KΩ (4702) ±1% | 贴片电阻 | R12 | 0402_R | 1 |  | 0.03 | 0.03
470KΩ (4703) ±1% | 贴片电阻 | R14 | 0402_R | 1 |  | 0.03 | 0.03
100KΩ (1003) ±1% | 贴片电阻 | R15 | 0402_R | 1 |  | 0.03 | 0.03
0Ω (0R0) ±1% | 贴片电阻 | R17 | 0402_R | 1 |  | 0.03 | 0.03
4.7Ω (4R70) ±1% | 贴片电阻 | R18 | 0402_R | 1 |  | 0.03 | 0.03
MP3429GL-Z | 16VOUT, 21A Peak Current Fully Integrated Synchronous Boost Converter | U1 | QFN-MLP3*4-13L | 1 | 可以用MP3431GL-Z替代， 外围不需要改动可以直接使用。哪个好买就买哪个。 | 4.3 | 4.3
CMS8S6990NAQN20 | 增强型闪存1T 8051单片机，16KB Flash 256+1K XRAM | U2 | QFN20_L3.0_W3.0 | 1 |  | 1.13 | 1.13
LMV321IDCKR | CMOS超小型运算放大器，SC70-5 | U3 | SC70-5 | 1 | 不建议用国产替代，国产料 存在Vol漂移问题，会变得不幸 | 1.25 | 1.25
ME6209A30M3G | 低压差线性稳压(LDO)，输入耐压18V 输出3V 300mA最大电流 SOT23-3封装 | VR1 | SOT-23-3L | 1 |  | 0.38 | 0.38
Cu_1AU_L2.0_W2.0_H1.5 | 中通达SMT镀金铜条，长2mm，宽度2mm，厚度1.5mm，镀金厚度1U | N/A | Cu_L2.0_W2.0_H1.5 | 1 |  | 0.236 | 0.236
风扇驱动板物料总价 |  |  |  |  |  | 47.516
风扇驱动板元器件总数 |  |  |  | 44

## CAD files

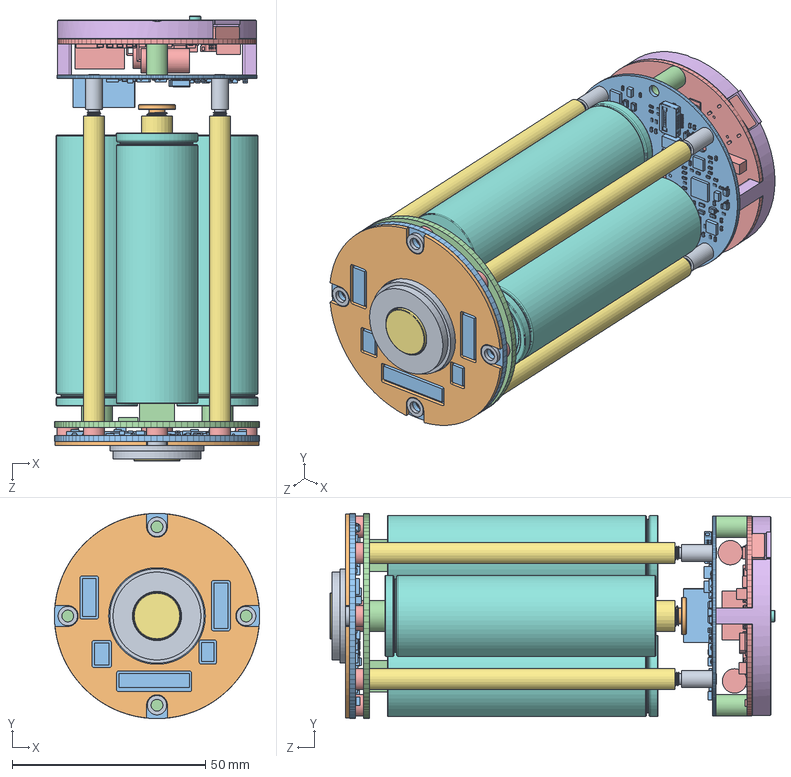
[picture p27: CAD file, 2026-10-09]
机械/电池架3D制造文件/电池架装配视图.SLDASM
53.0 x 53.0 x 115.0 mm
电池架正极垫圈
电池架保护垫圈
同口保护板
下端电池接触板
保护板SMT铜柱
正极铜接触点
导电铜柱
21700电池 x 4
均衡板支撑柱
中心铜柱不锈钢螺丝
均衡控制板
均衡和充电铜柱
充电板PCB
充电板顶部散热铜柱
正极中通达铜镀金
正面电池BMS按钮
电池架底座正极限位垫圈

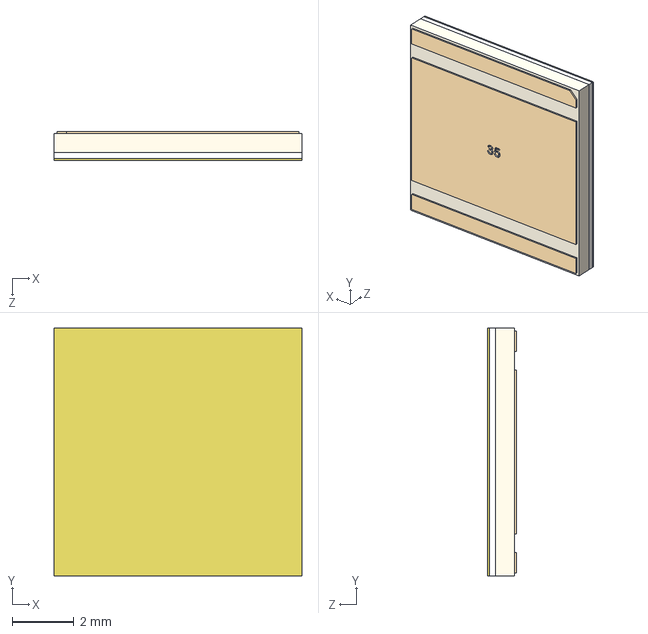
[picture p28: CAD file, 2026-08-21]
机械/光学相关文件/FL8032P.STEP
8.00 x 8.00 x 0.925 mm

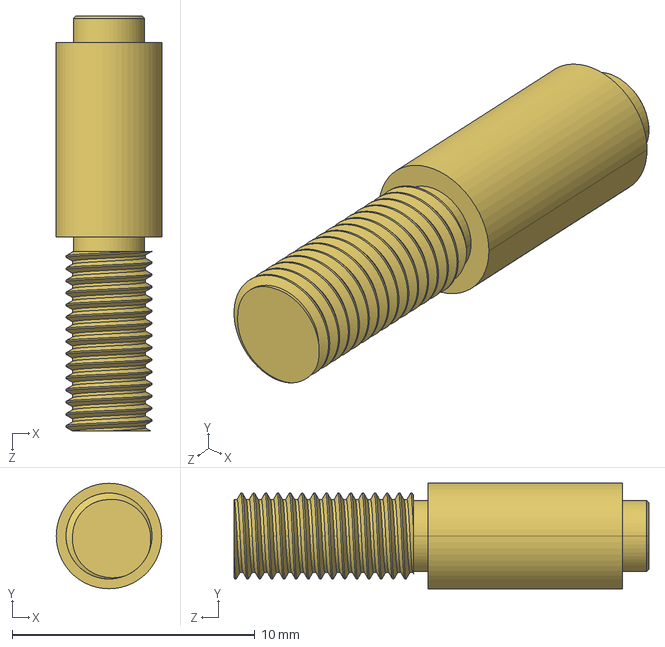
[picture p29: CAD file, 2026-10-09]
机械/电池架3D制造文件/3D图/均衡板支撑柱.STEP
4.35 x 4.35 x 17.1 mm

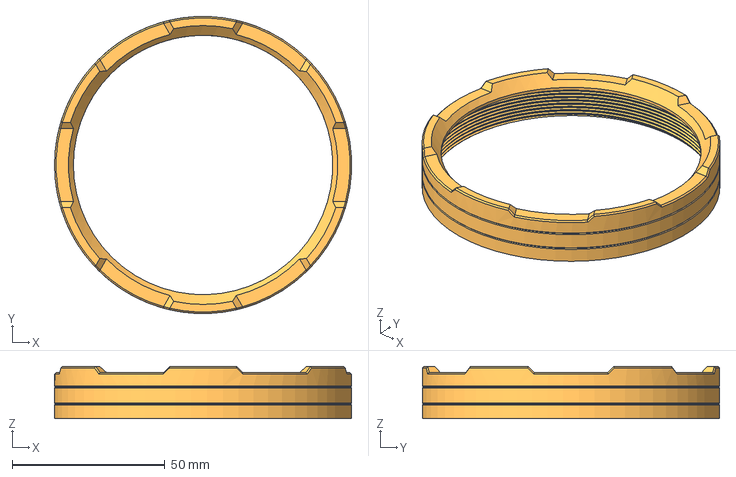
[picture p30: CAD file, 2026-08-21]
机械/筒身3D制造文件/STEP/玻璃压环.stp
97.3 x 97.4 x 17.1 mm

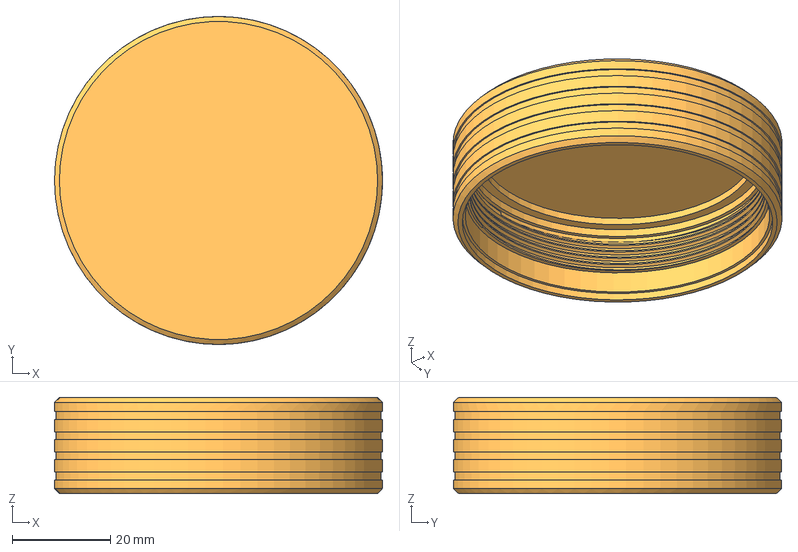
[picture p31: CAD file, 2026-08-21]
机械/筒身3D制造文件/电池管保护前盖-304不锈钢.stp
66.8 x 66.8 x 19.6 mm

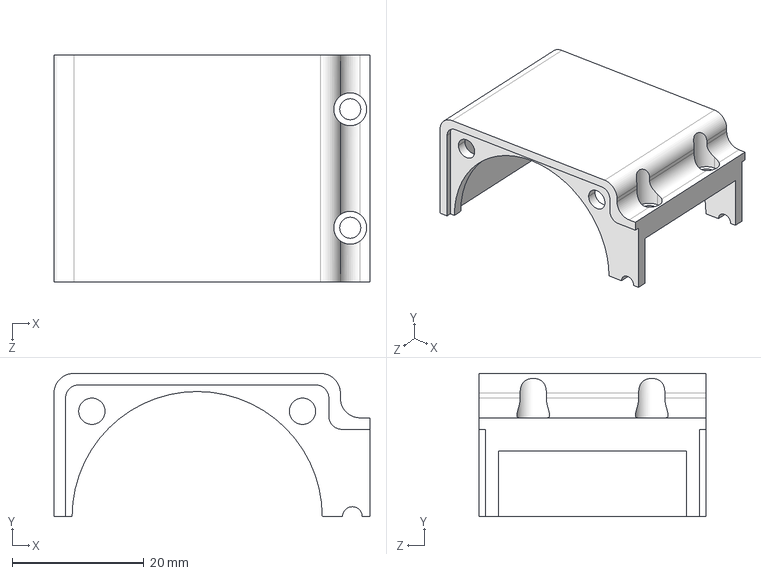
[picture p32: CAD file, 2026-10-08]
机械/风扇把手相关3D制造文件/3D制造文件/40风扇尼龙.STEP
48.0 x 21.8 x 34.5 mm

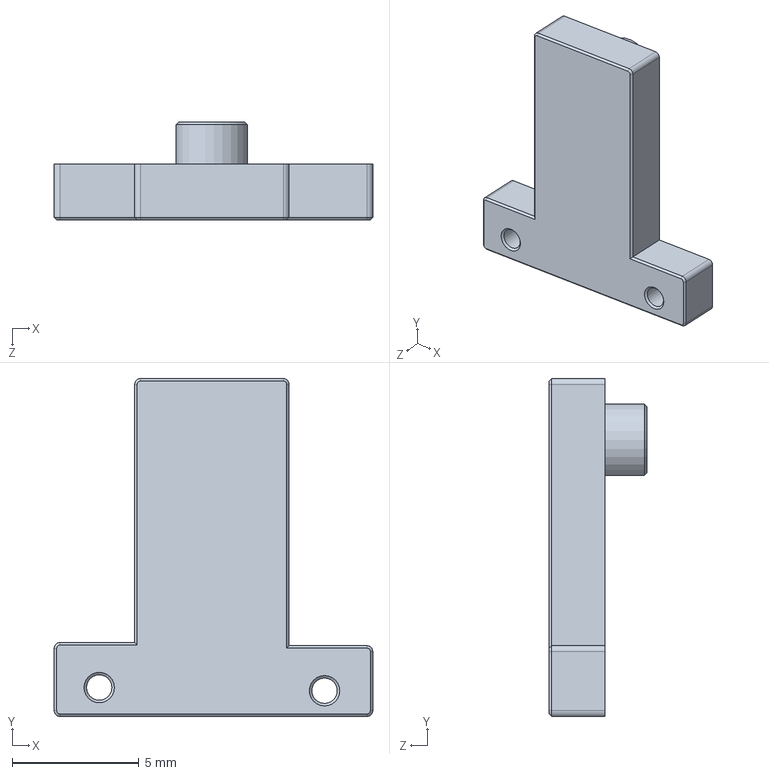
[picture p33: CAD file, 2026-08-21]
机械/驱动相关3D制造文件/驱动电流传导块.SLDPRT
12.6 x 13.3 x 3.85 mm

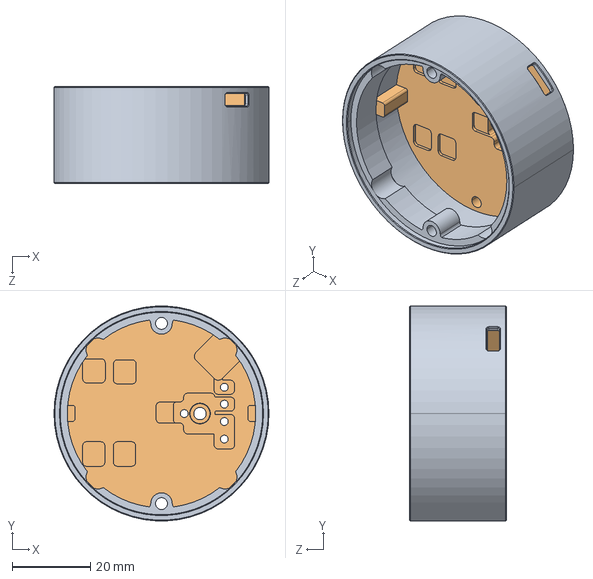
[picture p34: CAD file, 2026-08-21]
机械/电池架3D制造文件/2D图/配合图纸.STEP
55.0 x 54.9 x 24.8 mm
顶部导热块
充电板顶部散热铜柱

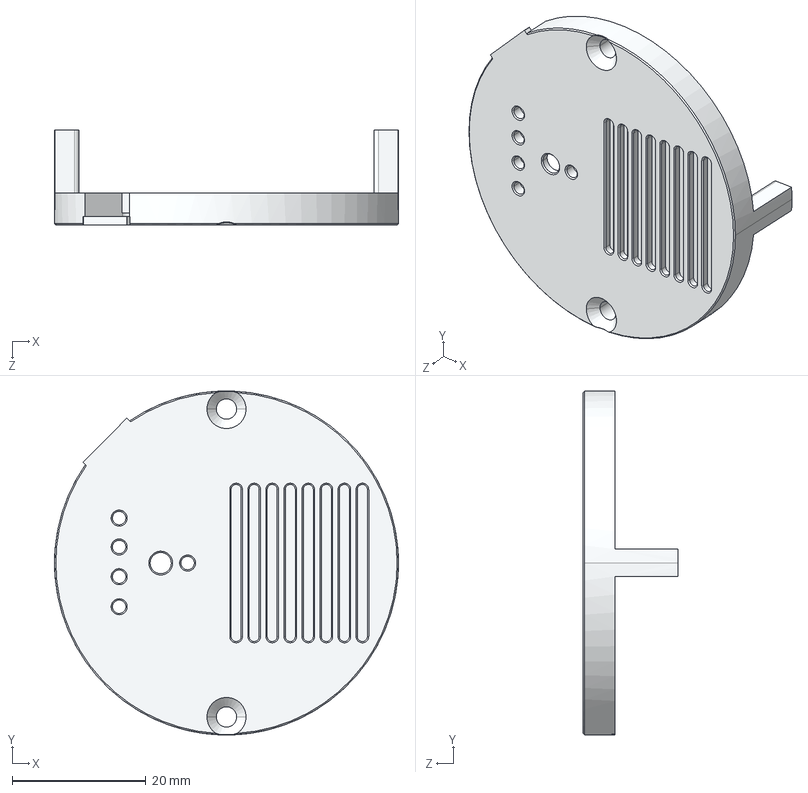
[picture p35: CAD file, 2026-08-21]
机械/电池架3D制造文件/3D图/充电板顶部散热铜柱.STEP
51.5 x 51.5 x 14.2 mm

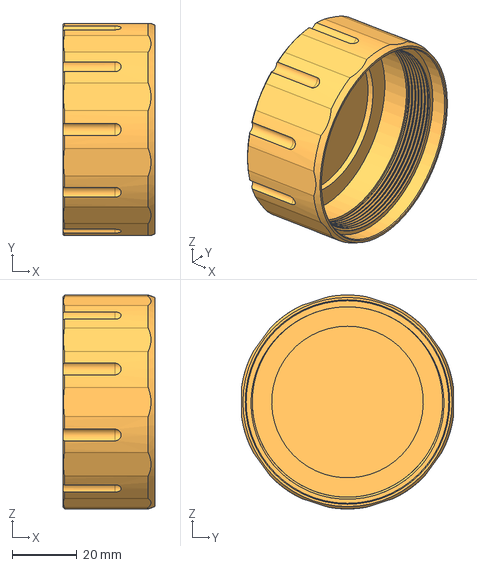
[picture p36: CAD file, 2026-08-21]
机械/筒身3D制造文件/STEP/尾盖.stp
28.5 x 65.4 x 66.0 mm

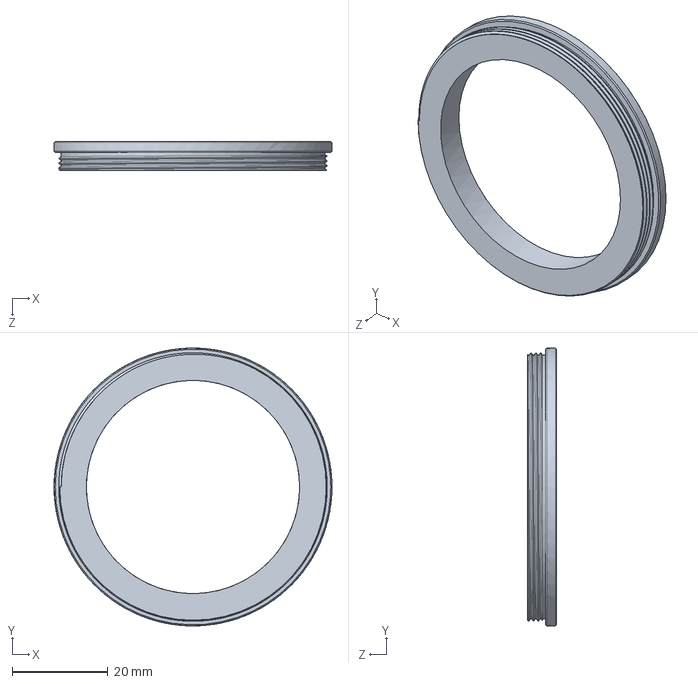
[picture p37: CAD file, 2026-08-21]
机械/筒身3D制造文件/二代驱动压环.SLDPRT
58.0 x 58.0 x 6.05 mm

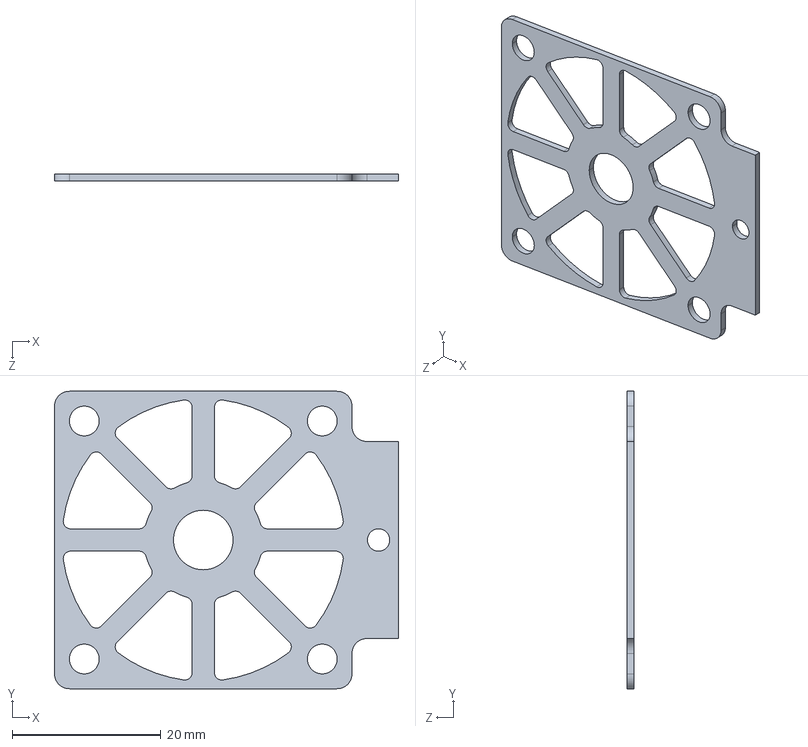
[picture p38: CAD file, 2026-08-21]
机械/风扇把手相关3D制造文件/3D制造文件/40风扇不锈钢夹片.STEP
46.2 x 40.0 x 1.00 mm

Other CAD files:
机械/电池架3D制造文件/2D图/均衡板支撑柱.DWG
机械/电池架3D制造文件/Parts/均衡板支撑柱.SLDPRT
机械/电池架3D制造文件/垫片2D图/充电板背部0.2青稞纸垫片.DWG
机械/风扇把手相关3D制造文件/40风扇尼龙外框.SLDPRT
机械/电池架3D制造文件/Parts/电池架底座正极限位垫圈.SLDPRT
机械/电池架3D制造文件/垫片2D图/保护板下部1.0厚EPDM垫圈.DWG
机械/光学相关文件/FL8032P.SLDPRT
机械/电池架3D制造文件/2D图/充电板顶部散热铜柱.DWG
机械/电池架3D制造文件/2D图/电池架底座.DWG
机械/电池架3D制造文件/2D图/顶部导热块.DWG
机械/电池架3D制造文件/3D图/电池架底座.STEP
机械/电池架3D制造文件/3D图/顶部导热块.STEP
机械/电池架3D制造文件/Parts/21700电池.SLDPRT
机械/电池架3D制造文件/Parts/上端电池接触点.SLDPRT
机械/电池架3D制造文件/Parts/下端电池接触板.SLDPRT
机械/电池架3D制造文件/Parts/中心铜柱不锈钢螺丝.SLDPRT
机械/电池架3D制造文件/Parts/保护板SMT铜柱.SLDPRT
机械/电池架3D制造文件/Parts/充电板.SLDPRT
机械/电池架3D制造文件/Parts/充电板PCB.SLDPRT
机械/电池架3D制造文件/Parts/充电板背部0.2青稞纸垫片.SLDPRT
机械/电池架3D制造文件/Parts/充电板顶部散热铜柱.SLDPRT
机械/电池架3D制造文件/Parts/同口保护板.SLDPRT
机械/电池架3D制造文件/Parts/均衡和充电铜柱.SLDPRT
机械/电池架3D制造文件/Parts/均衡控制板.SLDPRT
机械/电池架3D制造文件/Parts/导电铜柱.SLDPRT
机械/电池架3D制造文件/Parts/正极中通达铜镀金.SLDPRT
机械/电池架3D制造文件/Parts/正极铜接触点.SLDPRT
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

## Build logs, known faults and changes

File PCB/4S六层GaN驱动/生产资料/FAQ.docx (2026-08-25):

驱动复刻调试FAQ

问题1：驱动上电后心跳LED持续快闪，侧按LED报错Fault_DCDCPreChargeFailed（侧按指示灯红黄绿交替闪，停顿0.5秒后红色闪烁7次）

解决思路：使用万用表测量驱动输出端，并上电。如果输出电压不等于19V附近，检查R32是否开路，C56是否短路，U11是否损坏。如果上述原件都正常，则给驱动重新上电，测量U11四脚是否有一个瞬间存在的约4.4-5V的电压。如果没有，则尝试为MCU（U8）重新刷写固件，仍然无效则更换U8。若预充电路正常，则检查CV环注入电阻R14，DCDC FB电阻R41、R42、R11以及输出电压监视器的分压电阻R21、R23以及R34（可以通过上电时测量R23和R34两端电压判断是否正常，如果R23两端电压不满足VR23=输出电压*(56/((470*2)+56))的规律，则电阻阻值错误或者R21和R23、R34贴反，如果R21和R23贴反则会损坏MCU内的ADC模块故需要更换U8）。

问题2：驱动在装机过程中输出意外短路冒烟，处理好短路后重新安装输出只有低亮档，其余挡位消失，开关机正常。

解决思路：驱动使用可调电源供电并开机，输出连接假负载LED，通过按键板进行换挡并使用万用表测量D4引脚1以及2的对地的电压，电压应如下表所示：

挡位 | 对应D4引脚1和2的电压
月光 | 0.0039V
极低亮 | 0.018-0.02V
低亮 | 0.09-0.1V
中亮 | 0.18-0.2V
中高亮 | 0.3-0.4V
高亮 | 0.68-0.73V
极亮 | 4.15V-4.4V

如果D4的引脚1和2电压严重偏低，则检查D4引脚3，正常状态下应当为5V，如果电压偏低则更换U9。更换U9后仍然出现D4的引脚1和2电压严重偏低的情况，则更换MCU(U8)。

更换完毕后如果问题仍未得到解决，则测量FB注入运放U6的第一脚对地电压，如果不为0V则直接更换U5。如果为0V则测量R8电阻两端对地电压，若不为1.2V则说明DCDC部分故障，此时可尝试更换控制器U1。

问题3：驱动在上电时偶尔能正常通过自检，偶尔或完全报错Fault_DCDCFailedToStart（侧按指示灯红黄绿交替闪，停顿0.5秒后红色闪烁1次）

解决思路：驱动使用可调电源上电，并测量电容C12两端的电压。正常值应当为7.2-7.5V之间。如果电压值异常，则测量辅助电源IC（U2）第三脚电压是否为0.8V，如果是则检查辅助电源反馈电阻R4、R5。如果U2第三脚电压异常，则尝试更换U2，电感L3，电容C12和C42。

更换完毕仍然无效则说明辅助电源存在短路或严重漏电，此时可以在电感L3上对地连接一个7.5V直流电源并观察电流，电流异常则尝试拆除U4、U3以及U1。

若C12两端正常有电压，则检查DRVCC电源电容C15两端是否有5V电压输出。正常情况下，C15两端的电压应该在4.98V至5.08V之间。如果没有电压或者电压只有0.7V-0.9V，则尝试检查并更换U12、R51、R50、C68、C69、L4。并检查D10有没有焊反。仍无效则更换U1。

若C15两端正常有电压，则检查R52两端是否有1.2至1.5V之间的电压，如果没有，尝试更换R52、R53、D8。仍然无效则更换U1和MCU（U8）

问题4：驱动的电量指示功能异常，例如电池明明是满电状态却提示电量过低无法开机或自动降档，或者电池已经耗尽仍然提示电量充足。

解决思路：驱动连接到16V可调电源上电，检查电阻R22两端电压是否满足VR22=电池电压*(100/(820+100))的规律。如果电压严重偏低（0-0.几V）则检查二极管D3是否焊反，U8引脚是否连锡，都正常的话更换U8。如果电压严重偏高则检查R20和R22阻值是否正确，如果电阻R22的两端电压高于2V则在更换完R20和R22后还需要更换U8，否则后期电量和温度测量可能故障。

问题5：驱动上电开机后发出刺耳的啸叫，而且输入电流巨大可调电源直接5A打表，输出的LED亮度不稳定一直频闪。

解决思路：检查DCDC部分的环路补偿原件（R33，C31，C17）、电流采样滤波器（C48、R43、C7、R7）以及开关频率设置电阻R35的参数是否符合原理图的配置。同时检查FB注入部分的环路补偿元器件（C37、R15、R16、R17、C70）的参数是否正确。如果都正常，则尝试更换U1、U6、U5。

问题6：驱动上电后没有任何反应，按下按键板尝试开机也无法开机。

解决思路：为驱动通上16V电源，使用万用表测量电容C39两端电压，正常电压应当为稳定的5V。如果没有电压，请检查并更换FB2、U7、C40和C39。仍然无效则更换MCU(U8)。如果电压正常，且更换MCU（U8）后固件仍然无法启动，则请尝试为MCU重新刷入固件，并且检查固件所对应的烧录设置（见固件文件夹内的FW_README.md）是否匹配。当MCU内的固件正常启动时，驱动背部的固件心跳LED（D5）将会点亮。

问题7：驱动在非极亮挡位下正常工作，但开启极亮挡位时立即保护，且驱动背面某处温度极高。

解决思路：使用大功率可调电源为驱动通上16.8V电源，连接上LED并且让驱动开机，通过按键操作让驱动运行在高亮档。使用热成像观察主板正面的两组MOS管（Q1、Q6、Q

7和Q2、Q3、Q4）的温度数据是否较为接近。如果某组MOS管温度严重偏低接近室温，说明该组MOSFET未处于工作状态，则请使用示波器测量U1的20和31引脚的波形，正常状态下的两个引脚的波形都应该是频率为460KHz左右的方波且相位错开180度，如果观察到某一组引脚为一条直线则说明U1故障，请更换U1，如果更换U1后仍然没有波形，则请检查DCDC辅助自举部分电路（D1、D2、R48、R49）是否正常，如果正常，则说明对应的MOSFET故障，请更换MOSFET(Q1、Q6、Q7和Q2、Q3、Q4)。

问题8：驱动在关机状态下以及SOS和信标模式运行过程中的熄灭状态下能观察到LED微微发亮出现漏光/漏电现象。

解决思路：使用万用表二极管档测量Q5是否击穿，如果击穿则同时更换U3、Q5。更换Q5后如果仍然漏光，则更换U3。

问题9：驱动在其余挡位运行正常，但是在长按进入的月光挡位下亮度异常偏高，和循环挡位中的及低亮度挡位相差无几。

解决思路：长按开关使驱动运行在月光档，然后使用万用表电压档测量U9的第一脚电压。正常应该在0.003-0.005V之间，如果电压异常，则检查电阻R24 R25是否开路，C44 C45是否短路或者开路，并更换D4。电压正常的话测量U9第四脚电压，应基本和U9第一脚电压一致，如不一致则U9损坏，更换U9。

问题10：驱动焊接完毕后使用CMS ICE8 PRO调试器尝试烧录固件时认不到芯片，IDE软件提示如下错误：

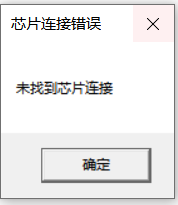
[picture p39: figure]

解决思路：首先请检查调试器的5V输出电源是否正常，并检查调试器到驱动主板上的探针定义连接是否正确（参考下图）。

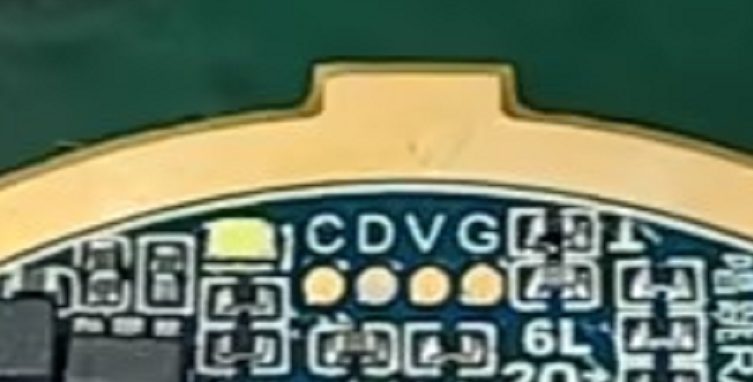
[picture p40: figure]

板子从左到右定义分别为:CLK DAT VDD GND，按照调试器上的pinout连接即可。如果仍然无效则检查触点V和G之间是否存在短路，正常情况下给V和G触点通电，V和G之间的电流不应大于5mA。如果存在短路则逐个更换C39、U7、C41、U10（需要检查U10是否焊反）以及U8。若不存在短路则说明MCU可能已损坏，更换U8再试。

问题11：驱动上电后正常通过自检也能正常点亮LED，但是通电瞬间发出巨响，经检查U1上面炸毁出凹坑。

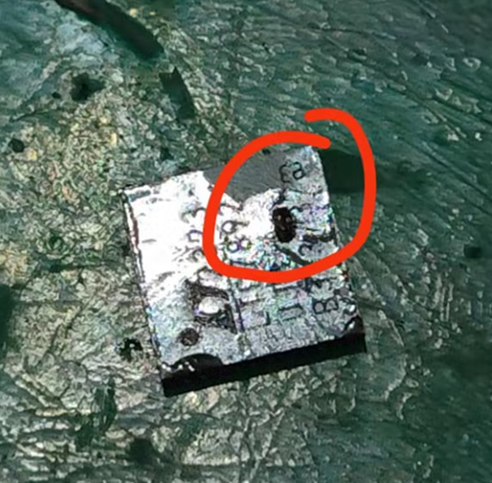
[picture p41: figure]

解决思路：该问题通常是由于辅助自举模块故障或自举电容短路（可能是焊接固态电容时锡膏流到电容下方）、以及DRVCC超压导致。首先检查自举电容C10、C62两端以及对地是否存在短路，建议用热风枪拆下并焊接新电容。并且检查二极管D1、D2是否击穿，R48、R49阻值是否正常，如果不正常则更换。正常的话，上电检查电容C15两端电压是否在4.95-5.05V之间，若不正常则尝试检查并更换U12、R51、R50、C68、C69、L4并检查D10有没有焊反。

问题12：驱动上电后按键灯保持熄灭三秒后持续红色常亮，无法开机其他操作也无反应。

解决思路：该问题通常由输出电容短路导致无法完成预充，MCU内固件视为硬件异常进入锁死状态。您需要检查输出MLCC阵列中的电容（参见原理图）以及输出端的固态电容C3、C4、C16是否存在短路。

此故障一旦发生，会导致旁路二极管D6、MOSFET Q1、Q3流经巨大的短路电流并炸毁上述元器件。因此二极管D6，MOSFET Q1、Q3需要在排除短路后直接进行更换处理，以免后续使用存在隐患。

问题13：驱动虽然能正常工作，但是在低输出功率的挡位下功耗严重偏高，且驱动严重发热。

解决思路：该问题通常是DCDC模块的死区配置和工作模式设置电阻异常导致。检查控制器U1外围的频率设置电阻R35、工作模式设置电阻R38以及死区配置电阻R39、R40是否正常。如果正常，则尝试更换控制器U1，六个开关MOSFET(Q1、Q6、Q7和Q2、Q3、Q4)以及栅极驱动电阻R44到R47、R6、R8、R9、R10。

问题14：驱动虽然能正常工作，但是驱动的温控系统动作不正常，出现温度极高都不动作或者驱动还是凉的就提示过热降档。

解决思路：该问题是由于温度检测模块检测异常导致。首先您需要刷写由作者编译的预编译固件以便于排除由于固件编译异常导致的问题。若烧录后问题仍然不变，则说明问题由硬件导致。您需要检查电阻R29、NTC热敏电阻R30、电容C47是否和原理图的数值对应。并检查U8的第8脚是否输出接近5V的电压。若电压异常或更换测温部分的元器件（C47、R29、R30）后问题仍未解决，则说明MCU已损坏。请更换U8并重新刷写固件。

若您需要验证问题是否解决，可以在给驱动通电并通过自检后，对按键进行三击+长按操作唤起温度查询模块（具体播报方式请查看项目根目录的GT-X2_UI逻辑.pdf），查看驱动测量到的当前板端温度是否和当前环境温度存在较大出入。

问题15：驱动的按键功能不太好使，经常出现多次单击漏掉或多出一次的情况，甚至出现未按下按键但是莫名其妙自己开机的问题。

解决思路：该问题是由于按键检测部分电路出现问题或按键本身损坏导致。首先您需要刷写由作者编译的预编译固件以便于排除由于固件编译异常导致的问题。如问题仍然持续，则需要更换按键板上的按键。

需要注意的是，不建议使用热风枪直接吹焊的方式焊接这种金属壳锅仔片按键，并且应避免洗板水和焊油进入按键内部，否则按键会出现触发不灵敏，甚至漏电导致错误按键事件被探测到从而使得手电莫名其妙自行开启。因此您应当使用电烙铁和少量锡膏分批焊接按键的四个脚。

如果更换了按键后问题仍未解决，则请检查按键板连接到主板的定义是否正确，以及驱动板子上的按键电路保护TVS U10，按键上拉电阻R27是否正常并更换上述元器件。更换完毕后仍然无效，则说明MCU已损坏。请更换U8并重新刷写固件。

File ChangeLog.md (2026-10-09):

# 更新日志

## [1.1.0.6] - OCT-09-2026 15:32

本次更新主要针对机械部分，因此省略其余固件和硬件的内容。

### 其余更新

1. 调整电池架组装视图内部分零部件的样式匹配实物解决可能的漏电危险。
2. 为均衡板和电池架的支撑柱单独输出2D和3D图以便于CNC加工。
3. 增加readme说明关于电池架使用的部分可直接购买的标准件的购买连接。
4. 新增电池架底座和保护板之间的限位垫圈解决EPDM硬度不够导致保护板PCB被拉变形的问题。
5. 新增实验性的驱动仿真配置文件（可以输出更大电流但是不建议这么干，只是仿真着玩）

## [1.1.0.5] - OCT-08-2026 09:30

### 驱动固件勘误

1. 修复系统在开机状态下通过双击由循环挡位直接进入极亮挡位后，进入之前的挡位未被正确记忆的问题（由KIPA发现）

### 电池棒控制器固件勘误

本次没有电池棒控制器固件勘误内容

### 驱动固件更新

1. 减缓驱动固件在极亮MPPT尝试时抬升电流的速度，确保性能不足的电池能被正确检测。
2. 调整8032P Gen2版本的固件至输出43.75A，使得极亮输出具备16万LM
3. 新增限制全功率爆闪模式下限制爆闪电流不超过43.2A的功能，可以避免保护板误触发保护。

### 电池棒控制器固件更新

无

### 风扇控制器固件勘误

本次没有风扇控制器固件勘误内容

### 风扇控制器固件更新

1. 调整源码默认的风扇速度钳位值至99.9%

### 其余更新

1. 新增降额到14万LM的低电流固件用于在元器件性能不足时解决驱动直接保护的问题。
2. 调整风扇把手打印件的形状，去除内部的额外支撑大幅降低使用高速暴力扇的风阻。
3. 对主驱动的部分物料进行调整以优化月光挡位的运行和并且避免宽温条件下可能引起问题的地方。

## [1.1.0.4] - SEP-21-2026 16:12

### 驱动固件勘误

无

### 电池棒控制器固件勘误

本次没有电池棒控制器固件勘误内容

### 驱动固件更新

1. 针对部分硬件电流偏高的问题重新调整电流系数

### 电池棒控制器固件更新

无

### 风扇控制器固件勘误

本次没有风扇控制器固件勘误内容

### 风扇控制器固件更新

无

### 其余更新

1. 新增取消电流补偿的预编译驱动固件。
2. 机械部分新增电池架的完整装配信息视图。

## [1.1.0.3] - SEP-18-2026 09:10

### 驱动固件勘误

1. 修复进入和退出战术模式时，系统的睡眠延时未被正确加载导致战术模式自行异常退出并进入休眠的bug

### 电池棒控制器固件勘误

本次没有电池棒控制器固件勘误内容

### 驱动固件更新

1. 新增FL8032P Gen2也就是2代8032P对应的固件灯珠配置入口。
2. 调整Turbo模式极亮降档的常亮电流至12000mA，匹配禁赛级高速风扇把手的散热能力提高常亮性能。

### 电池棒控制器固件更新

1. 调整手动均衡的电池压差结束点至10mV，允许用户更进一步修正电池的压差水平。
2. 调整禁充模块的控制逻辑，在手动均衡开启过程中禁止通过C口充放电以避免均衡器过热。

### 风扇控制器固件勘误

本次没有风扇控制器固件勘误内容

### 风扇控制器固件更新

1. 调整风扇固件的电池电量和电压播报逻辑。针对负数温度以及超过9.99V电压（虽然硬件无法承受可能会损坏板子）的情况做额外的入口播报提示。
2. 调整积分温控的温度回升逻辑解决风扇速度反复蹦迪的问题。

### 其余更新

1. 对[续航测试总表](GT-X2%E7%BB%AD%E8%88%AA%E6%B5%8B%E8%AF%95%E6%80%BB%E8%A1%A8.xlsx)进行修订，新增使用8032P Gen2灯珠的续航测试结果。
2. 对预编译固件进行更新配合驱动和电池棒控制器固件的更新。
3. 对项目的主Readme进行调整，新增独立的出光性能章节。

## [1.1.0.2] - SEP-11-2026 11:40

### 驱动固件勘误

本次没有驱动固件勘误内容

### 电池棒控制器固件勘误

本次没有电池棒控制器固件勘误内容

### 驱动固件更新

本次没有驱动固件更新内容

### 电池棒控制器固件更新

本次没有电池棒控制器固件更新内容

### 风扇控制器固件勘误

本次没有风扇控制器固件勘误内容

### 风扇控制器固件更新

1. 对禁赛版本风扇控制器固件的代码进行格式规范化处理和整理，提高可读性。

### 其余更新

无

## [1.1.0.1] - SEP-03-2026 17:20

### 驱动固件勘误

本次没有驱动固件勘误内容

### 电池棒控制器固件勘误

本次没有电池棒控制器固件勘误内容

### 驱动固件更新

本次没有驱动固件更新内容

### 电池棒控制器固件更新

本次没有电池棒控制器固件更新内容

### 风扇控制器固件勘误

1. 修复普通版本暴力风扇驱动固件的电池配置锁功能未正确生效的bug
2. 修复禁赛版本暴力风扇驱动固件的电池配置锁异常导致固件无法启动的bug

### 风扇控制器固件更新

1. 修改暴力版本风扇固件的温控逻辑，改为积分温控避免纯线性温控风扇速度反复横跳的bug

### 其余更新

1. 调整同口保护板的部分物料使用，解决特定情况下被动均衡MOSFET会击穿漏电损坏的问题。
2. 重新编译风扇把手的固件文件

## [1.1.0.0] - SEP-03-2026 17:20

### 驱动固件勘误

本次没有驱动固件勘误内容

### 电池棒控制器固件勘误

本次没有电池棒控制器固件勘误内容

### 驱动固件更新

本次没有驱动固件更新内容

### 电池棒控制器固件更新

本次没有电池棒控制器固件更新内容

### 其余更新

1. 新增43000RPM超暴力风扇把手驱动的PCB文档和生产资料（包括原理图、PCB打样文件、工艺要求等）。
2. 新增43000RPM超暴力风扇把手驱动的固件源代码和预编译固件。
3. 更新项目主Readme新增超暴力风扇把手的说明并修正部分文字错误。
4. 续航汇总表更新中白版本GT-X2的英文版本续航总览。

## [1.0.0.1] - AUG-25-2026 18:35

### 驱动固件勘误

本次没有驱动固件勘误内容

### 电池棒控制器固件勘误

本次没有电池棒控制器固件勘误内容

### 驱动固件更新

本次没有驱动固件更新内容

### 电池棒控制器固件更新

本次没有电池棒控制器固件更新内容

### 其余更新

1. 续航汇总表更新中白版本GT-X2的月光挡位续航参数
2. 驱动生产资料更新驱动复刻调试的FAQ文档方便复刻时进行调试。
3. 增加本更新和勘误记载文档
4. 微调风扇把手固定块的水平凸台尺寸解决限位过于松垮的问题，并重新生成生产图纸文件。

## [1.0.0.0] - AUG-21-2026 16:18

GT-X2开源资料，github初始发布版本

----------------------------------------------------------------------------------------------------------------------------------
© redstoner_35 @ 35's Embedded Systems Inc.  2026

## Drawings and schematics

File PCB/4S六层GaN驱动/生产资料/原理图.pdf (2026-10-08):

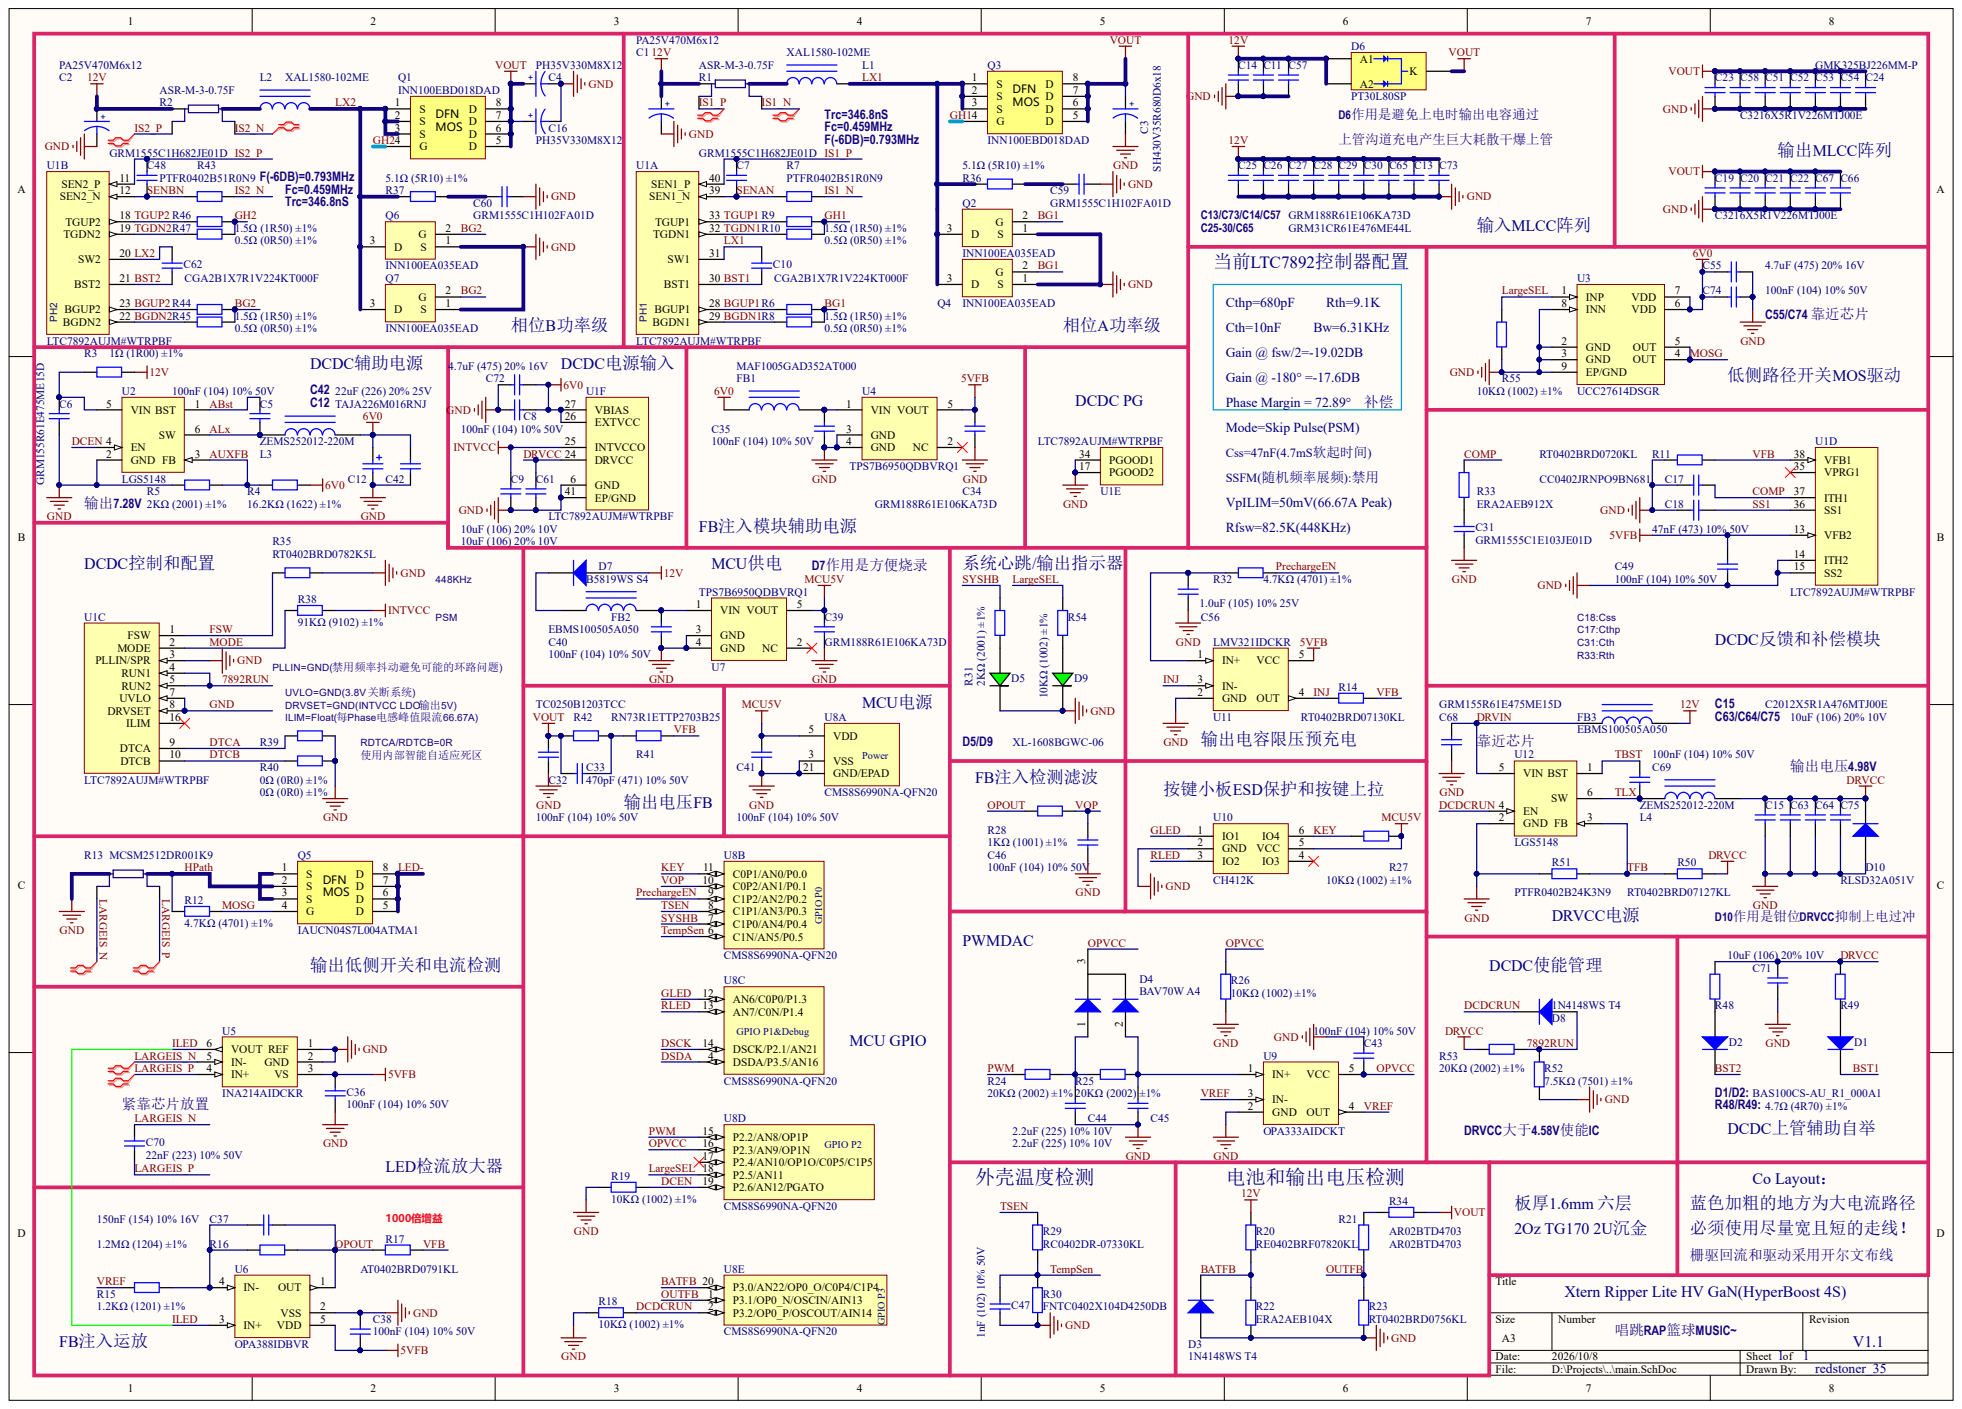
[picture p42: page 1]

VOUT PH35V330M8X12 | PA25V470M6x12 VOUT | 12V 输入MLCC阵列

Mode=Skip Pulse(PSM)

DCDC使能管理 | 10uF (106) 20% 10V DRVCC

D2 BAS100CS-AU_R1_000A1 4.7Ω (4R70) ±1% DCDC上管辅助自举 | | D1

Xtern Ripper Lite HV GaN(HyperBoost 4S)

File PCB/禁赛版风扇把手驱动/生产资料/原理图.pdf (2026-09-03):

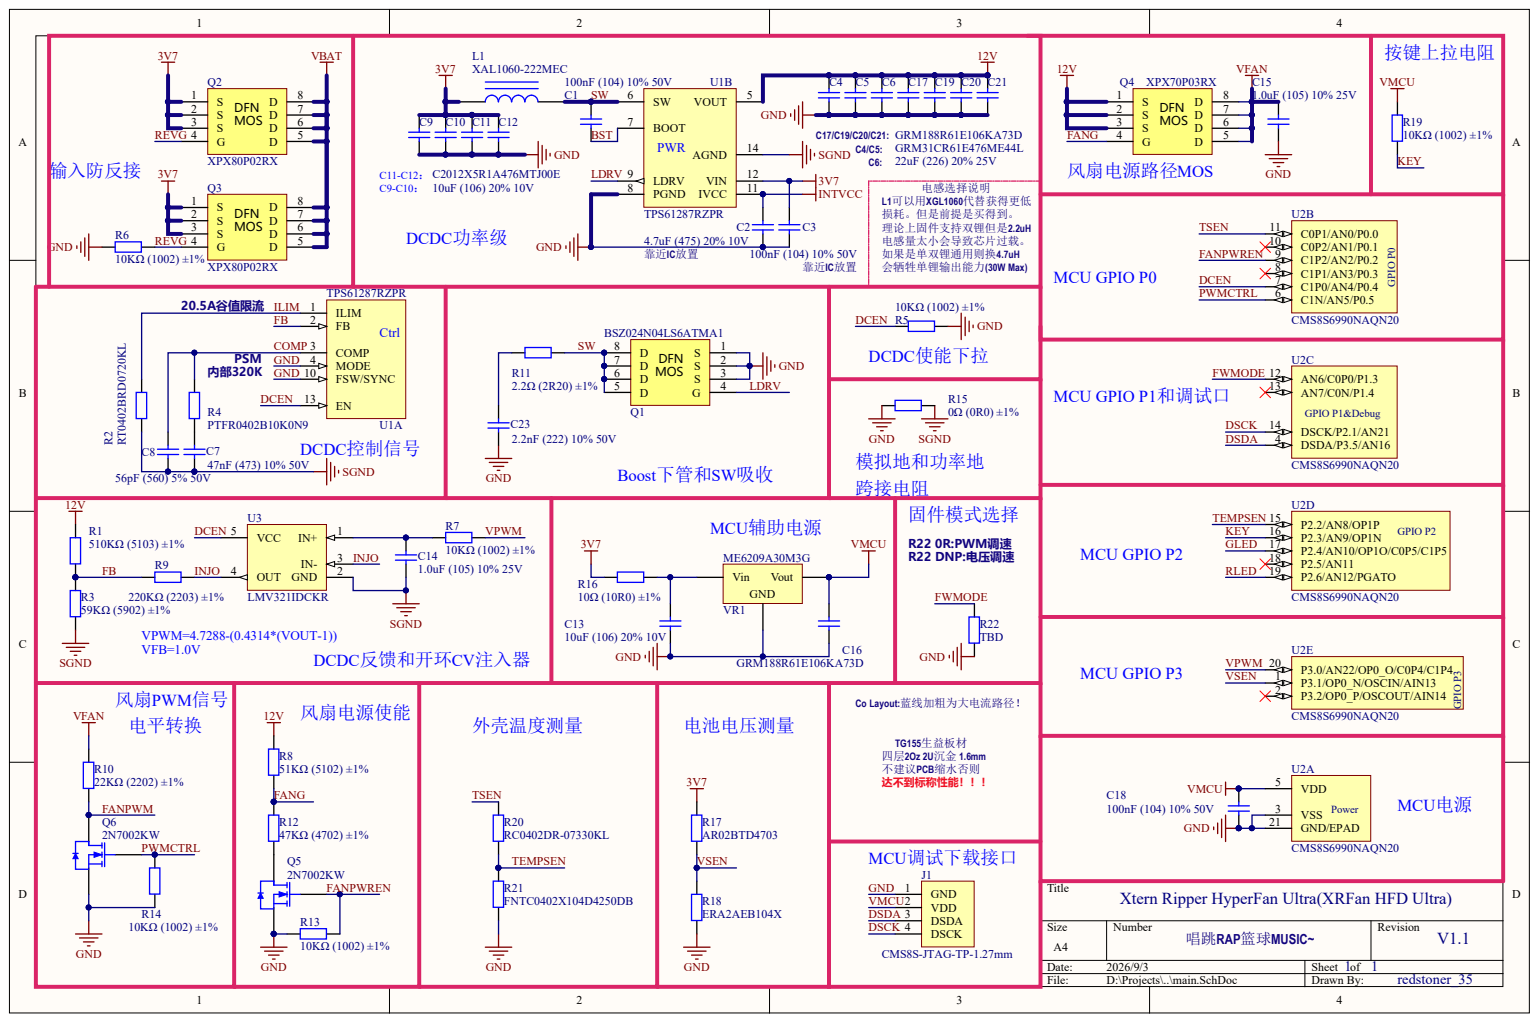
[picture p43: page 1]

3V7 VBAT | L1 12V | | 12V VFAN | 按键上拉电阻 VMCU

Xtern Ripper HyperFan Ultra(XRFan HFD Ultra)

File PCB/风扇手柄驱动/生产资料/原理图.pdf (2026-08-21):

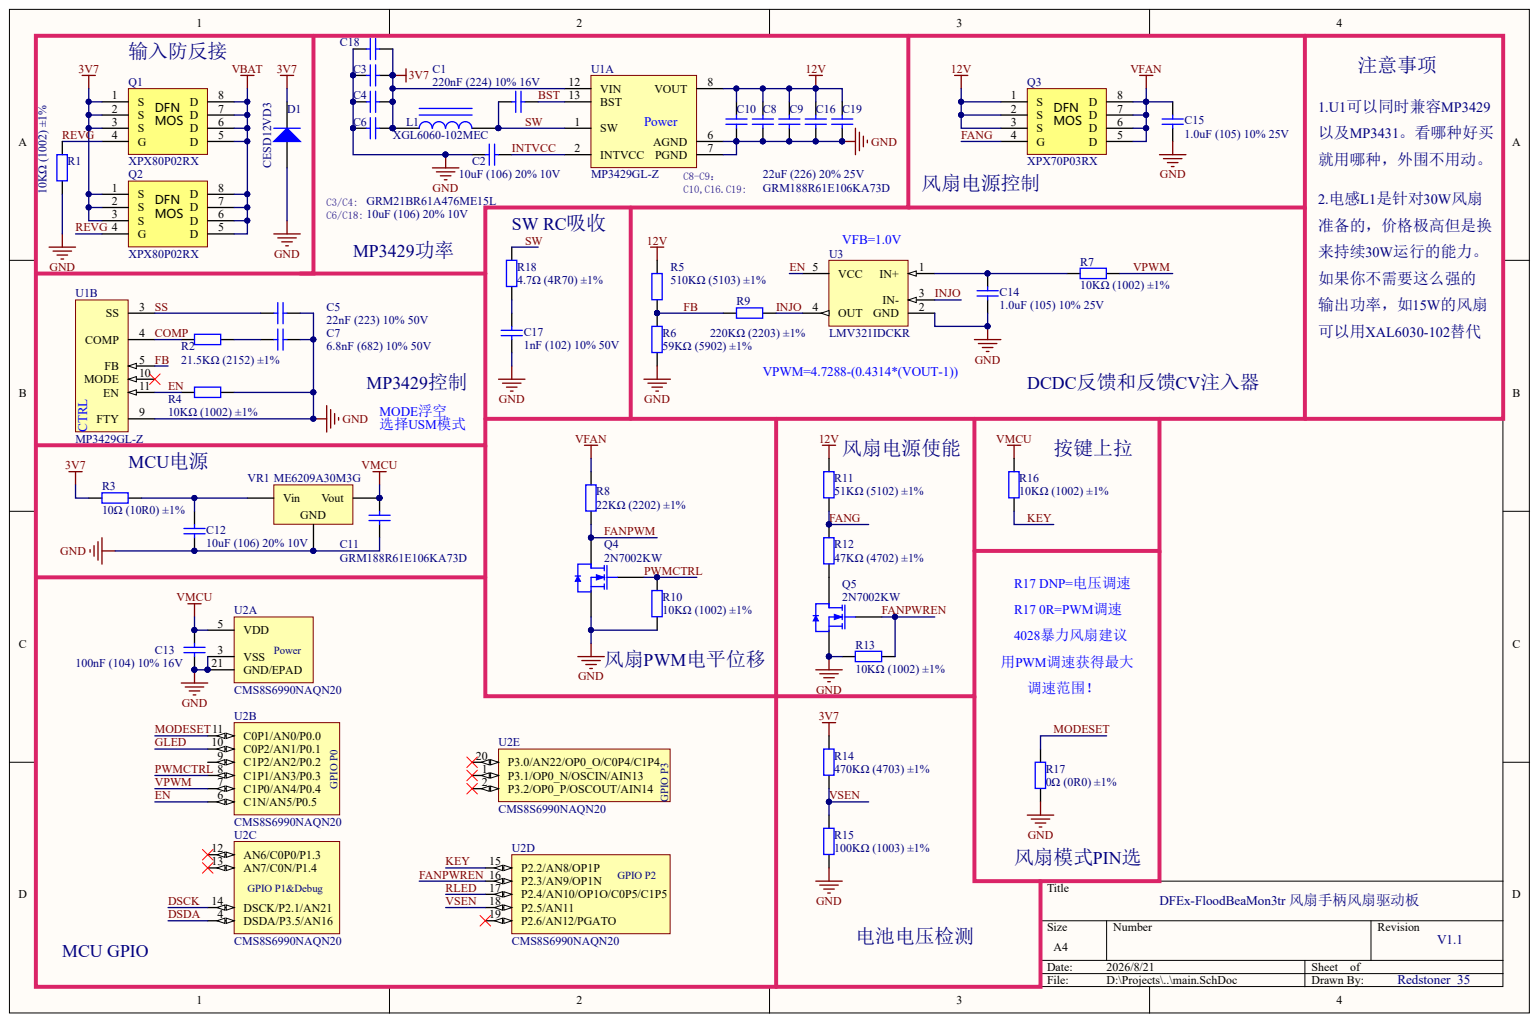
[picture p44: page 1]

VFAN | 12V | VMCU

Title

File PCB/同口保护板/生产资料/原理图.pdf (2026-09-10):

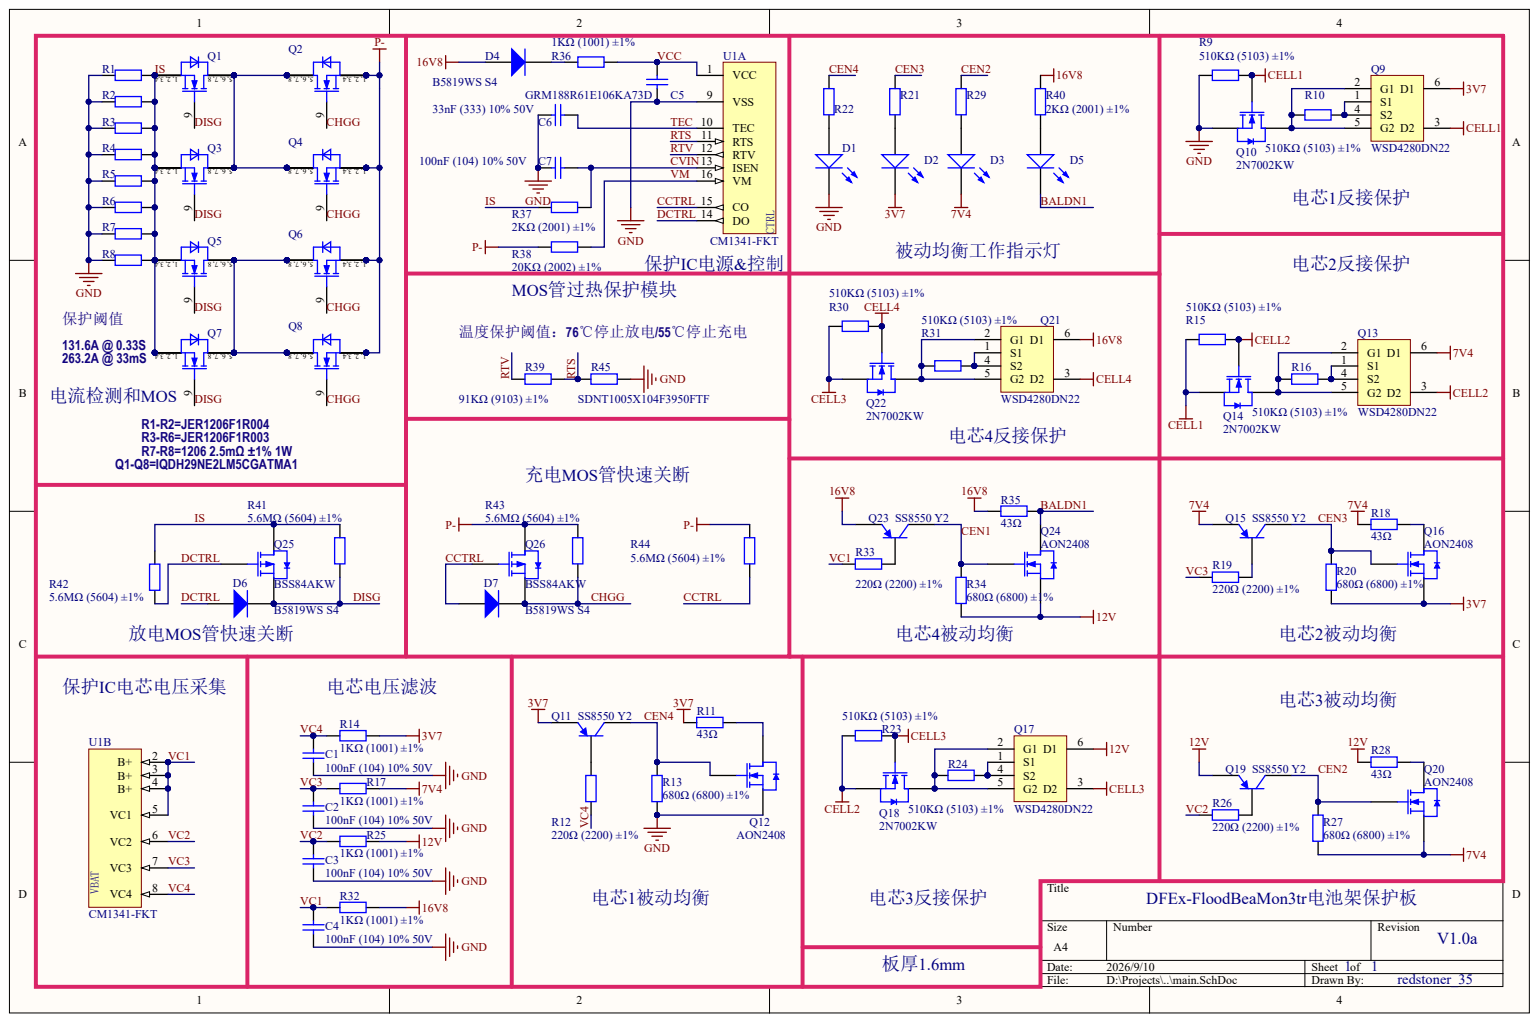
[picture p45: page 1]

DCTRL

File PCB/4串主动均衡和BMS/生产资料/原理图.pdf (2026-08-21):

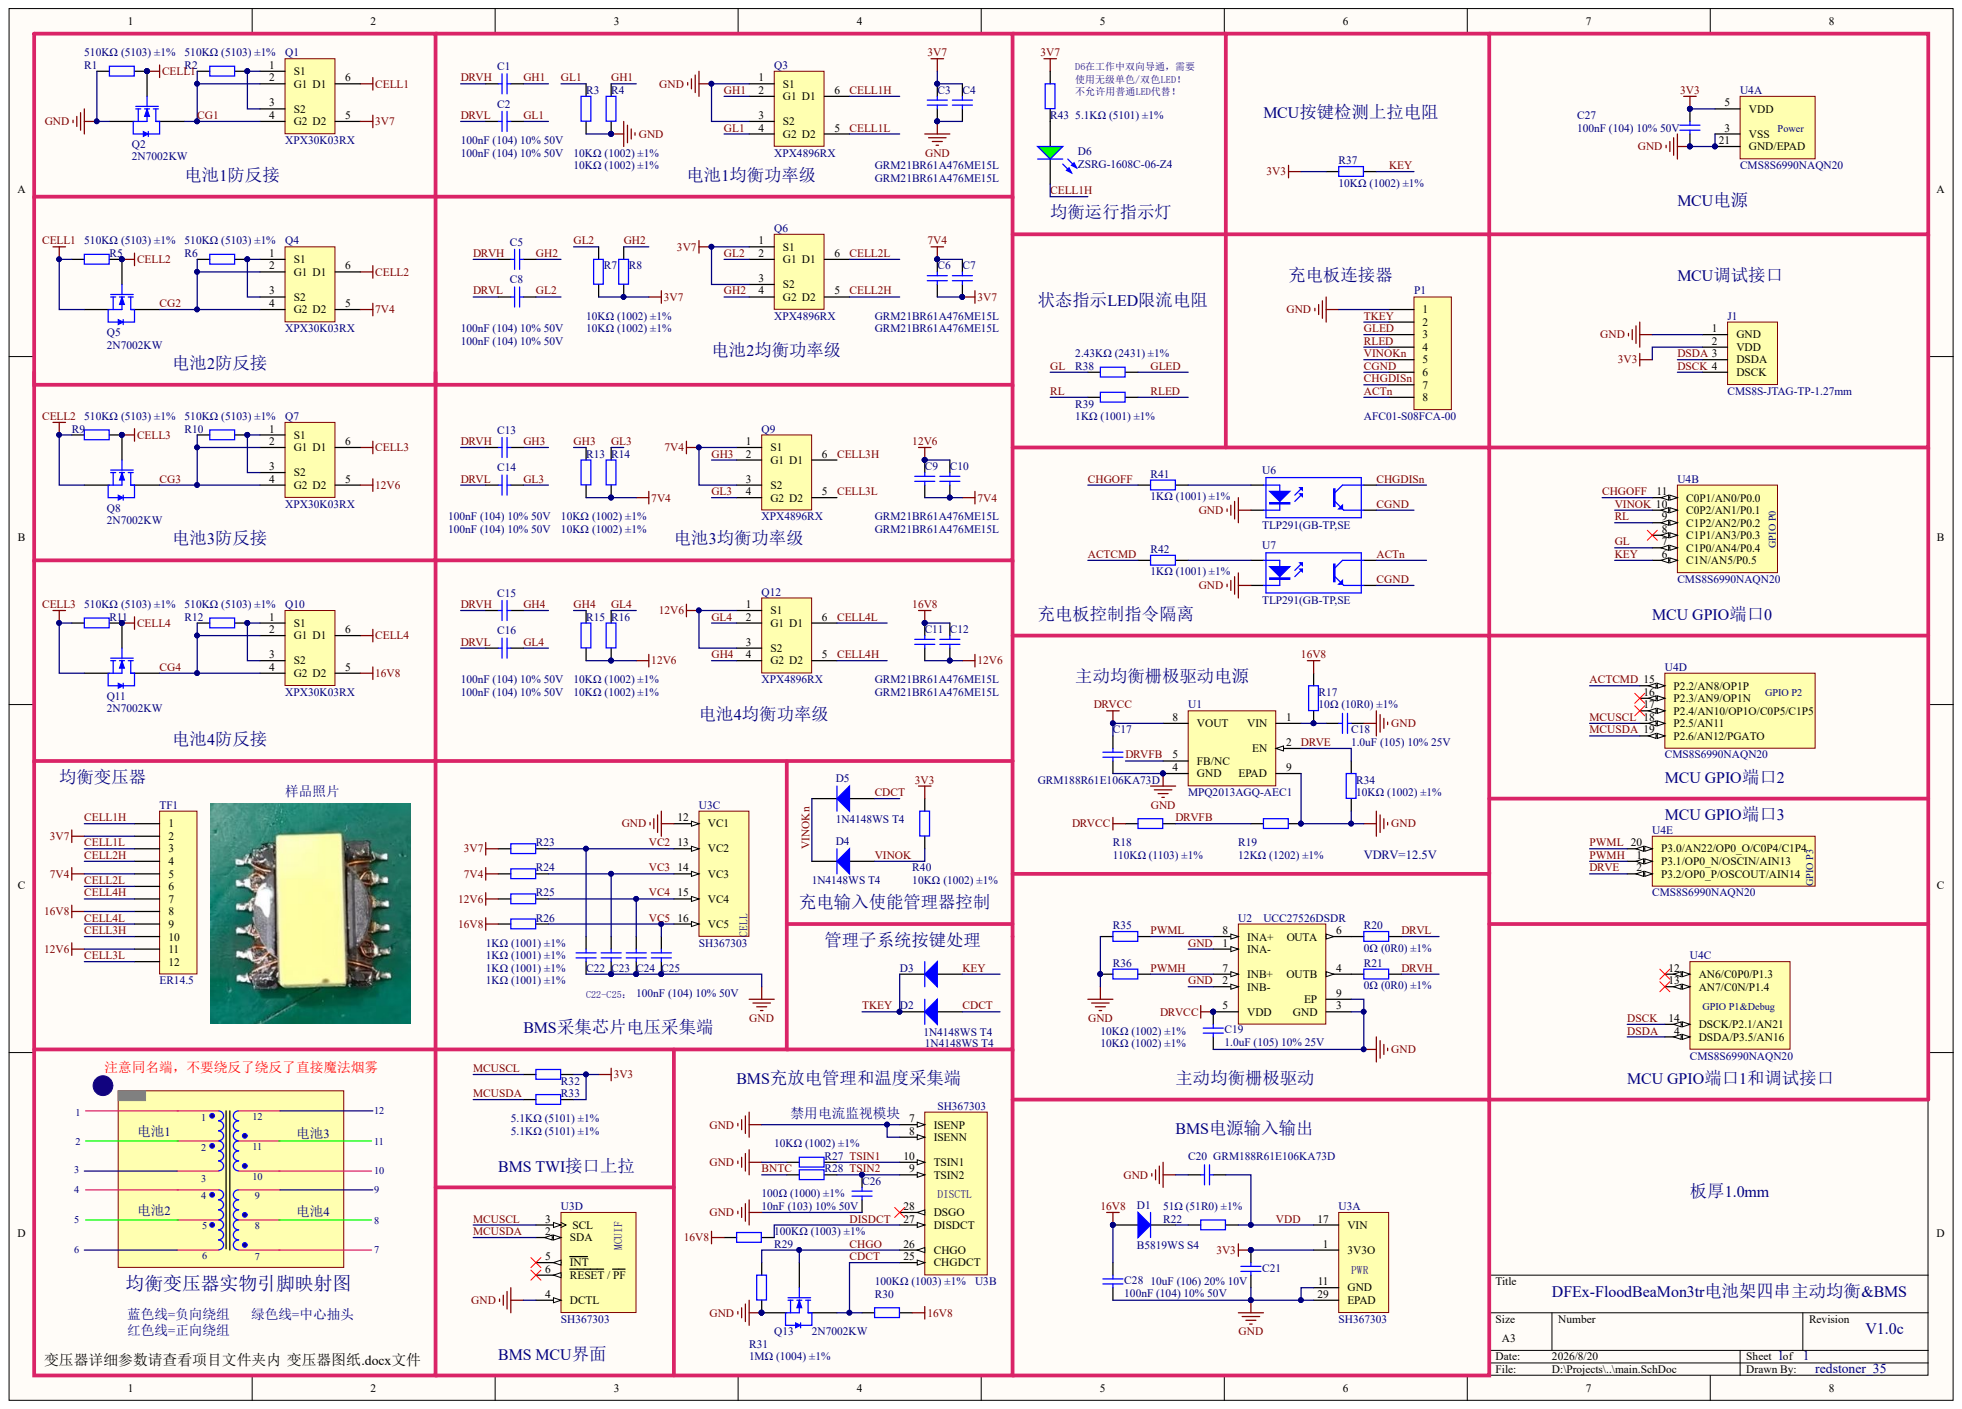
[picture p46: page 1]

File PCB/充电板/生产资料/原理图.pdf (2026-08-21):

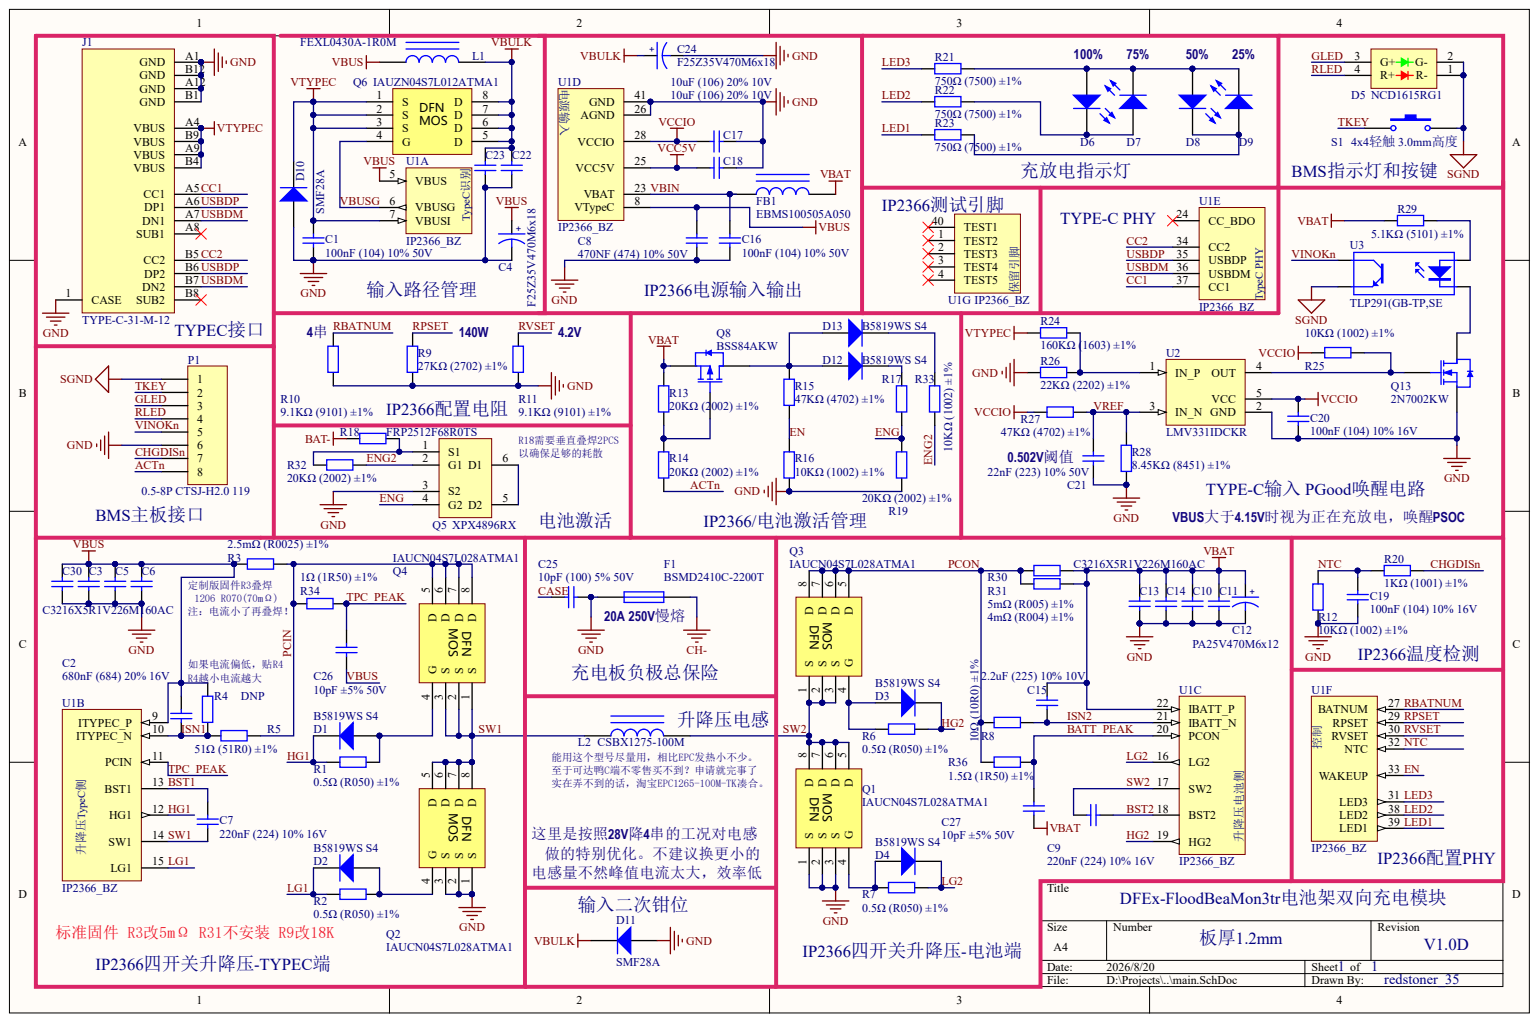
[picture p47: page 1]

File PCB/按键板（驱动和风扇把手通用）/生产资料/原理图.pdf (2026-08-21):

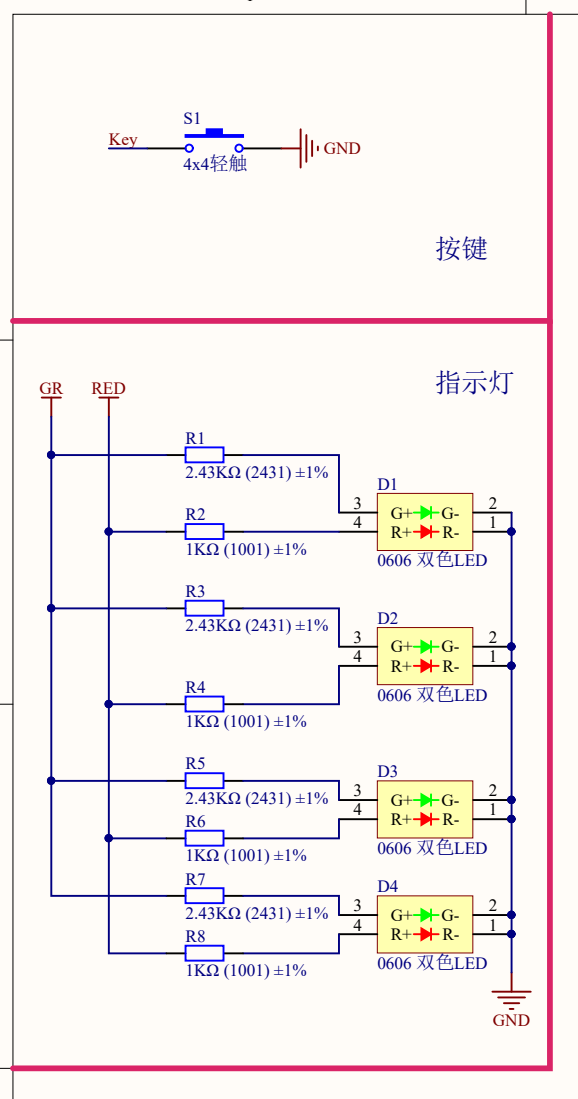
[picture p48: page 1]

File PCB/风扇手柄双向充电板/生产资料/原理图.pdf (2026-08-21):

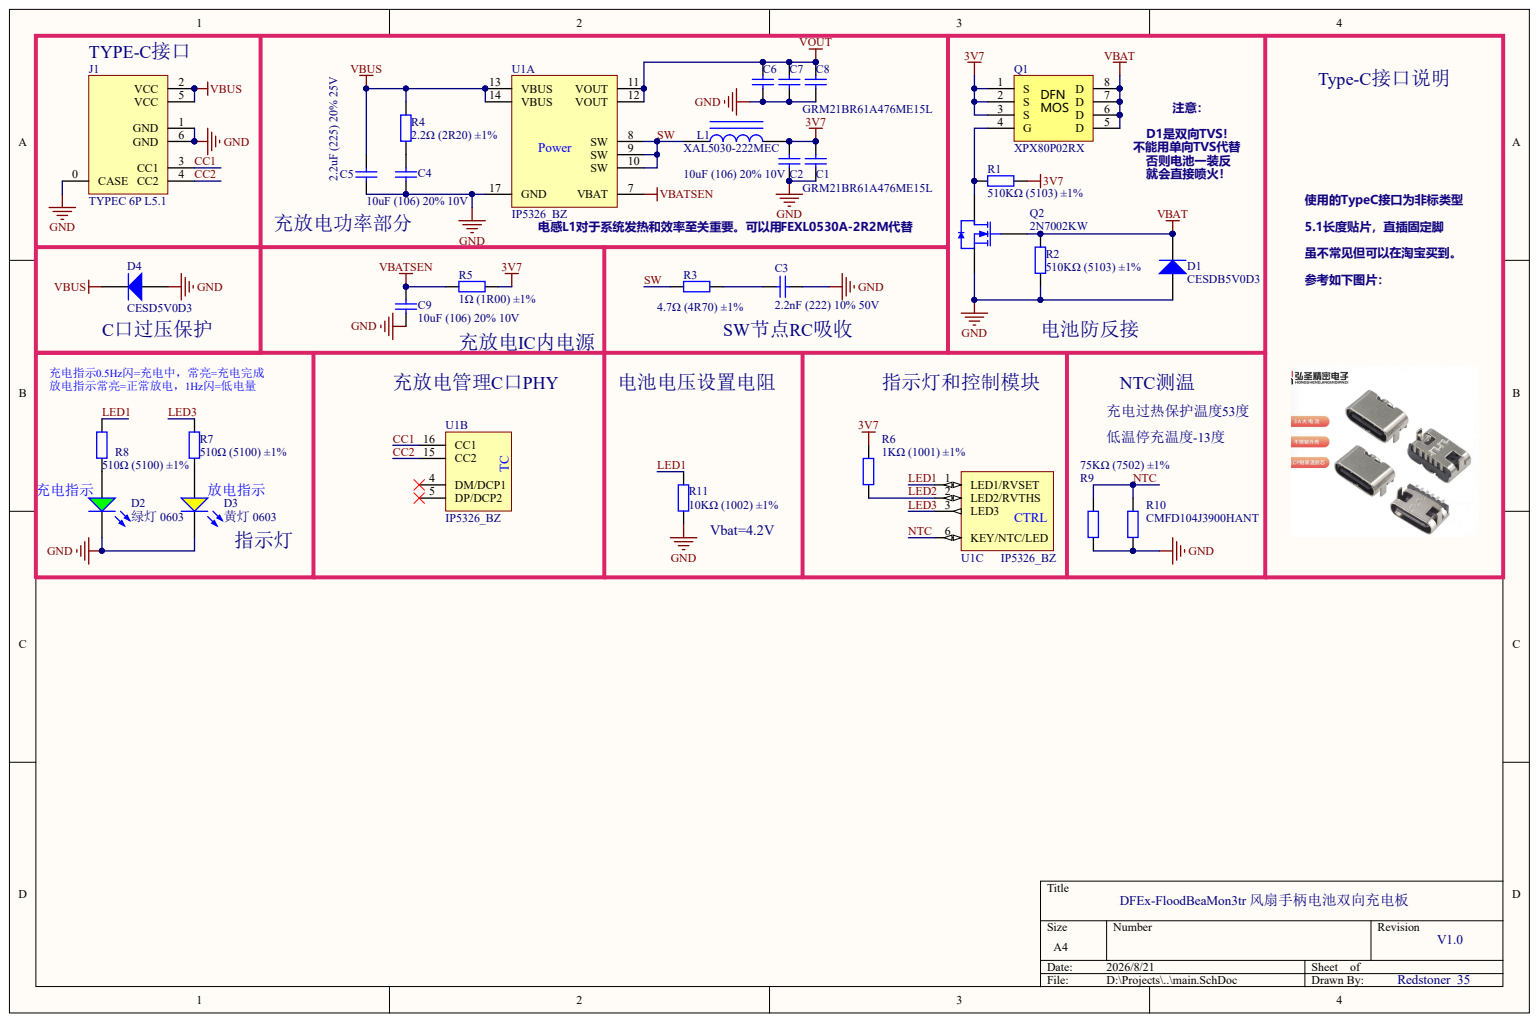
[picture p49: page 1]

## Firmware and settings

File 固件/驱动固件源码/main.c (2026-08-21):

/****************************************************************************/
/** \file main.c
/** \Author redstoner_35
/** \Project Xtern Ripper Hyper Boost HV 4S-GaN Edition
/** \Description 这个文件负责系统的主函数处理

**	History: 
				2025年12月26日 10:05 配合模式管理状态机的函数改动，将电流计算独立为
				                     ApplyOutputCurrent()函数并在主函数内引用。
				2025年12月23日 11:07 移除睡眠管理函数的直接外部声明，改为使用Sleep.h
				2025年12月20日 Initial Release
**	
*****************************************************************************/
/****************************************************************************/
/*	include files
*****************************************************************************/
#include "cms8s6990.h"
#include "GPIO.h"
#include "delay.h"
#include "SideKey.h"
#include "LEDMgmt.h"
#include "ADCCfg.h"
#include "OutputChannel.h"
#include "PWMCfg.h"
#include "BattDisplay.h"
#include "ModeControl.h"
#include "TempControl.h"
#include "SOS.h"
#include "SelfTest.h"
#include "LowVoltProt.h"
#include "Beacon.h"
#include "LocateLED.h"
#include "Strobe.h"
#include "SysReset.h"
#include "SetupMenu.h"
#include "Sleep.h"

/****************************************************************************/
/*	Local variable  definitions('static')
****************************************************************************/
bit TaskSel=0;  //选择处理的系统任务

/****************************************************************************/
/*	Main function implantation('main')
****************************************************************************/
void main(void)
	{
	//时钟和RSTCU初始化	
	ClearSoftwareResetFlag();
  StartSystemTimeBase(); //启动系统定时器提供系统定时和延时函数
	//初始化外设
	OutputChannel_Init(); //启动输出通道	
	ADC_Init(); //初始化ADC
	PWM_Init(); //启动PWM定时器
	LED_Init(); //初始化侧按LED
	OutputChannel_WaitVBattReady(); //输出通道和配置通道初始化之前，需要等待电池就绪
	ModeFSMInit(); //初始化挡位状态机
  SideKeyInit(); //侧按初始化	
	OutputChannel_TestRun(); //进行输出通道试运行
	DisplayVBattAtStart(1); //显示输出电压
	EnableADCAsync(); //启动ADC的异步模式提高处理速度
	//主循环	
  while(1)
		{
	  //实时处理
		SystemTelemHandler();//获取电池信息	
		SideKey_LogicHandler(); //处理侧按事务
		BatteryTelemHandler(); //处理电池遥测
		InputLimitedDetect();  //输入电流限制检测
		ModeSwitchFSM(); //挡位状态机
		ThermalMgmtProcess(); //温度管理函数过热保护等
		ApplyOutputCurrent(); //应用输出电流值
		OutputChannel_Calc(); //根据电流进行输出通道控制
		PWM_OutputCtrlHandler(); //处理PWM输出事务	
		//8Hz定时处理
		if(!SysHFBitFlag)continue; //时间没到，跳过处理
		//Task0，处理计算量比较大的任务
    if(!TaskSel)
			{
			RandStrobeHandler(); //处理伪随机爆闪任务
			ThermalPILoopCalc(); //积分器计算
			ModeFSMTIMHandler(); //模式状态机计时
			BeaconFSM_TIMHandler();	//信标模式计时器	
			LEDControlHandler();//侧按指示LED控制函数
			OCFSM_TIMHandler(); //输出通道状态机计时
			HoldSwitchGearCmdHandler(); //长按换挡
			SideKey_TIM_Callback();//侧按按键的监测定时器处理
			//处理结束，对任务选择进行翻转处理下一组
			TaskSel=1;
		  }			
		//Task1，处理计算量比较小的计时任务
		else
			{					
			OutputFaultDetect();//输出故障检测
			BattDisplayTIM(); //电池电量显示TIM
			SOSTIMHandler(); //SOS计时器
			BattAlertTIMHandler(); //电池警报定时处理
			DisplayErrorTIMHandler(); //故障代码显示
			SleepMgmt(); //休眠管理
			LocateLED_TIMHandler(); //定位LED计时
			//处理结束，对任务选择进行翻转处理下一组
			TaskSel=0;
			}
		//处理完毕，令flag清零
		SysHFBitFlag=0;	
		}
	}
/*************************  End Of File  ***********************/

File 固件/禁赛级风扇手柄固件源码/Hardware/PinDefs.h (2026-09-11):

/****************************************************************************/
/** \file PinDefs.h
/** \Author redstoner_35
/** \Project Xtern Ripper Hyper Fan Ultra Edition
/** \Description 这个文件是系统所使用的以及未使用的所有GPIO对应芯片实际管脚映射
								 的声明头文件。
**
**	History:
				2026年9月11日 Initial Release
**	
*****************************************************************************/
#ifndef _PINDEFS_
#define _PINDEFS_

/****************************************************************************/
/*	include files
*****************************************************************************/
#include "GPIOCfg.h"

/*****************************************************************************
这个区段是系统未使用IO的映射表。系统未使用的IO包括 P0.1/0.3 P1.4 P2.5 P3.2
*****************************************************************************/
#define P0UnusedPIN ((0x01<<1)|(0x01<<3))
#define P1UnusedPIN (0x01<<4)
#define P2UnusedPIN (0x01<<5)
#define P3UnusedPIN (0x01<<2)

/*****************************************************************************
以下是系统的常规GPIO引脚，用于控制外部外设切换功能以及PIN Strap读入
*****************************************************************************/

#define PinStrapIOP GPIO_PORT_1
#define PinStrapIOG 1
#define PinStrapIOx GPIO_PIN_3 //读取系统风扇配置的PIN Strap(P1.3)

#define DCDCENIOP GPIO_PORT_0
#define DCDCENIOG 0
#define DCDCENIOx GPIO_PIN_4 //风扇升压DCDC电源的使能引脚(P0.4)

#define FANPWRENIOP GPIO_PORT_0
#define FANPWRENIOG 0
#define FANPWRENIOx GPIO_PIN_2 //风扇电源输出的使能引脚(P0.2)

#define NTCENIOP GPIO_PORT_0
#define NTCENIOG 0
#define NTCENIOx GPIO_PIN_0			//NTC检测使能引脚(P0.0)

/*****************************************************************************
以下是系统的PWM输出引脚，用于对外输出PWM控制风扇速度，DCDC输出电压等等
*****************************************************************************/

#define CVDACIOP GPIO_PORT_3
#define CVDACIOG 3
#define CVDACIOx GPIO_PIN_0   //负责控制系统的输出电压调整的PWM引脚（P3.0）

#define FanPWMIOP GPIO_PORT_0
#define FanPWMIOG 0
#define FanPWMIOx GPIO_PIN_5  //负责控制4PIN PWM风扇的PWM输出引脚（P0.5）

/******************************************************************************
以下是系统的模拟输入引脚，例如电池电压测量等
******************************************************************************/
#define VBATInputIOP GPIO_PORT_3
#define VBATInputIOG 3
#define VBATInputIOx GPIO_PIN_1
#define VBATInputAIN 13					//电池电压检测引脚(P3.1,AN13)

#define NTCInputIOP GPIO_PORT_2
#define NTCInputIOG 2
#define NTCInputIOx GPIO_PIN_2 
#define NTCInputAIN 8						//NTC输入(P2.2,AN8)
/******************************************************************************
以下是系统的按键指示灯输出和按键输入引脚，负责连接到按键小板
******************************************************************************/
#define SideKeyGPIOP GPIO_PORT_2
#define SideKeyGPIOG 2
#define SideKeyGPIOx GPIO_PIN_3 	//侧按按键(P2.3)


#define RedLEDIOP GPIO_PORT_2
#define RedLEDIOG 2
#define RedLEDIOx GPIO_PIN_6		//红色指示灯(P2.6)	


#define GreenLEDIOP GPIO_PORT_2
#define GreenLEDIOG 2
#define GreenLEDIOx GPIO_PIN_4		//绿色指示灯(P2.4)


#endif /* _PINDEFS_ */

/*********************************  End Of File  ************************************/

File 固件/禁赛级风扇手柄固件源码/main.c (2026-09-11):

/****************************************************************************/
/** \file main.c
/** \Author redstoner_35
/** \Project Xtern Ripper Hyper Fan Ultra Edition
/** \Description 这个文件负责驱动系统的主函数声明
**
**	History:
				2026年9月11日 Initial Release
**	
*****************************************************************************/
/****************************************************************************/
/*	include files
*****************************************************************************/
#include "cms8s6990.h"
#include "GPIO.h"
#include "delay.h"
#include "SideKey.h"
#include "LEDMgmt.h"
#include "ADCCfg.h"
#include "PWMCfg.h"
#include "BattDisplay.h"
#include "OutputChannel.h"
#include "ModeSel.h"
#include "LowVoltProt.h"
#include "SysReset.h"
#include "Tempcontrol.h"

/****************************************************************************/
/*	function Prototype('extern')
****************************************************************************/	
void SleepMgmt(void);
void MaskUnusedIO(void);
void LoadSleepTimer(void);

/****************************************************************************/
/*	main function ('main')
****************************************************************************/	
void main()
	{
	bit TaskSel=0;
	//启动系统定时器提供系统定时和延时函数
  StartSystemTimeBase(); 
	ClearSoftwareResetFlag();
	//初始化外设
  LED_Init(); //初始化侧按LED		
	ADC_Init(); //初始化ADC
	WaitBatteryVoltageOK(); //等待电池电压稳定
	SideKeyInit(); //初始化按键控制器
	PWM_Init(); //启动PWM定时器
	OutputChannel_Init(); //初始化输出通道
	ModeFSMInit(); //初始化模式状态机
	BattCellCountConfig(); //电池节数识别处理
	ThermalSystem_Init();  //初始化温控系统
	MaskUnusedIO(); //屏蔽掉不用的IO
	DisplayVBattAtStart(1); //上电时显示电池电压	
	LoadSleepTimer();       //进入系统前加载一遍睡眠定时器
	EnableADCAsync();       //使能ADC异步模式
  //主循环
	while(1)
		{
		//实时处理	
		SystemTelemHandler();//对ADC执行采集获取系统状态
			
		//处理按键事务，如果有按键按下，则加载睡眠定时器重置休眠延时	
		SideKey_LogicHandler(); 
		if(IsKeyEventOccurred())LoadSleepTimer();	

		BatteryTelemHandler(); //处理电池遥测	
		OverHeatProtect();  //处理过热保护
		ModeSwitchFSM(); //挡位变换状态机
		TempDegDetect();  //温度降额计算
		OutputChannel_Calc(); //输出通道运算
		PWM_OutputCtrlHandler(); //处理PWM输出事务			
		//8Hz定时处理
		if(!SysHFBitFlag)continue; //时间没到，跳过处理
    if(!TaskSel)
			{
			//Task0，处理计算量比较大的任务
	    LEDControlHandler();//侧按指示LED控制函数
			SideKey_TIM_Callback();//侧按按键的监测定时器处理
			TurboTimedStepDownPROC(); //极速定时降档处理
			TempSensorStallDetect();   //处理温度检测
			SleepMgmt(); //睡眠处理
			
			//任务处理完毕，处理task 1
			TaskSel=1;
			}
		else
			{		
			//Task1，处理计算量比较小的计时任务
			BattAlertTIMHandler(); //电池警报处理
			HoldSwitchGearCmdHandler(); //长按换挡命令处理
			BattDisplayTIM(); //电池电量显示TIM
			RampConfigAutoSaveHandler(); //无级调速自动保存处理
				
			//任务处理完毕，处理task 0
			TaskSel=0;
			}
	  //处理完毕，令flag清零
		SysHFBitFlag=0;	
		}
	}
/*****************************  End Of File  ******************************/

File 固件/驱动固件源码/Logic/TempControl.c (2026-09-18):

/****************************************************************************/
/** \file TempControl.c
/** \Author redstoner_35
/** \Project Xtern Ripper Hyper Boost HV 4S-GaN Edition
/** \Description 这个文件为顶层应用层逻辑文件。负责实现系统的温度管理并在合适的
条件下限制输出功率以及强制关机，以保护系统免受过度高温影响。

**	
				2025年12月28日 12:42 1.新增在POWER模式下在电池即将耗尽，跳转到高亮继续
				                       运作前，逐步降低系统的外壳温度至高亮恒温值以避
															 切换到高亮后，系统瞬间因高温差大幅度降档导致亮
															 度瞬间跳楼一下影响用户使用体验。
														 2.修复积分器快速积分逻辑不正确，并且移除在温度误
														   差大于4度时快速升温的逻辑，以修复系统恒定亮度时
															 不稳定的问题。
														 3.针对主动散热DLC优化温控控制逻辑的参数，解决极亮
															 挡位下温度控制下冲严重的bug。
														 4.优化系统在挡位交接阶段重新计算电流值的配置使得
														   极亮在跳档至高亮时工作更稳定。
														 
				2025年12月26日 10:05 针对新的远光狗模式挡位调整温控计算暂停逻辑，以便于
														 优化系统逻辑。
														 
				2025年12月20日 Initial Release
**	
*****************************************************************************/
/****************************************************************************/
/*	include files
*****************************************************************************/
#include "ADCCfg.h"
#include "LEDMgmt.h"
#include "delay.h"
#include "ModeControl.h"
#include "TempControl.h"
#include "BattDisplay.h"
#include "OutputChannel.h"
#include "TurboICCMAX.h"
#include "PWMCfg.h"
#include "LowVoltProt.h"
#include "SelfTest.h"
#include "FastOp.h"

/****************************************************************************/
/*	Local pre-processor symbols/macros - for Parameter Definition
****************************************************************************/

//PI环参数和最小电流限制
#define ILEDRecoveryTime 90 //使用积分器缓慢升档的判断时长，如果积分器持续累加到这个时长，则执行一次调节(单位秒)
#define SlowStepDownTime 60 //使用积分器缓慢降档的判断时长，如果积分器持续累加到这个时长，则执行一次调节(单位秒)
#define IntegralCurrentTrimValue 2500 //积分器针对输出的电流修调的最大值(mA)
#define IntegralFactor 12 //积分系数(每单位=1/8秒，越大时间常数越高，6=每分钟进行40mA的调整)
#define ILEDStepDown 1500 //降档系统所能达到的最低电流(mA)
#define BatteryDynamicTurboDegFactor 20 //极亮模式下动态调节恒温温度实现无缝过渡的系数，单位(mV)系数越小，温度下降速度越快 

//常亮电流配置
#define ThermalFoldbackILEDDegVal 5500 //触发温度回折保护之后，降档系统立即减少的电流量(mA)
#define ILEDConstantGlowMin 5000 //降档系统内的低温温控的常亮电流设置(mA)
#define ILEDConstantGlowMinOverHeat 2000 //过热后普通挡位的常亮电流值(mA)
#define ILEDConstantGlowMinTurbo 12000 //降档系统内的极亮温控的常亮电流设置(mA)
#define ILEDConstantGlowMinECOTurbo 8000 //降档系统内的极亮温控（ECO模式）的常亮电流设置(mA)

//温度配置
#define ForceOffTemp 80 //过热关机温度
#define ForceDisableTurboTemp 65 //超过此温度无法进入极亮
#define TurboConstantTemperature 56 //极亮挡位的PID维持温度
#define ECOTurboConstantTemperature 52 //ECO模式下极亮挡位的PID维持温度
#define ConstantTemperature 50 //非极亮挡位温控启动后维持的温度
#define ReleaseTemperature 43 //温控释放的温度

/****************************************************************************/
/*	Local pre-processor symbols/macros for Parameter Processing and Checking
****************************************************************************/ 
#define MinumumILED CalcIREFValue(ILEDStepDown)		//最小LED电流计算
#define LeaveTurboTemperature ForceOffTemp-10   	//退出极亮温度计算
#define TurboTempDegEndTemp (ConstantTemperature+2)                  //计算极亮接近退出的温度
#define TurboVoltDeg (TurboConstantTemperature-TurboTempDegEndTemp)  //计算极亮到常亮的温度差
#define TurboTempDegEnd TurboOFFVoltage+(BatteryDynamicTurboDegFactor*TurboVoltDeg) //极亮不衰减性能的电池电压

/*   积分器满量程自动定义，切勿修改！    */
#define IntegrateFullScale IntegralCurrentTrimValue*IntegralFactor

#if (IntegrateFullScale > 32760)

#error "Error 001:Invalid Integral Configuration,Trim Value or time-factor out of range!"

#endif

#if (IntegrateFullScale <= 0)

#error "Error 002:Invalid Integral Configuration,Trim Value or time-factor must not be zero or less than zero!"

#endif

/*	温控数值监测，切勿修改！    	*/
#if (ForceOffTemp > 85)
#error "Error 003:Emergency Shutdown Temperature must not exceeded 85 Celsius!"
#endif

#if ((ForceOffTemp-15) < ForceDisableTurboTemp)
#error "Error 004:Force Disble Turbo Temperature must less than Emergency Shutdown Temperature for at least 15 Celsius!"
#endif

#if (ForceOffTemp < (TurboConstantTemperature+8))
#error "Error 005:Force Disble Turbo Temperature must higher than Constant Temperature of Turbo Mode for at least 8 Celsius!"
#endif

#if (TurboConstantTemperature <= ConstantTemperature)
#error "Error 006:Constant Temperature of Turbo Mode must lagger than Constant Temperature of other mode!"
#endif

#if (ConstantTemperature < (ReleaseTemperature+5))
#error "Error 007:Constant Temperature of other mode must lagger than Thermal Control Release Temp for 5 Celsius!"
#endif

#if (ReleaseTemperature < 38)
#error "Error 008:Thermal Control Release Temp is too low and will not release at summer!"
#elif (ReleaseTemperature < 41)
#warning "Warning 001:Thermal Control Release Temp is too low and might not be able to release at summer."
#endif

/****************************************************************************/
/*	Local variable and Flag definitions('static')
****************************************************************************/
static int TempIntegral;
static int TempProtBuf;									
static xdata unsigned char StepDownTIM;  //降档显示计时
static xdata unsigned char StepUpLockTIM; //计时器

static bit IsNearThermalFoldBack; //标记位，是否接近于退出极亮温度
static bit IsThermalStepDown; //标记位，是否降档
static bit IsTempLIMActive;  //温控是否已经启动
static bit IsSystemShutDown; //是否触发温控强制关机

/****************************************************************************/
/*	Global variable definitions(declared in header file with 'extern')
****************************************************************************/
bit IsDisableTurbo;  //禁止再度进入到极亮档
bit IsForceLeaveTurbo; //是否强制离开极亮档
bit IsPauseThermalCalc=0; //是否暂停温控计算

/****************************************************************************/
/*	Function implementation - local('static')
****************************************************************************/

//负责温度使能控制的施密特触发实现函数（滞回控制）
static bit TempSchmittTrigger(bit ValueIN,char HighThreshold,char LowThreshold)	
	{
	if(Data.Systemp>HighThreshold)return 1;
	if(Data.Systemp<LowThreshold)return 0;
	//数值保持，没有改变
	return ValueIN;
	}

//获取温控环路的恒温值
static int QueryConstantTemp(void)	
	{
	int Buf;
	if(CurrentMode->ModeIdx==Mode_Turbo)
		{
		//POWER模式下极亮的时候使用更高的温控拉长降档时间
		if(IsPowerModeEnabled)
			{
			//Power模式下为了实现和高亮挡位的温度无缝过渡，在电池电压接近极亮关断电压时，逐步降档
		  if(CellVoltage>=TurboTempDegEnd)Buf=TurboConstantTemperature;
		  else
				{
				//降档温度按照极亮关闭电压往上**mV（由温控参数定义）每℃的斜率，逐步从高温过渡到低温
				Buf=(CellVoltage-TurboOFFVoltage)/BatteryDynamicTurboDegFactor;
				if(IsNegative16(Buf))Buf=0;
				Buf+=TurboTempDegEndTemp;
				}
			return Buf;
			}
		//ECO模式使用52度温控
		else return ECOTurboConstantTemperature;
		}
	//正常使用其余挡位的温控
  return ConstantTemperature;
	}
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

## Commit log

2026-08-21 Initial Release of DFEx GT-X2
    [10灯8080铜基板.PrjPcb, 40风扇不锈钢夹片-改版.STEP, 40风扇不锈钢夹片.SLDPRT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]
2026-08-25 V1.0.0.1版本更新，新增ChangeLog，详情请查看changelog
    [GT-X2续航测试总表.xlsx, 风扇手柄固定块.SLDDRW, 风扇手柄固定块.SLDPRT]
2026-09-03 V1.1.0.0版本更新，详情请查看changelog
    [GT-X2续航测试总表.xlsx, PCB1.PcbDoc, main.SchDoc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]
2026-09-10 V1.1.0.1版本勘误更新，详情请查看readme
    [PCB1.PcbDoc, X2电池保护板-BOM.xlsx, main.SchDoc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]
2026-09-11 V1.1.0.2版本更新，详情请查看changelog
2026-09-18 V1.1.0.3版本更新，详情请查看changelog
    [GT-X2续航测试总表.xlsx]
2026-09-21 V1.1.0.4版本更新，详情请查看changelog
    [21700电池.SLDPRT, 上端电池接触点.SLDPRT, 下端电池接触板.SLDPRT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]
2026-10-08 V1.1.0.5版本更新 详情请查看changelog
    [40风扇尼龙.STEP, 40风扇尼龙外框.SLDPRT, PCB2.PcbDoc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]
2026-10-09 V1.1.0.6版本更新，详情请查看changelog
    [中心铜柱不锈钢螺丝.SLDPRT, 保护板下部1.0厚EPDM垫圈.DWG, 充电板PCB.SLDPRT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]
